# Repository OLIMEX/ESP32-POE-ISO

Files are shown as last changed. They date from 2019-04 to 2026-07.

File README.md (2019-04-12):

# ESP32-POE-ISO

ESP32-PoE-ISO is an IoT WIFI/BLE/Ethernet development board with Power-Over-Ethernet feature. The Si3402-B chip is IEEE 802.3-compliant, including pre-standard (legacy) PoE support. Perfect solution for Internet-of-Things that can be expanded with sensors and actuators taking power from Ethernet cable.

ESP32-POE-ISO has 3000VDC galvanic insulation from the Ethernet.

Product page: https://www.olimex.com/Products/IoT/ESP32/ESP32-POE-ISO/open-source-hardware

LICENSEE:

ESP32-POE-ISO is Open Source Hardware as per OSHWA.org definition. It is distributed with CERN OSH Licensee v1.2 which is available in the root directory of this repository.

The software examples for ESP32-POE-ISO are distributed with GPL v3 Licensee.

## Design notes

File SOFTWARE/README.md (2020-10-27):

The demo examples for ESP32-POE-ISO and ESP32-POE are the same. Visit the SOFTWARE page of ESP32-POE for examples. Here:

https://github.com/OLIMEX/ESP32-POE/tree/master/SOFTWARE/

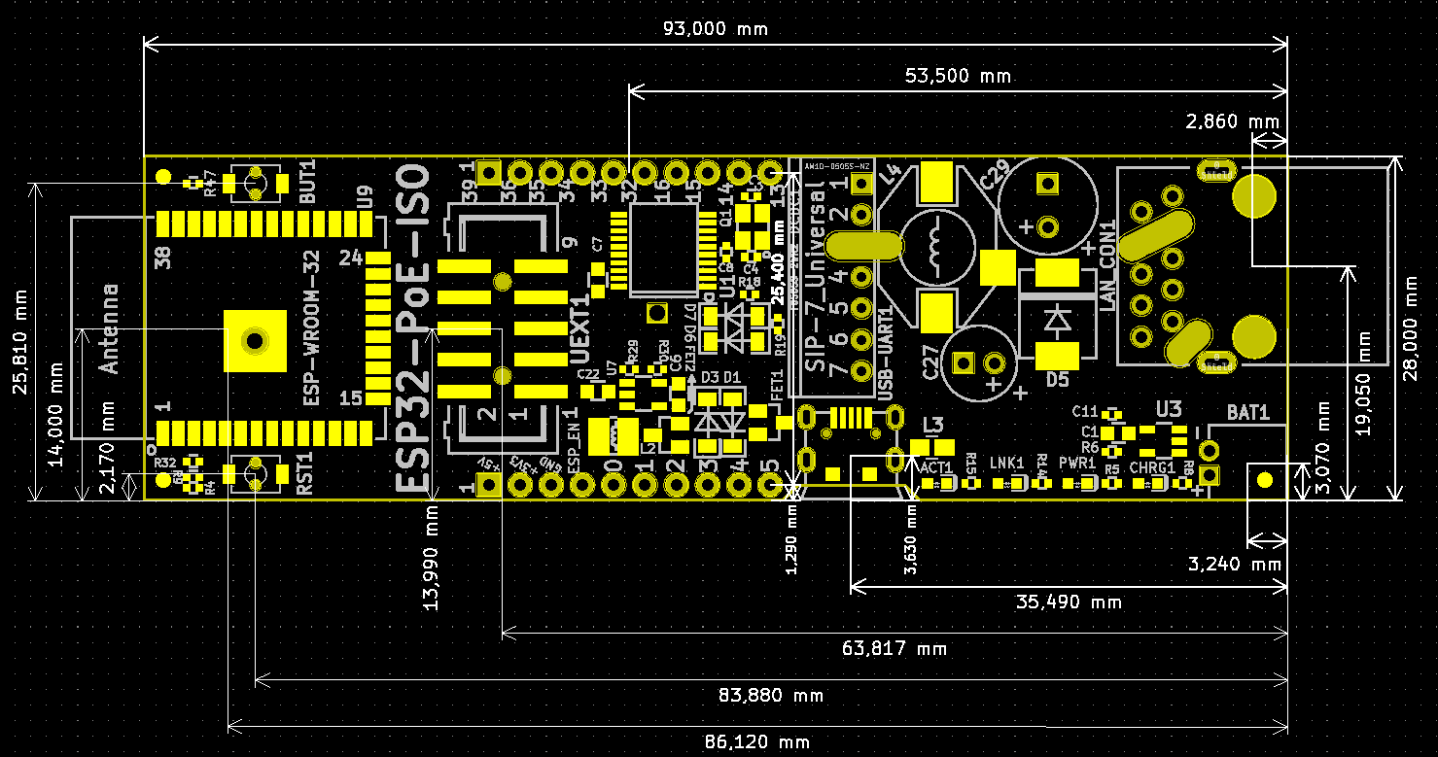
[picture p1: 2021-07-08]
HARDWARE/Dimensions/poe-iso-dimensions-1.png

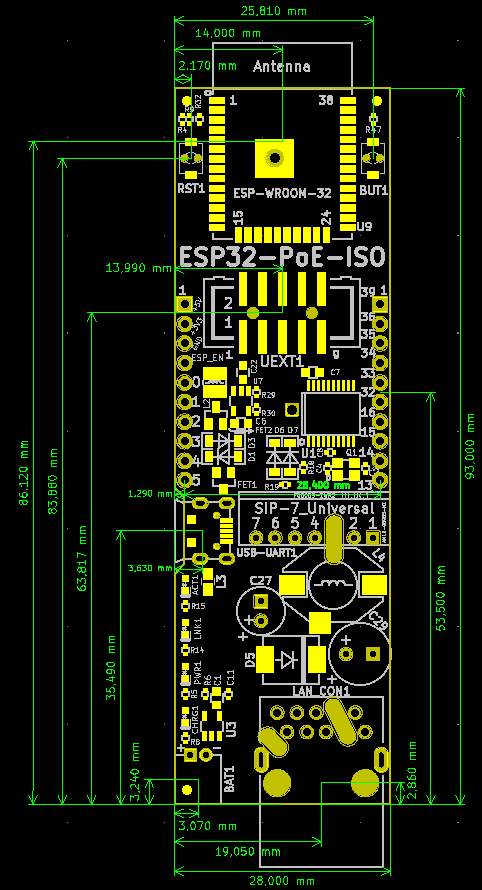
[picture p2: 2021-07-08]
HARDWARE/Dimensions/poe-iso-dimensions-2.png

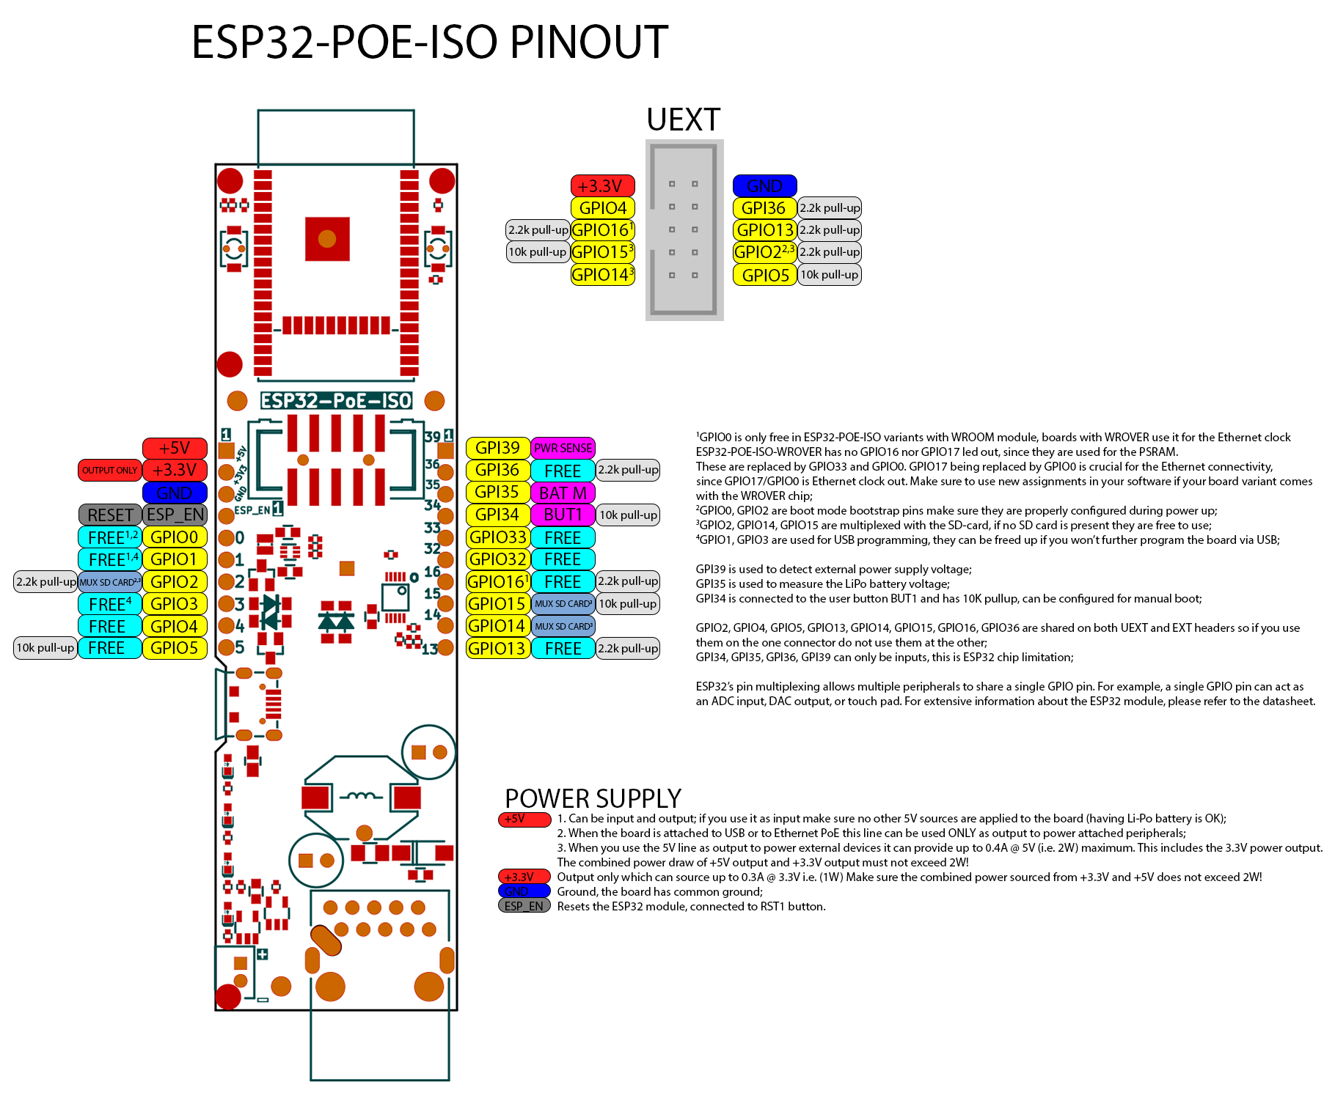
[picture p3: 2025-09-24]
DOCUMENTS/ESP32-POE-ISO-PINOUT.png

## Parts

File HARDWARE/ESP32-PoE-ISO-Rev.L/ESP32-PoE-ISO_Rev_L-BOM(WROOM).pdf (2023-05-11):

ESP32-PoE-ISO_Rev_L-BOM(WROOM) | 10/10/2022
Quantity | Designation | Package | Designator
1 | 0.03R/1%/R1206 | R1206 | R28
1 | 4.7R/R0402 | R0402 | R33
1 | 10R/R0402 | R0402 | R40
4 | 49.9R/1%/R0402 | R0402 | R10,R11,R12,R13
3 | 220R/R0402 | R0402 | R24,R46,R47
3 | 1k/R0402 | R0402 | R3,R20,R21
6 | 2.2k/R0402 | R0402 | R5,R8,R14,R15,R31,R35
3 | RA1206_(4X0603)_4B8_2.2k | R1206 | RM1,RM2,RM3
1 | 4.42k/1%/1/16W/R0402 | R0402 | R27
1 | 4.7k/R2512 | R2512 | R41
12 | 10k/R0402 | R0402 | R1,R2,R6,R18,R19,R25, R32,R36,R37,R39,R44,R48
1 | 10.5k/1%/R0402 | R0402 | R34
1 | 12.1k/1%/R0402 | R0402 | R26
1 | 24.9k/1%/R0402 | R0402 | R22
1 | 47k/R0402 | R0402 | R4
1 | 49.9k/1%/R0402 | R0402 | R30
1 | 56.2k/1%/R0402 | R0402 | R38
1 | 100k/R0402 | R0402 | R9
1 | 130k/R0402 | R0402 | R43
1 | 180k/1%/R0402 | R0402 | R23
1 | 220k/R0402 | R0402 | R29
2 | 470k/R0402 | R0402 | R7,R16
3 | FB0805/600R/2A | L0805 | L1,L3,L5
1 | 2.2uH/1.5A/DCR=72mR/ 20%/3.00x3.00x1.50mm/ CD32(NR3015T2R2M) | CD32 | L2
1 | 33uH/2.1A/DCR=0.1R/20%/ DBS135(PD3316MT330) | DBS135 | L4
1 | 12pF/50V/5%/COG/C0402 | C0402 | C25
2 | 27pF/50V/5%/C0G/C0402 | C0402 | C4,C5
1 | 1nF/50V/10%/X7R/C0402 | C0402 | C28
1 | 1nF/2000V/10%/X7R/C1206 | C1206 | C2
1 | 1.0nF/3kV/10%/X7R/SMD/1808 (VISHAY-VJ1808Y102KBHAT4X_ Farnell-2407291) | C1808 | C23
6 | 100nF/16V/10%/X7R/C0402 | C0402 | C8,C11,C14,C15, C16,C18
2 | 100nF/100V/10%/X7R/C0603 | C0603 | C12,C24
1 | 1uF/10V/20%/X5R/C0603 | C0603 | C31
1 | 2.2uF/6.3V/10%/X5R/C0603 | C0603 | C17
1 | 15uF/100V/20%/RM2.5/6.3x11mm (Farnell:1281844) | CPOL-RM2.5mm_ 6.3x11mm_PTH | C27
8 | 22uF/6.3V/20%/X5R/C0603 | C0603 | C1,C6,C7,C9,C10, C13,C19,C22
1 | 47uF/6.3V/20%/X5R/C0805 | C_0805_5MIL_DWS | C3
1 | 470uF/10V/20%/Low_ESR/ RM2.5/6.0x11mm | CPOL-RM2.5mm_ 6.3x11mm_PTH | C26
1 | BAT54C(SOT23-3) | SOT23-3 | D2
6 | 1N5819S4/SOD123 | SOD-123 | D1,D3,D4,D6,D7,D9
1 | ESDS314DBVR(SOT-23-5) | SOT-23-5 | TVS1
1 | SMAJ58A/SMA | SMA-KA | D10

ESP32-PoE-ISO_Rev_L-BOM(WROOM) | 10/10/2022
1 | SS510/100V/5A/0.85V/ DO214AB(SMC) | DO214AB(SMC) | D5
1 | LED/RED/0603 | LED0603 | PWR1
1 | LED/GREEN/0603 | LED0603 | LNK1
2 | LED/YELLOW/0603 | LED0603 | ACT1,CHRG1
2 | BC817-40(SOT23) | SOT23 | Q2,Q3
1 | LMUN2211LT1G(SOT-23) | SOT23 | T1
3 | WPM2015-3/TR | SOT23 | FET1,FET2,FET3
1 | BL4054B-42TPRN(SOT23-5) | SOT-23-5 | U3
1 | CH340T(SSOP20W) | SSOP-20W | U1
1 | ESP32-WROOM-32E | ESP32-WROVER(WROOM)-UNIVERSAL_MODULE | U6
1 | F0505S-2WR2(SIP-7) | SIP-7_Universal | DCDC1
1 | LAN8710A-EZC(QFN32) | QFN32 | U4
1 | SY8089AAAC(SOT23-5) | SOT-23-5 | U7
1 | Q12MHz/20pF/10ppm/4P/3.2x2.5mm | TSX-3.2x2.5mm | Q1
1 | TPS2376D(SO-8) | SOIC-8 | U2
1 | TX4138(ESOIC-8) | ESOIC-8 | U5
2 | IT1185AU2 | IT1185AU2 | BUT1,RST1
1 | DW02S | DW02S | BAT1
1 | MISB-SWMM-5B-LF(USB_MICRO) | MISB-SWMM-5B_LF | USB-UART1
1 | P-B-V-10-LF | GBH-254-SMT-10 | UEXT1
1 | RJP-003TC1(LPJ4112CNL) | RJP-003TC1(LPJ4112CNL) | LAN_CON1
1 | TFC-9P-1.7H(ATFFS150A01BR016) | uSD(TFC-9P-1.xH (ATFFS150A01BR016)) | MICRO_SD1
2 | NA/R0402 | R0402 | R17,R49
1 | NA(10R/R0402) | R0402 | R42
1 | NA(1.0nF/3kV/10%/X7R/SMD/1808 (VISHAY-VJ1808Y102KBHAT4X_ Farnell-2407291)) | C1808 | C20
1 | NA(100nF/16V/10%/X7R/C0402) | C0402 | C29
1 | NA(10uF/6.3V/20%/X5R/C0603) | C0603 | C21
2 | NA(GG0402052R542P) | D0402 | TVS2,TVS3
1 | NA(SMBJ6.0A) | DO214AA | D8
1 | NA(SN74LVC1G04DBVR(SOT23-5)) | SOT-23-5 | U8
2 | NS(HN1x10) | HN1x10 | EXT1,EXT2

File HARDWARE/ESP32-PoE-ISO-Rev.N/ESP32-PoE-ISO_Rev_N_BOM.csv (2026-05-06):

Id | Designator | Footprint | Quantity | Designation | Supplier and ref
1 | FID3,FID2,FID6,FID5 | Fiducial1x3 | 4 | Fiducial
2 | R32,R6,R18,R19,R48,R37,R39,R2,R25,R1,R36 | R_0402_5MIL_DWS | 11 | 10k/R0402
3 | BUT1,RST1 | IT1185AU2_V2 | 2 | IT1185AU2
4 | C1,C6,C22,C7,C19,C10,C9,C13 | C_0603_5MIL_DWS | 8 | 22uF/6.3V/20%/X5R/C0603
5 | U3 | SOT-23-5 | 1 | TP4054-42-SOT25-R(SOT23-5)
6 | R4 | R_0402_5MIL_DWS | 1 | 47k/R0402
7 | R9 | R_0402_5MIL_DWS | 1 | 100k/R0402
8 | CHRG1,ACT1 | LED_0603_KA | 2 | LED/YELLOW/0603
9 | PWR1 | LED_0603_KA | 1 | LED/RED/0603
10 | R5,R14,R15,R8,R31,R35 | R_0402_5MIL_DWS | 6 | 2.2k/R0402
11 | FID1,FID7,FID4,FID8 | Fiducial1x3_Paste | 4 | Fiducial
12 | C11,C8,C18,C16,C15,C14 | C_0402_5MIL_DWS | 6 | 100nF/10V/20%/X5R/C0402
13 | FET1,FET2,FET3 | SOT23 | 3 | IRLML6402TRPbF
14 | L2 | L_2016_MM | 1 | 1.0uH/4.2A/DCR=35mR/20%/2.00x1.60x1.00mm/L2016(PIM201610-1R0MTS00)
15 | R30 | R_0402_5MIL_DWS | 1 | 49.9k/1%/R0402
16 | R29 | R_0402_5MIL_DWS | 1 | 220k/R0402
17 | U7 | SOT-563-6 | 1 | TPS62A02ADRLR(SOT-563-6)
18 | LNK1 | LED_0603_KA | 1 | LED/GREEN/0603
19 | L3,L5,L1 | L_0805_5MIL_DWS | 3 | FB0805/600R/2A
20 | DCDC1 | SIP-7_Universal | 1 | F0505S-2WR2(SIP-7)
21 | C27 | CPOL-RM2.5mm_6.3x11mm_PTH | 1 | 15uF/100V/20%/RM2.5/6.3x11mm(Farnell:1281844)
22 | U1 | MSOP-10_Pitch-0.5mm_3.00x3.00x1.00mm | 1 | CH340X(MSOP-10)
23 | D6,D7,D3,D1,D4,D9 | SOD-123_1C-2A_KA | 6 | 1N5819S4/SOD123
24 | R17,R49 | R_0402_5MIL_DWS | 2 | NA/R0402
25 | USB-UART1 | USB-MICRO_MISB-SWMM-5B_LF | 1 | MISB-SWMM-5B-LF(USB_MICRO)
26 | TVS1 | SOT-23-5 | 1 | ESDS314DBVR(SOT-23-5)
27 | LAN_CON1 | RJP-003TC1(LPJ4112CNL) | 1 | RJP-003TC1(LPJ4112CNL)
28 | UEXT1 | GBH-254-SMT-10 | 1 | P-B-V-10-LF
29 | R28 | R_1206_5MIL_DWS | 1 | 0.03R/1%/R1206
30 | L4 | DBS135 | 1 | 33uH/2.1A/DCR=0.1R/20%/DBS135(PD3316MT330)
31 | C26 | CPOL-RM2.5mm_6.3x11mm_PTH | 1 | 470uF/10V/20%/Low_ESR/RM2.5/6.0x11mm
32 | R47,R46,R24,R44 | R_0402_5MIL_DWS | 4 | 220R/R0402
33 | C24,C12 | C_0603_5MIL_DWS | 2 | 100nF/100V/10%/X7R/C0603
34 | D10 | SMA-KA | 1 | SMAJ58A/SMA
35 | U6 | ESP32-WROVER_MODULE | 1 | ESP32-WROOM-32E-N4
36 | MH1,MH2,MH3 | NPTH_2.2mm | 3 | Mounting_Hole_NPTH
37 | BAT1 | LIPO_BAT_VERTICAL_DW02S | 1 | DW02S
38 | R43 | R_0402_5MIL_DWS | 1 | 4.7k/R0402
39 | C30 | C_0402_5MIL_DWS | 1 | NA(120pF/50V/5%/C0G/C0402)
40 | EXT2,EXT1 | HN1x10 | 2 | NS(HN1x10)
41 | R40 | R_0402_5MIL_DWS | 1 | 10R/R0402
42 | RM3,RM2,RM1 | R_MATRIX_4 | 3 | RA1206_(4X0603)_4B8_2.2k
43 | C2 | C_1206_5MIL_DWS_ISO | 1 | 1nF/2000V/10%/X7R/C1206
44 | C20 | C_1808(4520)_5MIL_DWS_ISO | 1 | NA(1.0nF/3kV/10%/X7R/SMD/1808(VISHAY-VJ1808Y102KBHAT4X_Farnell-2407291))
45 | C23 | C_1808(4520)_5MIL_DWS_ISO | 1 | 1.0nF/3kV/10%/X7R/SMD/1808(VISHAY-VJ1808Y102KBHAT4X_Farnell-2407291)
46 | R3,R20,R21 | R_0402_5MIL_DWS | 3 | 1k/R0402
47 | C21 | C_0603_5MIL_DWS | 1 | NA(10uF/6.3V/20%/X5R/C0603)
48 | C17 | C_0603_5MIL_DWS | 1 | 2.2uF/6.3V/10%/X5R/C0603
49 | U4 | QFN32_EP(33)_5.00x5.00x0.90mm_Pitch_0.50mm | 1 | LAN8710A-EZC(QFN32)
50 | T1 | SOT23 | 1 | LMUN2211LT1G(SOT-23)
51 | R12,R11,R10,R13 | R_0402_5MIL_DWS | 4 | 49.9R/1%/R0402
52 | R16,R7 | R_0402_5MIL_DWS | 2 | 470k/R0402
53 | R26 | R_0402_5MIL_DWS | 1 | 12.1k/1%/R0402
54 | Q3,Q2 | SOT23 | 2 | BC817-40(SOT23)
55 | D2 | SOT23-3 | 1 | BAT54C(SOT23-3)
56 | TVS2,TVS3 | D_0402_5MIL_DWS | 2 | NA(GG0402052R542P)
57 | C3 | C_0805_5MIL_DWS | 1 | 47uF/6.3V/20%/X5R/C0805
58 | D8 | DO214AA_1(K)-2(A) | 1 | NA(SMBJ6.0A)
59 | C25 | C_0402_5MIL_DWS | 1 | 12pF/50V/5%/COG/C0402
60 | R22 | R_0402_5MIL_DWS | 1 | 24.9k/1%/R0402
61 | R23 | R_0402_5MIL_DWS | 1 | 1.27k/1%/62.5mW/R0402
62 | C28 | C_0402_5MIL_DWS | 1 | 1nF/50V/10%/X7R/C0402
63 | R33 | R_0402_5MIL_DWS | 1 | 4.7R/R0402
64 | D5 | DO214AB(SMC)_1(K)-2(A) | 1 | SS510/100V/5A/0.85V/DO214AB(SMC)
65 | R41,R27 | R_2512_MM_DWS | 2 | 9.1k/1W/R2512
66 | U5 | ESOIC-8 | 1 | TX4138(ESOIC-8)
67 | R34 | R_0402_5MIL_DWS | 1 | 10.5k/1%/R0402
68 | C29 | C_0402_5MIL_DWS | 1 | NA(100nF/10V/20%/X5R/C0402)
69 | U8 | SOT-23-5 | 1 | NA(SN74LVC1G04DBVR(SOT23-5))
70 | R42 | R_0402_5MIL_DWS | 1 | NA(10R/R0402)
71 | C31 | C_0603_5MIL_DWS | 1 | 1uF/10V/10%/X5R/C0603
72 | MICRO_SD1 | uSD(TFC-9P-1.xH(ATFFS150A01BR016)) | 1 | TFC-9P-1.7H(ATFFS150A01BR016)
73 | R38 | R_0402_5MIL_DWS | 1 | 56.2k/1%/R0402
74 | U2 | ESOIC-8 | 1 | TPS2378DDAR(HSOIC-8)
75 | D11 | DO214AA_1(K)-2(A) | 1 | SMBJ5.0A

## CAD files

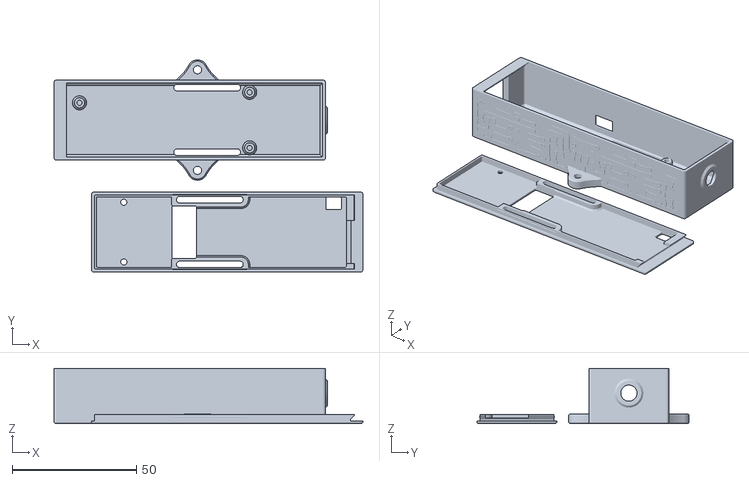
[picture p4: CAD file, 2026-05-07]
HARDWARE/3D printed case/esp32-poe-iso-ea-f_v12.stl
124.2 x 85.3 x 22.3

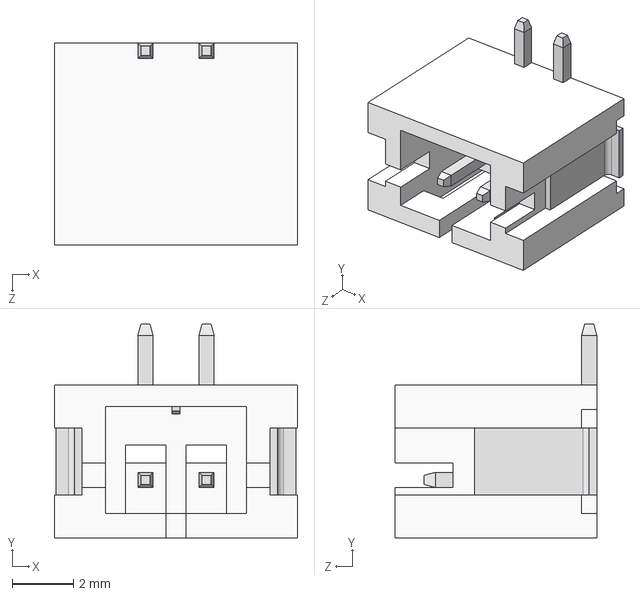
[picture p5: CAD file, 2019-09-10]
HARDWARE/ESP32-PoE-ISO-Rev.I/3d/JST_B2B-PH-SM4-TB(DW02R).step
7.95 x 7.00 x 6.60 mm

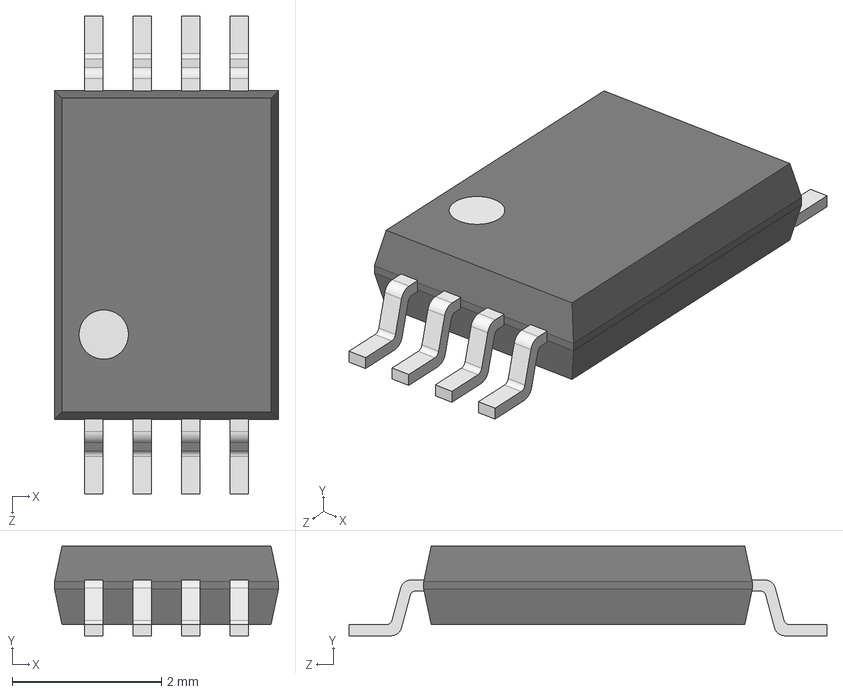
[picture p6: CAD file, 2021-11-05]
HARDWARE/ESP32-PoE-ISO-Rev.J/3d/TSSOP-8_P0.65mm.STEP
3.00 x 1.20 x 6.40 mm
_X2_041A043E0440043F04430441_X0_
_X2_041C04350442043A0430_X0_
_X2_041D043E0436043A0430_X0_ x 4

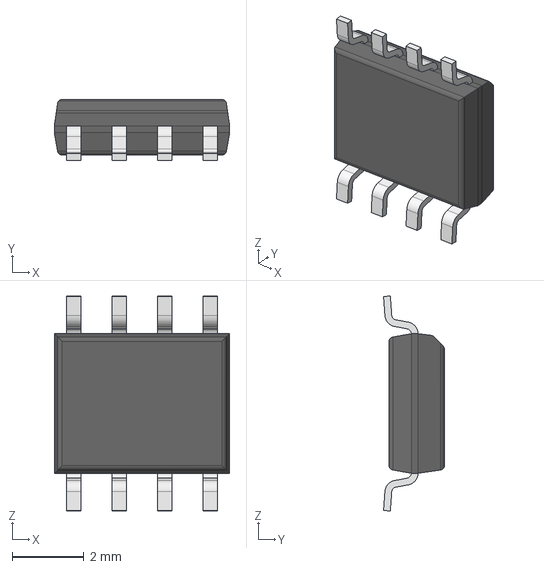
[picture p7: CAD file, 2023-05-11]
HARDWARE/ESP32-PoE-ISO-Rev.L/3d/lm358ad.stp
4.90 x 1.70 x 6.01 mm

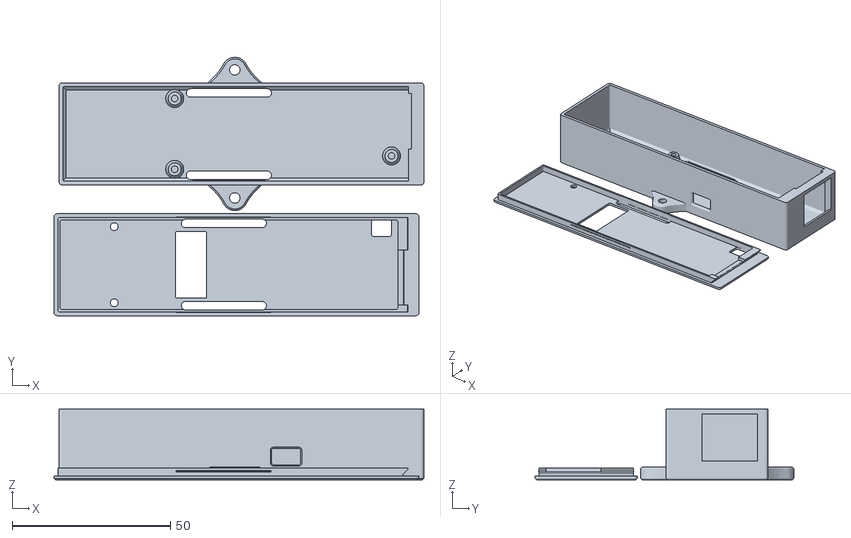
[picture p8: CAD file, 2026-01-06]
HARDWARE/3D printed case/olimex_esp32-Poe_iso_f.stl
116.7 x 81.6 x 22.3

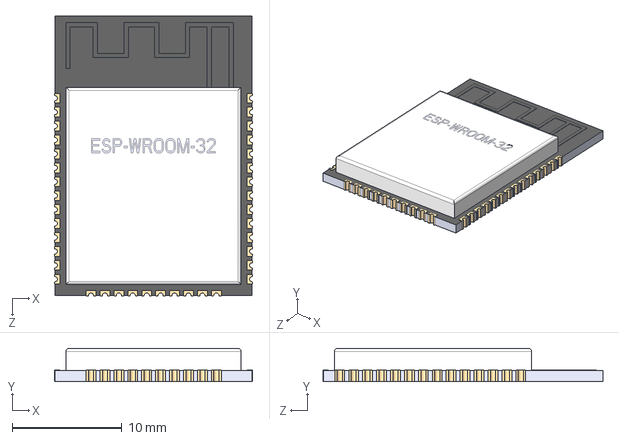
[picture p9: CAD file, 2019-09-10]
HARDWARE/ESP32-PoE-ISO-Rev.I/3d/esp-wroom-32.step
18.1 x 3.04 x 25.5 mm

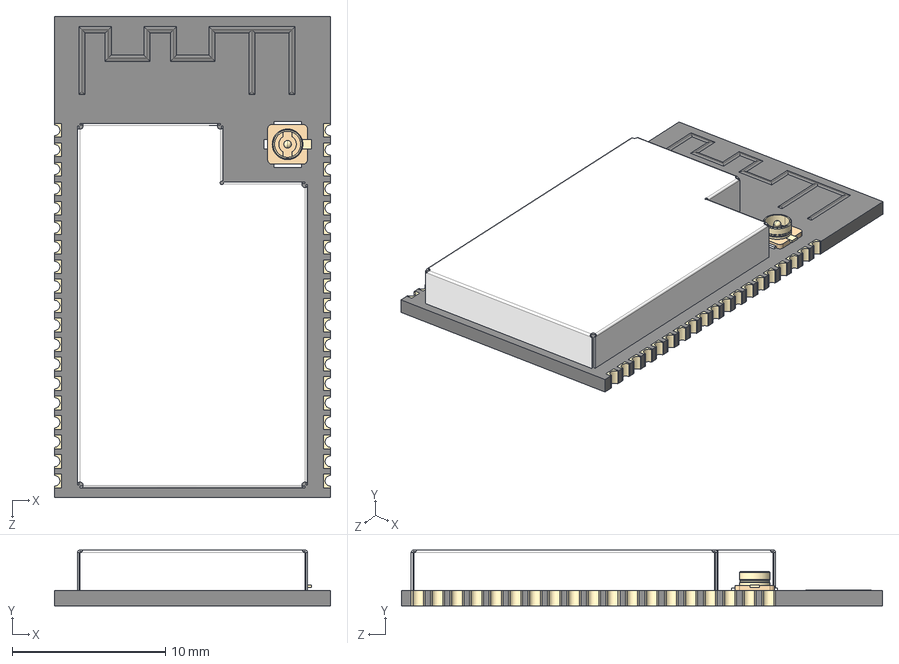
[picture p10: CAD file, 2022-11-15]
HARDWARE/ESP32-PoE-ISO-Rev.L/3d/ESP32-WROVER-I-56544.STEP
18.0 x 3.65 x 31.4 mm

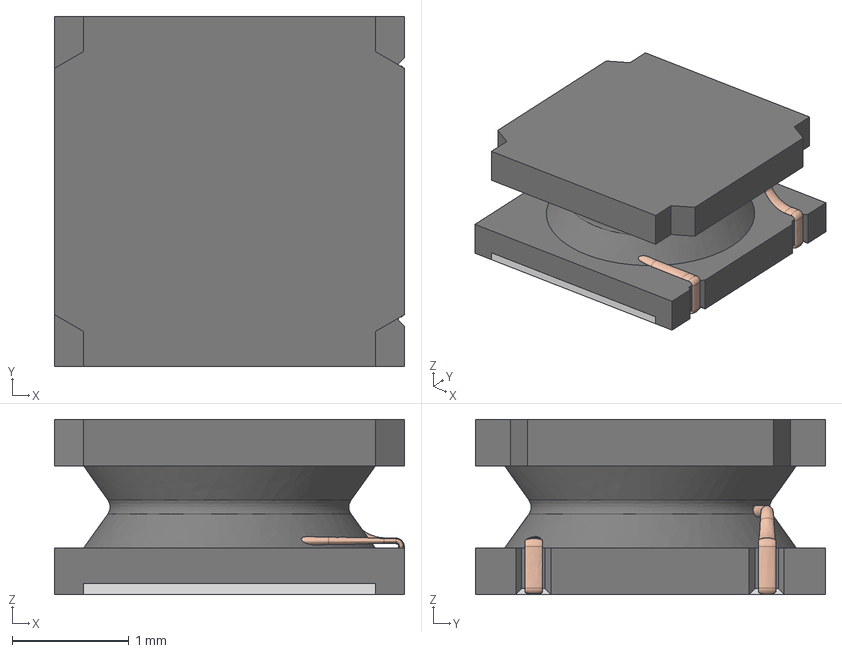
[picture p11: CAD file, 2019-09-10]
HARDWARE/ESP32-PoE-ISO-Rev.L/3d/L-CD32_shielded.step
3.00 x 3.00 x 1.50 mm

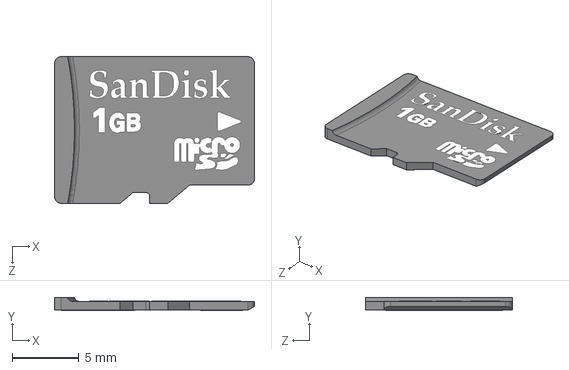
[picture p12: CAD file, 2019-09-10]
HARDWARE/ESP32-PoE-ISO-Rev.L/3d/Micro_SD_card.step
15.0 x 0.975 x 11.0 mm

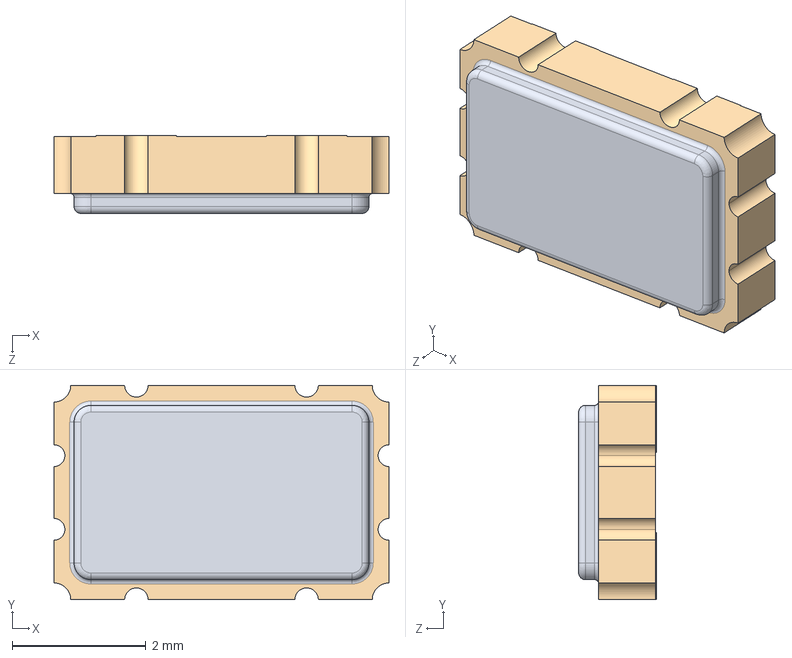
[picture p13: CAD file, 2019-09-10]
HARDWARE/ESP32-PoE-ISO-Rev.L/3d/QSG5032.step
5.00 x 3.20 x 1.16 mm

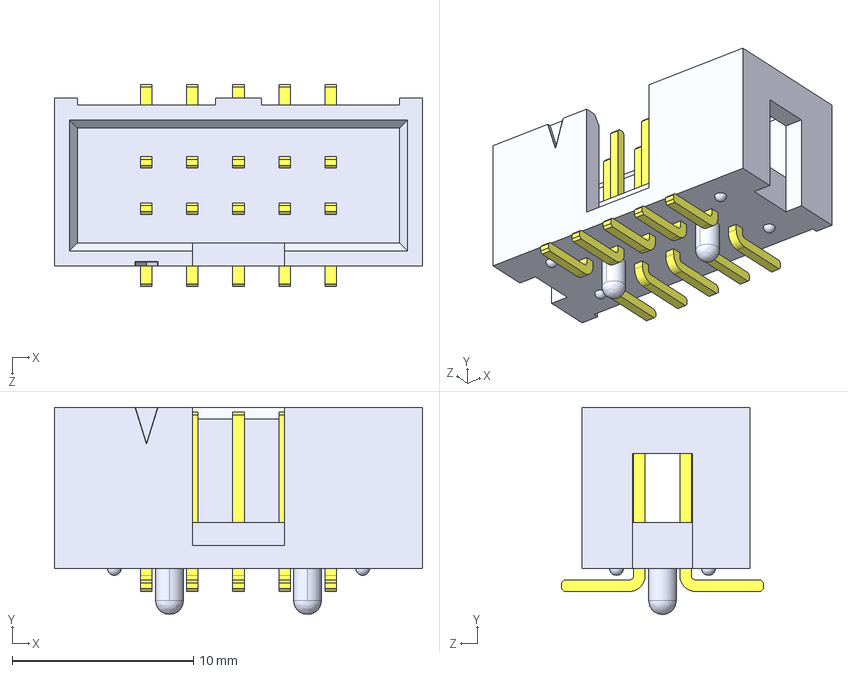
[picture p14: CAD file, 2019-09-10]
HARDWARE/ESP32-PoE-ISO-Rev.L/3d/UEXT-SMD.STEP
20.3 x 11.4 x 11.2 mm
User Library-HTST-105-01-F-DV-A__HTST-105-01-DV-A_header
User Library-HTST-105-01-F-DV-A__HTST-First_Position_Indicator
User Library-HTST-105-01-F-DV-A__T-1S6-05-01-DV_

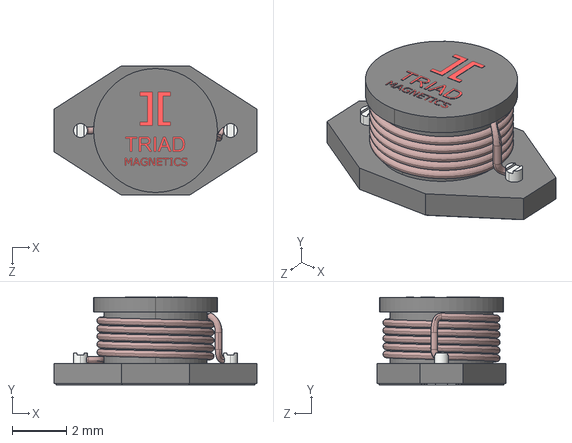
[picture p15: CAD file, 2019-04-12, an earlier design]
HARDWARE/ESP32-PoE-ISO-Rev.B/3d/L_AX97-103R3.step
7.49 x 3.24 x 4.78 mm

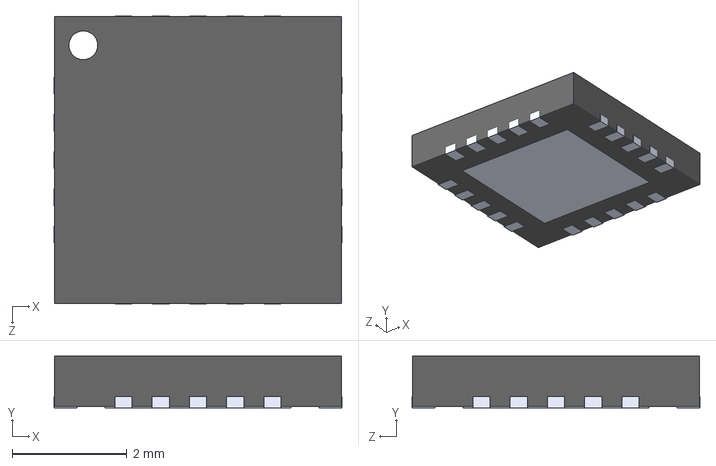
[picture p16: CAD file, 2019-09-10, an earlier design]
HARDWARE/ESP32-PoE-ISO-Rev.D/3d/QFN-20_5x5x0_9mm.step
5.02 x 0.9 x 5.02 mm

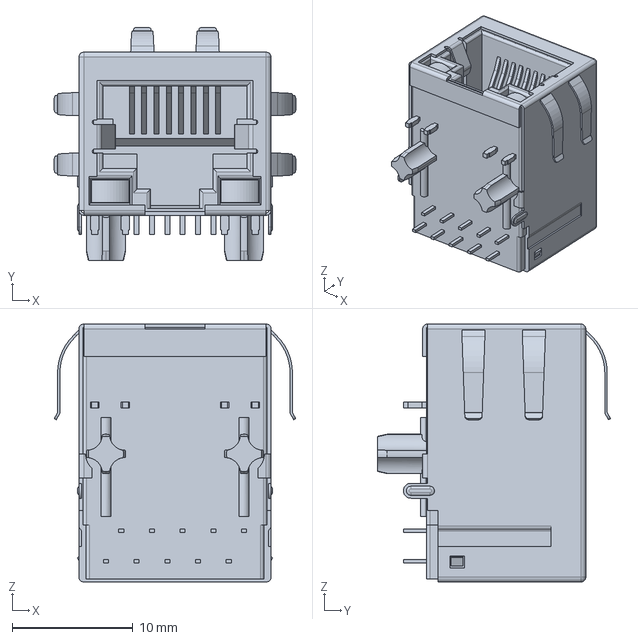
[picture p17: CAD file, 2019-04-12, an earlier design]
HARDWARE/ESP32-PoE-ISO-Rev.B/3d/RJ45_GB_LEDS.stp
20.0 x 19.3 x 21.4 mm

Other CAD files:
HARDWARE/ESP32-PoE-ISO-Rev.D/3d/Cap_8x11_5x3_5mm.step
HARDWARE/ESP32-PoE-ISO-Rev.B/3d/SOT-23-5.step
HARDWARE/ESP32-PoE-ISO-Rev.B/3d/Cap_PTH_6_3x11x2_5mm.step
HARDWARE/ESP32-PoE-ISO-Rev.B/3d/BAT54.step
HARDWARE/ESP32-PoE-ISO-Rev.B/3d/CD32_inductor.step
HARDWARE/ESP32-PoE-ISO-Rev.B/3d/Cap_8x11_5x3_5mm.step
HARDWARE/ESP32-PoE-ISO-Rev.B/3d/DO-214AB_SMC.step
HARDWARE/ESP32-PoE-ISO-Rev.B/3d/JST_B2B-PH-SM4-TB(DW02R).step
HARDWARE/ESP32-PoE-ISO-Rev.B/3d/Micro_SD_card.step
HARDWARE/ESP32-PoE-ISO-Rev.B/3d/QFN-20_5x5x0_9mm.step
HARDWARE/ESP32-PoE-ISO-Rev.B/3d/QFN32_5x5.step
HARDWARE/ESP32-PoE-ISO-Rev.B/3d/QSG5032.step
HARDWARE/ESP32-PoE-ISO-Rev.B/3d/SIP-7.step
HARDWARE/ESP32-PoE-ISO-Rev.B/3d/SMD_Ceramic_Capacitors_1808(4520).step
HARDWARE/ESP32-PoE-ISO-Rev.B/3d/SOD123.step
HARDWARE/ESP32-PoE-ISO-Rev.B/3d/SOT-23.step
HARDWARE/ESP32-PoE-ISO-Rev.B/3d/UEXT-SMD.STEP
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

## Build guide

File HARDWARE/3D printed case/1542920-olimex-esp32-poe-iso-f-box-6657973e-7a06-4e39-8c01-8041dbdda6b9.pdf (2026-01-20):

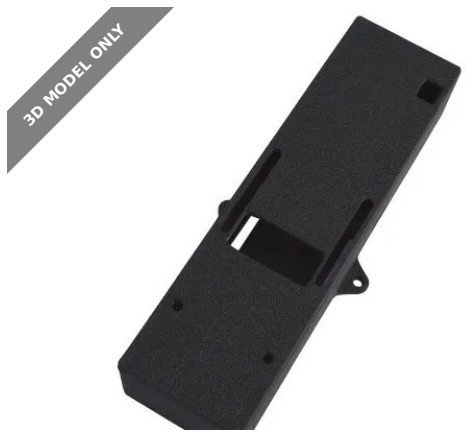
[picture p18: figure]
3D MODEL ONLY

## Summary

Plastic box for ESP32-POE-ISO

Gadgets (https://printables.com/model?categoryId=21) > Computers (https://printables.com/model?categoryId=27)

Tags: | olimex | olimexesp32 | olimexpoeiso

BOX-ESP32-POE-ISO-F has two fixing lugs which allow 3 mm screws to fix the box to a flat surface. Suitable for ESP32-POE-ISO, ESP32-POE-ISO-16MB, ESP32-POE-ISO-16MB-IND, and ESP32-POE-ISO-IND.

Print in PLA Black Matt for best results.

3 walls, 4 top and 4 bottom layers
0.2 layer height

Link to the ESP32 board: https://www.olimex.com/Products/IoT/ESP32/ESP32-POE-ISO/open-source-hardware (https://www.olimex.com/Products/IoT/ESP32/ESP32-POE-ISO/open-source-hardware)

Link to the box page: https://www.olimex.com/Products/IoT/ESP32/BOX-ESP32-POE-ISO/ (https://www.olimex.com/Products/IoT/ESP32/BOX-ESP32-POE-ISO/)

Link to the github page of the project: https://github.com/OLIMEX/ESP32-POE-ISO (https://github.com/OLIMEX/ESP32-POE-ISO)

experify3d (https://printables.com/@experify3d_271079)

## Olimex ESP32-POE-ISO-F box

VIEW IN BROWSER (https://printables.com/model/1542920-olimex-esp32-poe-iso-f-box)

updated 5. 1. 2026 | published 5. 1. 2026

•
•

## Model files

## License

This work is licensed under a GNU

General Public License v3.0 (https://www.gnu.org/licenses/gpl-3.0.html)

✖ | Sharing without ATTRIBUTION
✔ | Remix Culture allowed
✔ | Commercial Use
✔ | Meets Open Definition
ℹ | Share under the same license olimex_esp32-poe_iso_f.stl

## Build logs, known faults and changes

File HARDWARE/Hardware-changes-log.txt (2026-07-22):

Notable hardware changes for ESP32-PoE-ISO

Hardware revision N1:

---

Overview: CH340X patch to prevent accidental overvoltage at reset. The board uses same PCB as revision N just has manually applied patch.

Notable changes:

1. Added a patch to prevent overvoltage of CH340 convertor. Added resistor 10k/1206 over the RXD pin of CH340 to GND. The patch is near D7.

Hardware revision N:

---

Overview: reliability improvements

Notable changes:

1. Added D11 to protect C26 (it was a hardware patch applied in M1, now fixed by design);
2. Moved a couple of components to fit D11 - DCDC1, L4, C27, C26, R1, C19;
3. Added R44(220R) between PG of the 3.3V regulator and ESP_EN so it works better at power up and reset, this was suggested by a customer;
4. Moved U2 20mils towards the center of the board. Changed the placement of the isolated part of the circuit components to fit for the U2 new place.

Hardware revision M1:

---

Overview: reliability improvements

Notable changes:

1. WPM2015-3/TR changed with IRLML6402TRPbF;

2. Added D11-SMBJ5.0A as patch, this will increase reliability.

Hardware revision M:

---

Overview: major changes

Notable changes:

1. The entire project was converted from KiCad5 to KiCad7!
2. U3 value changed from BL4054B-42TPRN(SOT23-5) to TP4054-42-SOT25-R(SOT23-5);
3. U7 changed from SY8089AAAC(SOT23-5) to TPS62A02ADRLR(SOT-563-6);
4. Added C30 - NA(120pF/50V/5%/C0G/C0402);
5. L2 changed from 2.2uH/1.5A/DCR=72mR/20%/3.00x3.00x1.50mm/CD32(NR3015T2R2M) to 1.0uH/4.2A/DCR=35mR/20%/2.00x1.60x1.00mm/L2016(PIM201610-1R0MTS00);
6. U2 changed from TPS2376D(SO-8) to TPS2378DDAR(HSOIC-8);
7. Deleted R27, 4.42k/1%/1/16W/R0402;
8. R23 changed from 180k/1%/R0402 to 1.27k/1%/62.5mW/R0402;
9. Deleted R43, 130k/R0402;
10. Deleted R44, 10k/R0402;
11. R41 value changed from 4.7k/R2512 to 9.1k/1W/R2512;
12. R27, 9.1k/1W/R2512, was added in parallel to R41;
13. Description for Rmps was added in the schematic;
14. U1 was changed from CH340T(SSOP20W) to CH340X(MSOP-10);
15. C4 and C5, 27pF/50V/5%/C0G/C0402, were deleted;
16. Q1, Q12MHz/20pF/10ppm/4P/3.2x2.5mm, was deleted;
17. Added R43, 4.7k/R0402;
18. Several texts improved;
19. U6's package was changed from "OLIMEX_Cases-FP:ESP32-WROVER(WROOM)-UNIVERSAL_MODULE" to "OLIMEX_Cases-FP:ESP32-WROVER_MODULE" for here the pads are corrected;
20. All packages are with updated 3Ds to the ones in step format instead of wrl format.

Hardware revision L:

---

Overview: minor change

Notable changes:

1. U2 changed from TPS2376PW(TSSOP-8) to TPS2376D(SO-8), because of this, U2's package also changed from TSSOP-8 to SOIC-8_1.75mm;

---

Hardware revision K:

---

Overview: minor design improvements

Notable changes:

1. Added voltage divider R43(130k/R0402) / R44(10k/R0402) to set the undervoltage lockout (UVLO) when TPS2376PW is used;
2. U2 changed from TPS2375PW(TSSOP-8) to TPS2376PW(TSSOP-8).

---

Hardware revision J (internal, not released)

Overview: Major layout changes - bigger size, added mount holes, a lot of other components (buttons, SD card, etc) moved

Notable changes:

1. The board PCB extended with 5mm from 28x93mm to 28x98mm;
2. Added U8(SN74LVC1G04DBVR(SOT23-5)) and C29(100nF/16V/10%/X7R/C0402), for WROVER-module compatibility. When WROVER is populated, for GPIO17 is then NC and Ethernet's clock will be supplied by GPIO0;
3. Added R42(10R/R0402) to connect, when populated, I2C-SCL to GPIO33, for WROVER-module compatibility. When WROVER is populated, GPIO16 is also NC;
4. Added three mounting holes, 2.2mm drills;
5. BAT1 changed from DW02R to DW02S and rotated;
6. Both buttons, SD card and many other components moved too;
7. Added numbering of the layers: 1-F.Cu, 2-In1.Cu, 3-In2.Cu, 4-B.Cu.

---

Hardware revision I:

---

1. No significant changes to revision H, just PCB optimizations for improved manufacturing yield. 

---

Hardware revision H:

1. R41(4.7k/R2512) now placed on the PCB.

---

Hardware revision G1 (minor patch):

1. Added resistors R41 and R42(both 3.9k/R1206). Visible in the schematics.

---

Hardware revision G (major PoE redesign):

1. The PoE chip Si3402-B-GM(QFN-20_5x5mm) changed with TPS2375PW(TSSOP-8) + TX4138(ESOIC-8)! Because of this change,
many components are changed too:

Deleted: U8, C12, C25, C26, R33, R34, R38, C29, L6, R41, R42, R43, R45, and C30

In the schematic added the following components:

470uF/10V/20%/Low_ESR/RM2.5/6.0x11mm as C26
TX4138(ESOIC-8) as U5
TPS2375PW(TSSOP-8) as U2
56.2k/1%/R0402 as R38
10.5k/1%/R0402 as R34
4.7R/R0402 as R33
0.03R/1%/R1206 as R28
4.42k/1%/1/16W/R0402 as R27
180k/1%/R0402 as R23
24.9k/1%/R0402 as R22
SMAJ58A/SMA as D10
12pF/50V/5%/COG/C0402 as C25
100nF/100V/20%/X7R/C1206 as C12

2. Added 1, 2, 3, and 4 in the layers from top to bottom;
3. Many references changed in size from 25x25mils to 30x30mils;
4. T1's symbol changed with the real LMUN2211LT1G(SOT-23)'s symbol i.e. 10k/10k input divider;
5. C12 and C24 changed from 100nF/100V/20%/X7R/C1206 to 100nF/100V/10%/X7R/C0603.

---

Hardware revision F  (internal, unreleased)

1. RM2 moved 25mils away from U4; 
2. C14 moved 25mils away from U4;
3. C21 moved 30mils away from U4;
4. R25 moved 35mils away from U4;
5. C13 moved 38*5=190mils away from U4;
6. C15 moved at direction X=12*5=60mils and Y=3*5=15mils away from U4;
7. C16 moved 20mils away from U4;
8. R26 moved 13*5=65mils away from U4;
9. R33, C25 and C26 moved 40mils from U8;
10. R38 moved 20mils away from U8;
11. R34 moved 30mils away from U8;
12. R41 moved 30mils away from U8;
13. R42 moved 30mils away from U8 and rotated.

---

Hardware revision E (internal, unreleased):

1. Added TVS1, ESDS314DBVR(SOT-23-5) to protect the Ethernet's PHY from ESD and other transient voltages;
2. D8(SMBJ6.0A) inserted into the board, routed and changed to NA, i.e. NA(SMBJ6.0A);
3. Local changes to ESP32-module pads;
4. Spare2 now routed trough the top;
5. C20 removed - value set to NA(1.0nF/3kV/10%/X7R/SMD/1808(VISHAY-VJ1808Y102KBHAT4X_Farnell-2407291));
6. T1 value change in value from DTC114YKA(SOT-23) to LMUN2211LT1G(SOT-23);
7. Added pads of TVS2 and TVS3, NA(GG0402052R542P), just in case

---

Hardware revision D3:

1. C20 changed from 1.0nF/3kV/10%/X7R/SMD/1808(VISHAY-VJ1808Y102KBHAT4X_Farnell-2407291) to NA(1.0nF/3kV/10%/X7R/SMD/1808(VISHAY-VJ1808Y102KBHAT4X_Farnell-2407291));
2. Soldered 2 x TVS-a, to protect TXP/TXN and RXP/RXN of LAN8710A from overvoltage - TVS1 and TVS2(GG0402052R542P);

---

Hardware revision D2 (released):

1. Connected pins 7 and 8 of LAN connector togther with SHIELD pin. 
2. Removed C20 - it is redundadnt. 

---

Hardware revision D1 (internal, unreleased):

1. Tried to add D8(SMBJ6.0A) between +5V and GND of DCDC, as extra protection for LAN chip from voltage spikes. It doesn't help in the end, so it will no longer be placed.

---

Hardware revision D:

1. Added C31(1uF/10V/20%/X5R/C0603) to the ESP_EN pin;
2. R32 changed from 470k/R0402 to 10k/R0402;
3. R25 moved 25 mils away from the chip;
4. R33 rotated and moved a away from the chip;
5. C14 moved 15 mils away from the chip;
6. CE sign added.

---

Hardware revision C:

1. Improved a couple of footprints;
2. R44, NA/R0402 - deleted to free up board space;
3. Value of U9 changed from ESP-WROOM-32 to ESP32-WROOM-32D-4MB.

---

Hardware revision B:

Initial release

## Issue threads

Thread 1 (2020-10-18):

What is the ESP 32 Version number

pranaysharma, 2020-10-18:
Hi We want to use [secureboot v2](https://docs.espressif.com/projects/esp-idf/en/latest/esp32/security/secure-boot-v2.html) feature in ESP32-POE-ISO-IND but we are not sure if the ESP32 inside is ESP32 Revision 3 or not.
Could someone help?

DanKoloff, 2020-10-19:
Do you already own ESP32-POE-ISO or are you looking forward to buy one?

pranaysharma, 2020-10-24:
Yes I own ESP32-POE-ISO-IND

DanKoloff, 2020-10-24:
There is a hello world example in Arduino for ESP32 that prints it, check here:

https://github.com/espressif/esp-idf/blob/master/examples/get-started/hello_world/main/hello_world_main.c

Closed 2021-12-07.

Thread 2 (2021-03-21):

3x4 Keypad problem

enschy, 2021-03-21:
I have problems to get an 4x4 Keypad working. Like this Example:
https://diyi0t.com/keypad-arduino-esp8266-esp32/
With the NodeMCU board works this, but with the ESP32 POE not. I have tested many GPIO combinations.

byte rowPins[ROWS] = {4, 3, 2, 1};
byte colPins[COLS] = {13, 14, 15, 16};

Whats wrong?
Thanks

DanKoloff, 2021-03-22:
So it is working with ESP8266 board but not with ESP32 board? Maybe the code library is not compatible or requires something extra.

Closed 2021-04-26.

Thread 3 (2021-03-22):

Two devices bricked after connecting Ethernet (with autosensing POE) while USB connected

lucaelin, 2021-03-22:
I am working on a project involving the ESP32-POE-ISO Rev.D
I have a Waveshare epaper module connected via UEXT SPI, Ethernet with POE and USB on the device. During testing both my boards failed within four weeks after purchase. Both of them are now failing to connect to ethernet. I have tested multiple different networks and switches now, none of which establish a proper connection with any of the two boards.

The project started out with one board, about a month ago. It worked like charm and about one week in I ordered a second one. The firmware is using the ESP-IDF and is derived from the Ethernet-Example code. Additionally it enables promiscuous mode on the chip and registers a custom ethernet-frame handler, so I can log any incoming packet on the chip (assuming there is existing broadcast traffic coming from the switch network as my project does not send any frames itself). The switch I usually connect to is in my office and a Ubiquity Unifi 8-Port POE auto-sensing swtich. It worked fine for about two weeks.

Soon I was testing some software reset behavior and repeatedly connecting and disconnecting the RJ45. Not too fast though, I always had to wait a couple of seconds for the epaper display to properly refresh. At some point the software stopped calling my frame-handler and the link LED on the board was constantly lit, even after disconnecting the RJ45. After a powercycle the device only sometimes establishes a link and if it does, the link indicator remains on even if the rj45 is disconnected. Most of the time, it does not establish a link. Additionally the device does not receive any ethernet frame in the handler. I also tested the Arduino example code and the idf 4.2 example and both of them didn't manage to establish a reliably working link. They reliable print the `Ethernet started` message, but only rarely show the `Ethernet Link Up` message. Even if they show `Ethernet Link Up`, they don't seem to get any IP. The DHCP-Server does not seem to be an issue as the second board worked fine at that point. SO I put the broken board aside and continued with the second one.

The second one was also working reliably for several week. I even handed it out to my colleague for two week to test it on multiple switches. This weekend I got it back to add some features he was asking for.
Yesterday evening I tested it all, when suddenly after disconnecting and reconnecting the switch, this devices stopped working as well. Just like the other one, it stopped receiving any frames, as I could see from the serial monitor.
Contrary to the first board, this one does manage to reliably establish a link, but no frames are received and disconnecting the RJ45 keeps the link up.
I again flashed the example code and again no IP is detected. As this board now reliably configures a link, I hooked it up to my laptop with wireshark and a ISC-DHCP-Server running. To my surprise I could see a DHCP discover packed being sent by the board! The laptop does respond with an DHCP offer, then silence. No further data is coming from the board. This seems similar to my own project: The internal frame handler is not called, hence the DHCP offer is never seen by the software.

I am clueless on how to debug this. Any help?

DanKoloff, 2021-03-23:
Based on the good initial behavior and your colleague tests with multiple switches I would assume the issue seems related to either the "Ubiquity Unifi 8-Port POE auto-sensing switch" and/or the testing procedure of disconnecting and reconnecting the Ethernet cable.

You powered both ESP32-POE-ISO boards only from the "Ubiquity Unifi 8-Port POE auto-sensing switch" when the issue appeared? You kept connecting and disconnecting the Ethernet cable (and only power supply) between ESP32-POE-ISO the switch during testing?

I am not familiar with the switch but I see it supports passive PoE at 24V which is not sufficient for ESP32-POE-ISO, make sure the switch is set to active PoE.

Maybe try to disable powering from the switch and power the board from USB.

lucaelin, 2021-03-23:
Hey Dan,
thank you for taking a shot at it.
During the failure I had USB connected to the devices. My switch does support passive POE but the ports are configured for 802.3af/at.
I previously ran several tests without USB being connected, and both boards were perfectly capable to power up using the switches POE.
Now that the devices are bricked I cannot get any connection with them. Neither powering over USB with a non-poe ethernet (on a switch that is known to work), nor the POE port worked fine before. And any other devices connected to the switch now also work. So I am fairly confident that this is not a Switch issue.

DanKoloff, 2021-03-23:
Seems related to this action then, whether and how exactly and what got damaged is hard to say:

Unit 1:

> Soon I was testing some software reset behavior and repeatedly connecting and disconnecting the RJ45.

Unit 2:

> Yesterday evening I tested it all, when suddenly after disconnecting and reconnecting the switch, this devices stopped working as well.

Connecting and disconnecting the RJ45 repeatedly maybe somehow damaged the units. Not sure how acceptable it is for 50V+ PoE setup to disconnect and connect repeatedly.

lucaelin, 2021-03-26:
Just to clarify: It doesn't sound OK to you to have a device fail when removing the RJ45 or it doesn't sound OK to remove the RJ45? I am not sure I could agree with the latter...
And powering down the switch prior to disconnecting is not something I have ever heard any manufacturer recommend and certainly not something I can recommend to my colleague in the field.
If you want to know why disconnecting the device is so crucial to my project you can find a description of the Idea in a repository of mine called lldp-esp. Basically I want the board to render LLDP information about the switch it is connected to on an epaper display. LLDP messages are sent every 30-60 seconds so disconnecting doesn't happen immediately after connecting the device, but any flaw that kills the board within weeks or even months would be fatal to the entire project... :(
Do you have any lead on what could be wrong with the boards or how I could narrow down the search?

DanKoloff, 2021-03-29:
>...it doesn't sound OK to remove the RJ45?

This. I am pretty sure that even if both the switch and the board handle these disconnects without issues, at least the RJ45 plug will have some issues from the sparking.

But I will test it myself here and check if I can burn ESP32-PoE-ISO in similar conditions, will update you if it happens here and if I notice something in the way I managed to burn it.

> And powering down the switch prior to disconnecting is not something I have ever heard any manufacturer recommend and certainly not something I can recommend to my colleague in the field.
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
lapers, 2021-12-07:
> Hello,
>
> I have the same issue. Bought it via mouser.com week ago and it worked fine for a week while it was powered via USB. Then I bought POE switch (STEAMEMO 5 Port Gigabit Ethernet Unmanaged PoE Switch https://www.amazon.com/gp/product/B08TFY4G1C/ref=ppx_yo_dt_b_asin_title_o09_s00?ie=UTF8&psc=1 ) but once I connect board to this switch ethernet stop working. Board got little bit hot (about 45-50C) and TX &RX leds are off . If I connect USB and reconnect RJ45 then TX &RX leds going on and activity led start blinking ...also if I disconnect RJ45 again then TX &RX leds still on. I tried to use it without POE again but looks like ethernet is dead. And I feel that ethernet chip get warm even without POE power. Another board (wESP32) works fine on the same switch. Once I get replacement from mouser.com I can send it to support to find out what is wrong.

I am using ESP32-PoE instead of ESP32-PoE-ISO.
Currently I have the same problem with 2/3 of my new boards, the last one board not tested.
All works well on USB power.
The device heats up in the DC / DC converter area, and this area remains cold when powered by USB.
Ethernet PHY is LAN8710A.

To see, what happens I just connected TX, RX & GND pins of UART->USB converter to ESP32-PoE
In terminal I saw:
...
[WiFi-event] event: 20 (Ethernet plugged in)
[WiFi-event] event: 21 (Ethernet unplugged)
[WiFi-event] event: 20 (Ethernet plugged in)
[WiFi-event] event: 21 (Ethernet unplugged)
...

Behaviour looks like some power problems

lapers, 2021-12-07:
> Hello,
>
> I have the same issue. Bought it via mouser.com week ago and it worked fine for a week while it was powered via USB. Then I bought POE switch (STEAMEMO 5 Port Gigabit Ethernet Unmanaged PoE Switch https://www.amazon.com/gp/product/B08TFY4G1C/ref=ppx_yo_dt_b_asin_title_o09_s00?ie=UTF8&psc=1 ) but once I connect board to this switch ethernet stop working. Board got little bit hot (about 45-50C) and TX &RX leds are off . If I connect USB and reconnect RJ45 then TX &RX leds going on and activity led start blinking ...also if I disconnect RJ45 again then TX &RX leds still on. I tried to use it without POE again but looks like ethernet is dead. And I feel that ethernet chip get warm even without POE power. Another board (wESP32) works fine on the same switch. Once I get replacement from mouser.com I can send it to support to find out what is wrong.

I am using ESP32-PoE instead of ESP32-PoE-ISO.
Currently I have the same problem with 2/3 of my new boards, the last one board not tested.
All works well on USB power.
The device heats up in the DC / DC converter area, and this area remains cold when powered by USB.
Ethernet PHY is LAN8710A.

To see, what happens I just connected TX, RX & GND pins of UART->USB converter to ESP32-PoE
In terminal I saw:
...
[WiFi-event] event: 20 (Ethernet plugged in)
[WiFi-event] event: 21 (Ethernet unplugged)
[WiFi-event] event: 20 (Ethernet plugged in)
[WiFi-event] event: 21 (Ethernet unplugged)
...

Behaviour looks like some power problems

> The only thing I can conclude from your descriptions is that either LAN8720 (more likely) or the Ethernet connector (less likely) got damaged. Unfortunately, neither me nor the team have any idea how and why such damage occurred. Last couple of weeks our designers re-evaluated the Ethernet part of ESP32-POE-ISO and there doesn't seem to be any error in the design and it is PoE design we have used previously in other boards for years.
>
> My advice, if you wish to help us lower the number of possibilities is to return the damaged boards so we can at least confirm what exactly got damaged. First contact me via the support e-mail [support@olimex.com](mailto:support@olimex.com) and provide a link to this thread (so we don't go over it again) and we will issue RMA number and give you further instructions about the return. Thanks!

Have you found out what's going on?

f34rdotcom, 2021-12-30:
I have at least 5 bricked so far and just had a customer unit fail today same problem. Seems to happen when connecting ethernet or usb. Each time the current on the board goes up and USB communications fail with garbage or no usb serial data at all. Any suggestions on narrowing it down? My device also provides power to the ESP32 poe iso board so this just adds to the complexity but from my testing this seems to only happen when connecting ethernet with or without POE.

DanKoloff, 2021-12-30:
@lapers @f34rdotcom Contact us at support@olimex.com with details about the failed boards, what happened exactly, what hardware revision of the boards is, pictures of the failed boards and any other significant information that would allow us to try to replicate the issue. Thank you!

Closed 2021-09-30.

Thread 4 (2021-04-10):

Ethernet Connection as esp sleep wake source

lucaelin, 2021-04-10:
Is it possible to use the ethernet connection as a wake source for the esp32 deep sleep?
I couldn't find any documentation for this and the ethernet RX and TX are directly connected to the LAN8710A with no way to detect the switches auto-negotiation signals using the esp. AFAIK using the external power pin would work only if the switch supplies PoE...
Passing wires from the jacks RX lines to the GPIOs would work and not violate the galvanic isolation, right? Or does the LAN8710A provide another way to detect a connection without being powered?
Thanks in advance!

DanKoloff, 2021-04-12:
Probably any GPIO can be used as external source for wake up, but we haven't tested it. Please check what is written here:

https://docs.espressif.com/projects/esp-idf/en/latest/esp32/api-reference/system/sleep_modes.html

Look for "ext0" and "ext1". You can probably set the RTC IO pins to the pins of the Ethernet, so they won't go into deep sleep.

LAN8710A has such pin but we haven't routed it, so it is unavailable. If you look into LAN8710A's datasheet look for "nINT"

lucaelin, 2021-12-07:
I am sorry I didn't get back to this...
I approached this issue several times looking deep into the reference that you provided, but I still was not able to solve this. From my understanding, once that esp is in sleep mode, the ethernet looses its clock to transfer any data to the esp. I've tried multiple things to get around it, but no solution would ultimately wake the esp. In short I'm still stuck with this issue, but I am also a little out of my comfort zone here.

DanKoloff, 2021-12-08:
By default this is the expected outcome since Ethernet and WIFI are disabled in all power down modes. That is why you need to "hack" other ways to wake up, aka use signals arriving at Ethernet connector and route them to ext0 and ext2 that can be used as wake up source.

My advice is to first place a button on ext0 or ext1 pin then test it as wake up source, then figure how to do it with the Ethernet connector.

The wake up sources can be:

-Timer
-Touch pad
-External wakeup(ext0 & ext1)

Closed 2021-12-07.

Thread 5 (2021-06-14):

PHY nrst not mapped on any gpio

CyrilNeoFarm, 2021-06-14:
I am trying to use [micro-ROS as an esp-idf component.](https://github.com/micro-ROS/micro_ros_espidf_component) In order to use ethernet transport I need to write the PHY reset gpio number inside the menuconfig. However the nrst isn't mapped in the ESP32-POE-ISO.
I tried to use the PHY_PWR gpio instead with no success.
Would you know any way to solve this issue ?

DanKoloff, 2021-06-14:
Your inability to adapt custom component that you found online to work with our board, is not an issue with ESP32-POE-ISO. This is not the proper place to request software assistance.

Maybe try joining the forums or contacting the the micro-ROS team.

Also LAN8710's NRST is pulled high via resistor. You can find NRST if you download the schematic and open it and use find, the schematic has the labels searchable.

Closed 2021-06-14.

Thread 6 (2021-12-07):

Can't find 3D model of ESP32-POE-ISO

mattbue, 2021-12-07:
Hi,
I'm searching for a 3D model of the ESP32-POE-ISO.
Unfortunatelly in the 3d folders i can only find 3D models of the parts that are mounted on the pcb.

Do i miss something?

Thanks

DanKoloff, 2021-12-07:
Download the whole repo, start KiCAD, load the project in the folder of the proper hardware revision in KiCAD (it is open source and free), start the PCB part of the design and select view -> 3D.

Notice that the 3D view and model have illustrative purposes only! Do not trust the 3D model blindly, the heights of components might be inaccurate. This is because we don't need the heights for manufacturing and some components heights are not exact.

mattbue, 2021-12-07:
Thank you for your quick response.
I'm not familiar with KiCAD.
Since for mechanical construction I'm using SolidWorks was searching for a STEP-file containing the complete model.
Is there any chance to get such a STEP-file?

DanKoloff, 2021-12-07:
I generated a STEP file from KiCAD I check if it loads in some free STEP viewer and it seems fine. I have no experience with SolidWorks so I can't verify the export. You can find it inside the archive here:

[ESP32-PoE_Rev_G1_STEP.zip](https://github.com/OLIMEX/ESP32-POE-ISO/files/7666826/ESP32-PoE_Rev_G1_STEP.zip)

My advice is to install KiCAD, you might need it to analyze the electrical design or trace routes and wires. It is one of the big perks of ESP32-POE-ISO's design - an open-source hardware board, made with free open-source software CAD software. KiCAD can also be used to measure distances in the PCB view, there is a ruler tool.

mattbue, 2021-12-07:
Thank you!
Importing into SolidWorks worked and the board are looking great!

DanKoloff, 2021-12-07:
Great news, glad to help! Remember what I wrote previously about height and double verify empirically before you commit final design based on the this STEP. The height of components was never double checked and it serves only illustrative purposes.

mattbue, 2021-12-07:
Sure.
For me the 3D model is just a very good base for designing a case for my application.
Before design freeze all relevant dimensions will be double checked.

mattbue, 2021-12-08:
I've recognized that you have provided the 3D model of ESP32-PoE.
Can you please also provice the 3D model of ESP32-PoE-ISO?
Thanks

DanKoloff, 2021-12-08:
My bad, you can find ISO one here:

[ESP32-PoE-ISO_Rev_G1.zip](https://github.com/OLIMEX/ESP32-POE-ISO/files/7676229/ESP32-PoE-ISO_Rev_G1.zip)

mattbue, 2021-12-08:
Nothing to worry about!
Thanks

Closed 2022-10-31.

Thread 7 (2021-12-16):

DAC pins or analog outputs

omerll, 2021-12-16:
Hey mate, hope you doing well.
Do you know if the ESP32-POE-ISO has DAC outputs as the standard ESP32 (GPIO25 and GPIO26)?
I cant find them on the pin map pdf doc, and also point which pins work stable for ADC voltage measuring??

In advance TY
Have a great day

DanKoloff, 2021-12-16:
GPIO25 and GPIO26 are used for the Ethernet. If you want to use them you need to pick a board without Ethernet.

There are a lot of ADC pins available.

omerll, 2021-12-16:
I need to use this board (ESP32-POE-ISO) have 4 currently. I will use MCP4725 DAC via i2c

TY

DanKoloff, 2021-12-17:
> I need to use this board (ESP32-POE-ISO) have 4 currently. I will use MCP4725 DAC via i2c

Good solution. It is generally good idea to use external hardware if you need analog pins with ESP32. Maybe also check UEXT extension boards like MOD-IO2 or MOD-IO.  They can be plugged into the UEXT of ESP32-POE-ISO.

https://www.olimex.com/Products/Modules/IO/MOD-IO2/open-source-hardware

https://www.olimex.com/Products/Modules/IO/MOD-IO/open-source-hardware

Closed 2021-12-16.

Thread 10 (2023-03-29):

3D Integrated Models

markattecusa, 2023-03-29:
@DanKoloff

Is it possible for 3d integrated models to be published with PCB changes? Last posting seems to be G1.

https://github.com/OLIMEX/ESP32-POE-ISO/blob/master/HARDWARE/ESP32-PoE-ISO-Rev.G1/ESP32-PoE-ISO_Rev_G1.step

I can produce it if helpful, but someone may already have it.

Thanks!

DanKoloff, 2023-04-03:
Sorry I don't understand the request. Can you explain it with more words and examples?

DanKoloff, 2023-09-15:
If you request for STEP file you can export STEP via KiCAD - you can export STEP file via KiCAD (and KiCAD is free and open-source). Last time customers reported that the export works fine without any extra steps to take. Check my exchange with a customer:

https://github.com/OLIMEX/ESP32-POE-ISO/issues/6

Closed 2023-09-15.

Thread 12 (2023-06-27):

Usage of 2 DC/DCs - why?

markusdd, 2023-06-27:
Hi, I have on simple question: The ISO variant uses 2 DC DCs in series:
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

Why is this being done? I would have assumed that just using an isolating DC/DC module like WRB4805S-3WR2 should work?

What am I missing?

DanKoloff, 2023-06-28:
WRB4805S-3WR2 doesn't seem to have enable pin.

Basically there is suggested hardware setup when you use TPS2375PW.

markusdd, 2023-06-28:
Understood, but still it seems to be kind of twice the hardware. And also efficiency loss because you go through 2 DC/DCs.
If the isolating DC/DCs lack an enable couldn't this be done by using a simple low-RDS_on FET t turn it off when not needed?
Also: What is the point of enable? If there is no vooltage coming out f the ethernet jack?

DanKoloff, 2023-06-28:
Enable is connected to TPS2375PW's PG pin. What is TPS2375PW's PG pin? It is explained in this document: https://www.ti.com/lit/ds/symlink/tps2375.pdf

Also twice the hardware is not always bad thing if it is four times lower the price or reduces heat over a component.

markusdd, 2023-06-28:
That is true, but the reason I am asking is because the current isolating DC/DC is not goood enough for the platfoorm I am targeting an I am looking into designing something that can drive more than 400mA at 5V.
Looking at isolating DC/DCs that manage 600mA up to even 1200mA, at 78% or even more efficiency, so I am not sure which benefit the extra DC/DC brings except more cost, area and moore external components.

DanKoloff, 2023-06-28:
I understand but unfortunately ESP32-POE-ISO design is not suitable to for such loads. Maybe consider ESP32-POE, it is not isolated design but allows double the wattage: https://www.olimex.com/Products/IoT/ESP32/ESP32-POE/open-source-hardware

markusdd, 2023-06-28:
I guess I have to come up with something myself because isolation is a must for my applicatioon.

Closed 2023-09-15.

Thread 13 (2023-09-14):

ESP32-POE-ISO-WROVER

pmilicevic, 2023-09-14:
Hello,

I just received subject hardware in version K, that I intend to use with ESPHome. However turns out that tis release is using LAN chip LAN8710A that is not supported by ESPHome as per:
https://esphome.io/components/ethernet.html

I tried to use LAN8720 but no success. Error message is something about powering LAN chip.

Any suggestion?

Thanks!

DanKoloff, 2023-09-15:
1) If you scroll down the link you sent me you will see there is support and configuration for Olimex ESP32-POE which uses same Ethernet chip, meaning it will work. Also there is minor difference between LAN8720 and LAN8710A, the config for LAN8720 would probably work just fine
2) A lot of customers have reported success with ESPHome and Olimex ESP32 boards in the past, which leads me to believe it would work just fine
3) It is important to notice that configurations for ESP32-POE-ISO won't work out-of-the-box with ESP32-POE-ISO-WROVER, since WROVER uses two extra pins one of which is related to the clock of the Ethernet. Remember to change the clock pin assignment for GPIO17 to GPIO0 (clk_mode: GPIO0_OUT) from. Just use the config for ESP32-POE but change clk_mode to GPIO0_OUT. This is visible in the middle of the schematic of ESP32-POE-ISO!
4) We are not affiliated with ESPHome, if there are issues with ESPHome please report to ESPHome community or team.

pmilicevic, 2023-09-16:
Many thanks for your support!

It made it working with following snippet from yaml configuration:

# Olimex ESP32-POE-ISO-WROVER Rev K
esp32:
  board:  esp32-poe
  framework:
    type: esp-idf

ethernet:
  type: LAN8720
  mdc_pin: GPIO23
  mdio_pin: GPIO18
  clk_mode: GPIO0_OUT
  phy_addr: 0
  power_pin: GPIO12

Closed 2023-09-16.

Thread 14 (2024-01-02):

Rev K+ R22

marklister, 2024-01-02:
Based on this from the TPS237x data sheet (pg 12) :

`VSS with the tap connected to the UVLO pin. The total divider resistance appears in parallel with the R(DET), and the combination of the two should equal 24.9 kΩ. The divider ratio should be chosen to obtain 2.5 V at the UVLO pin when V(VDD) is at the desired turnon voltage.`

R22 should probably be 30k?

DanKoloff, 2024-01-03:
Maybe, the design we made was to fit all three TPS2375, TPS2376, and TPS2377 with minimal changes. Originally we used TPS2375 and used the schematic at the end of the slvu108 document as basis.

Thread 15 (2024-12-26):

v5.3 Example Software does not work on POE ISO

finchlt, 2024-12-26:
The v5.3 example does not initialize the phy correctly for the POE ISO board. I get the error messages below.

I updated the configuration to use the correct reset and clock configures configurations in menuconfig.

```
ELF file SHA256: 43dc0b3e1

Rebooting...
ets Jul 29 2019 12:21:46

rst:0xc (SW_CPU_RESET),boot:0x1b (SPI_FAST_FLASH_BOOT)
configsip: 0, SPIWP:0xee
clk_drv:0x00,q_drv:0x00,d_drv:0x00,cs0_drv:0x00,hd_drv:0x00,wp_drv:0x00
mode:DIO, clock div:2
load:0x3fff0030,len:7176
load:0x40078000,len:15564
ho 0 tail 12 room 4
load:0x40080400,len:4
--- 0x40080400: _init at ??:?

load:0x40080404,len:3904
entry 0x40080640
I (31) boot: ESP-IDF v5.3.2-dirty 2nd stage bootloader
I (31) boot: compile time Dec 18 2024 12:20:58
I (31) boot: Multicore bootloader
I (36) boot: chip revision: v3.1
I (40) boot.esp32: SPI Speed      : 40MHz
I (44) boot.esp32: SPI Mode       : DIO
I (49) boot.esp32: SPI Flash Size : 2MB
I (53) boot: Enabling RNG early entropy source...
I (59) boot: Partition Table:
I (62) boot: ## Label            Usage          Type ST Offset   Length
I (70) boot:  0 nvs              WiFi data        01 02 00009000 00006000
I (77) boot:  1 phy_init         RF data          01 01 0000f000 00001000
I (85) boot:  2 factory          factory app      00 00 00010000 00100000
I (92) boot: End of partition table
I (96) esp_image: segment 0: paddr=00010020 vaddr=3f400020 size=12e80h ( 77440) map
I (131) esp_image: segment 1: paddr=00022ea8 vaddr=3ffb0000 size=02494h (  9364) load
I (135) esp_image: segment 2: paddr=00025344 vaddr=40080000 size=0acd4h ( 44244) load
I (154) esp_image: segment 3: paddr=00030020 vaddr=400d0020 size=3125ch (201308) map
I (224) esp_image: segment 4: paddr=00061284 vaddr=4008acd4 size=02bf4h ( 11252) load
I (235) boot: Loaded app from partition at offset 0x10000
I (235) boot: Disabling RNG early entropy source...
I (248) cpu_start: Multicore app
I (256) cpu_start: Pro cpu start user code
I (256) cpu_start: cpu freq: 160000000 Hz
I (256) app_init: Application information:
I (259) app_init: Project name:     ethernet_basic
I (264) app_init: App version:      4054ce5-dirty
I (270) app_init: Compile time:     Dec 26 2024 16:37:22
I (276) app_init: ELF file SHA256:  43dc0b3e1...
I (281) app_init: ESP-IDF:          v5.3.2-dirty
I (286) efuse_init: Min chip rev:     v0.0
I (291) efuse_init: Max chip rev:     v3.99
I (296) efuse_init: Chip rev:         v3.1
I (301) heap_init: Initializing. RAM available for dynamic allocation:
I (308) heap_init: At 3FFAE6E0 len 00001920 (6 KiB): DRAM
I (314) heap_init: At 3FFB3768 len 0002C898 (178 KiB): DRAM
I (320) heap_init: At 3FFE0440 len 00003AE0 (14 KiB): D/IRAM
I (327) heap_init: At 3FFE4350 len 0001BCB0 (111 KiB): D/IRAM
I (333) heap_init: At 4008D8C8 len 00012738 (73 KiB): IRAM
I (341) spi_flash: detected chip: generic
I (344) spi_flash: flash io: dio
W (348) spi_flash: Detected size(4096k) larger than the size in the binary image header(2048k). Using the size in the binary image header.
I (362) main_task: Started on CPU0
I (372) main_task: Calling app_main()
I (372) esp.emac: Setup emac for rmii
E (472) esp.emac: emac_esp32_init(426): reset timeout
E (472) esp_eth: esp_eth_driver_install(228): init mac failed
E (472) example_eth_init: eth_init_internal(94): Ethernet driver install failed
I (472) gpio: GPIO[0]| InputEn: 0| OutputEn: 0| OpenDrain: 0| Pullup: 1| Pulldown: 0| Intr:0
I (482) gpio: GPIO[18]| InputEn: 0| OutputEn: 0| OpenDrain: 0| Pullup: 1| Pulldown: 0| Intr:0
I (492) gpio: GPIO[19]| InputEn: 0| OutputEn: 0| OpenDrain: 0| Pullup: 1| Pulldown: 0| Intr:0
I (502) gpio: GPIO[21]| InputEn: 0| OutputEn: 0| OpenDrain: 0| Pullup: 1| Pulldown: 0| Intr:0
I (512) gpio: GPIO[22]| InputEn: 0| OutputEn: 0| OpenDrain: 0| Pullup: 1| Pulldown: 0| Intr:0
I (522) gpio: GPIO[23]| InputEn: 0| OutputEn: 0| OpenDrain: 0| Pullup: 1| Pulldown: 0| Intr:0
I (532) gpio: GPIO[25]| InputEn: 0| OutputEn: 0| OpenDrain: 0| Pullup: 1| Pulldown: 0| Intr:0
I (542) gpio: GPIO[26]| InputEn: 0| OutputEn: 0| OpenDrain: 0| Pullup: 1| Pulldown: 0| Intr:0
I (552) gpio: GPIO[27]| InputEn: 0| OutputEn: 0| OpenDrain: 0| Pullup: 1| Pulldown: 0| Intr:0
E (562) example_eth_init: example_eth_init(249): internal Ethernet init failed
ESP_ERROR_CHECK failed: esp_err_t 0xffffffff (ESP_FAIL) at 0x400d7efe
--- 0x400d7efe: app_main at /home/lfinch/esp/ESP32-POE/SOFTWARE/ESP-IDF/ESP32_PoE_Ethernet_IDFv5.3/main/ethernet_example_main.c:71 (discriminator 1)

file: "./main/ethernet_example_main.c" line 71
func: app_main
expression: example_eth_init(&eth_handles, &eth_port_cnt)

abort() was called at PC 0x40086077 on core 0
--- 0x40086077: _esp_error_check_failed at /home/lfinch/esp/v5.3.2/esp-idf/components/esp_system/esp_err.c:49

```

DanKoloff, 2025-01-21:
1. What exactly is the board you got? What name is printed on the board? Is it standard ESP32-POE-ISO or maybe ESP32-POE-ISO-WROVER?

2. What are the pins you've entered for reset and clock in the menu config?

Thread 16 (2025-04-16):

Incorrect PoE DET Resistor Value (R22)

TCWORLD, 2025-04-16:
Per the TPS2376D datasheet, the combined resistance of the resistor on the DET pin, and the UVLO divider should be 24.9kΩ, not the detect resistor itself.

> The parallel combination of R(DET) and the UVLO program resistors must equal 24.9 kΩ, ±1%. Minimizing R(DET),
and maximizing the UVLO program resistors, improves efficiency during normal operation. Conversely, R(DET)
may be eliminated with the UVLO divider providing the 24.9 kΩ signature to reduce component count.

You're using a total 140 kΩ UVLO divider and an RDET of 24.9 kΩ, which leads to a combined 21.1 kΩ signature resistance which is technically out of spec for the PD end (min 23.7 kΩ).

I believe you should instead be using a 30.4 kΩ resistor for R22, which gives the required ~25 kΩ combined resistor.

TCWORLD, 2025-04-16:
Woops, just noticed somebody had already posted this, somehow I completely missed it.

Closed 2025-04-16.

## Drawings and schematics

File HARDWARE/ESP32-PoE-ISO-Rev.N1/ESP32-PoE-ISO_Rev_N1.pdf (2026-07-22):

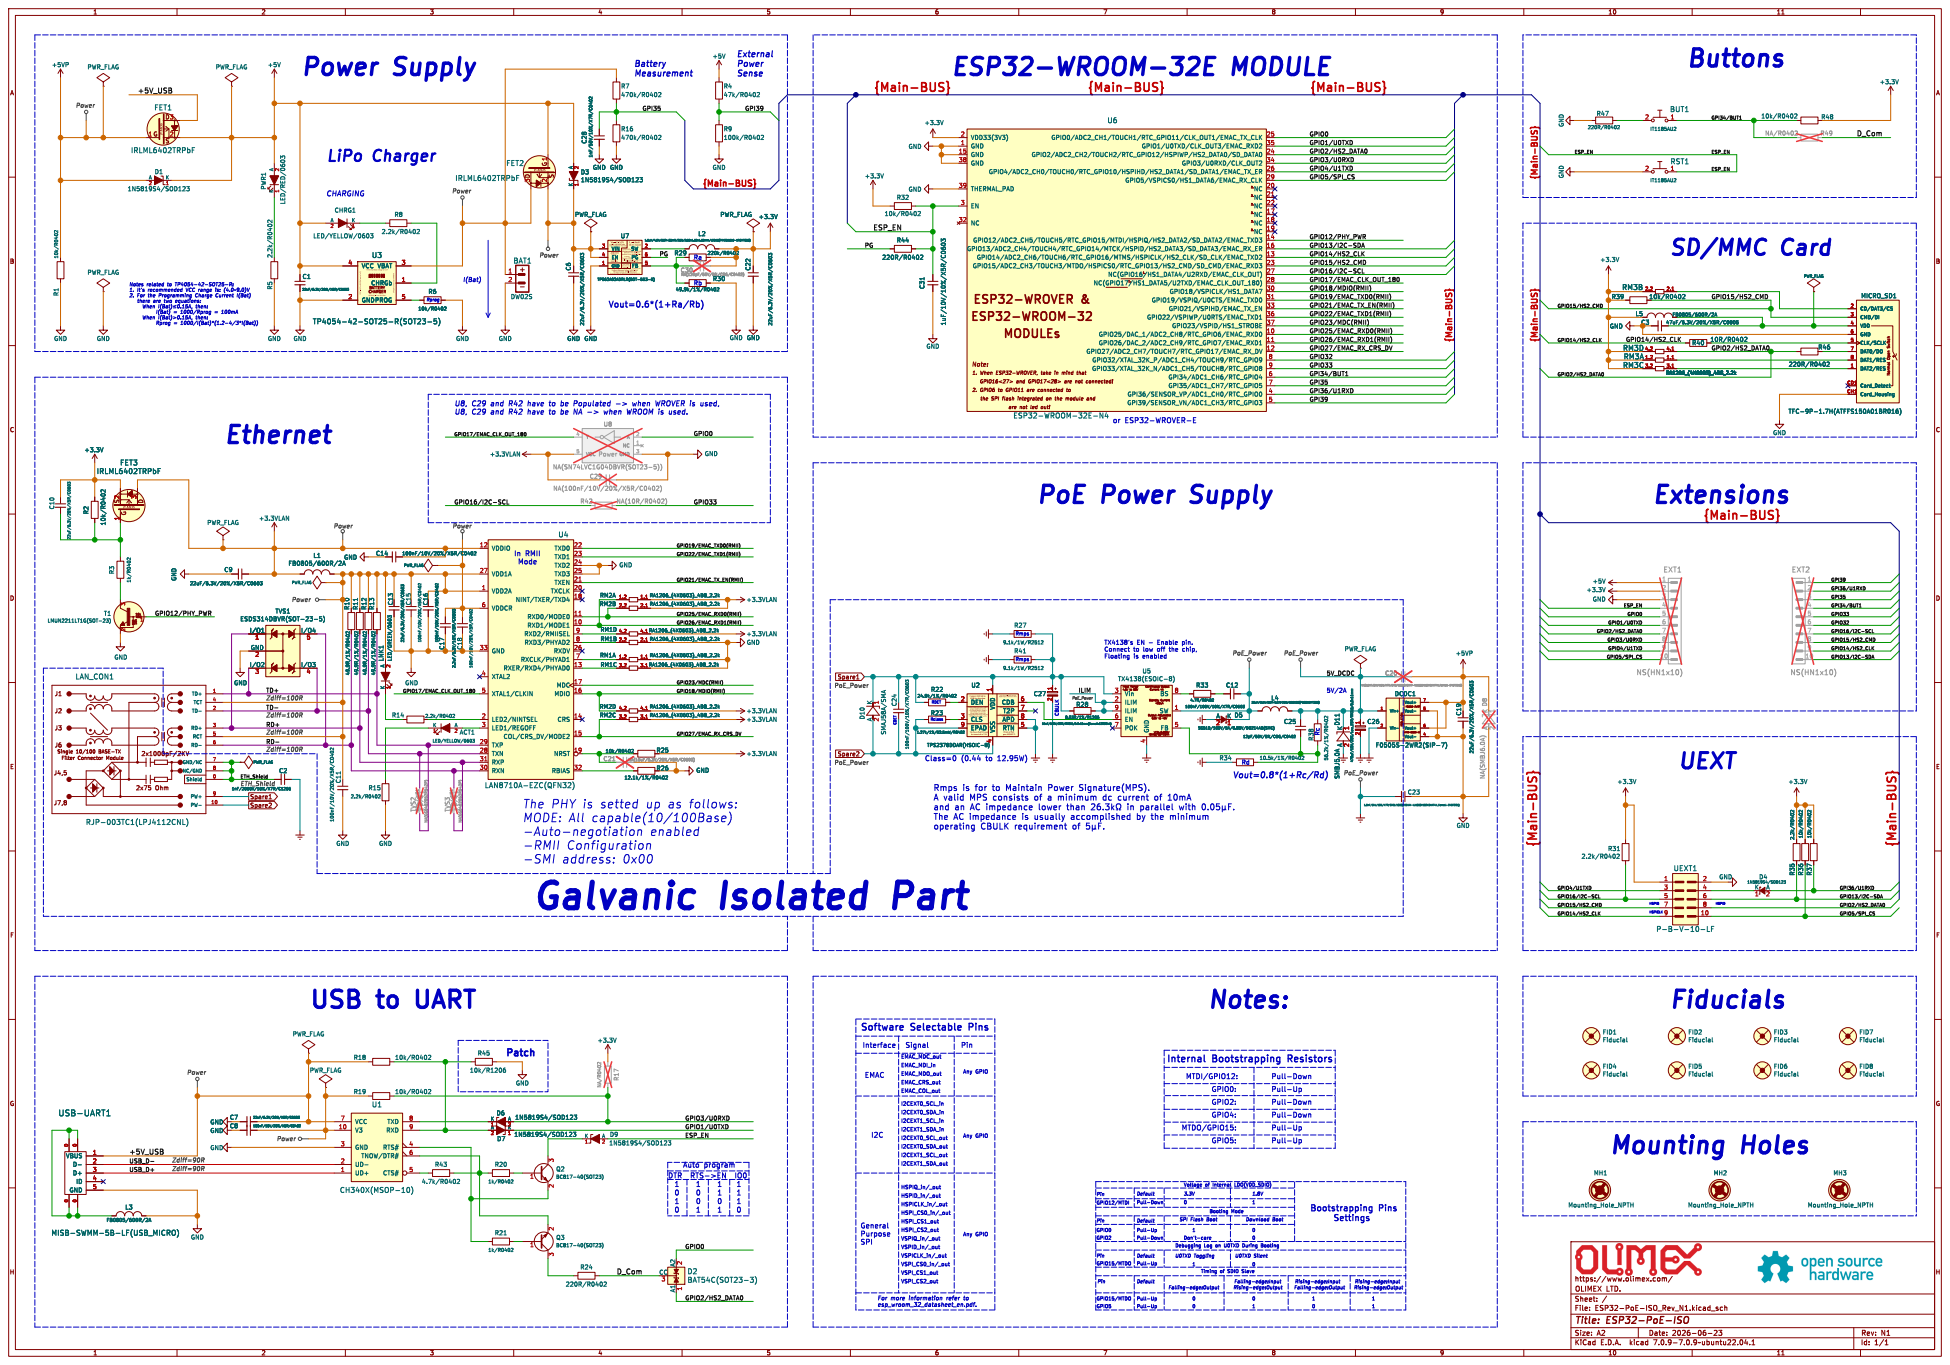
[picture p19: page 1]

2. 2. 2. 2. 2. 2. 2. GPIO6 to GPIO11 are connected to
22 GPIO15/ADC2_CH3/TOUCH3/MTDO/HSPICS0/RTC_GPIO13/HS2_CMD/SD_CMD/EMAC_RXD3

Cout=(10~22)uF/6.3V/X5Rþÿ(Vout"e1.8V). 22uFRecommended! Cout=22uF/6.3V/X5Rþÿ(1.2V"dVout<1.8V) Cout=44uF/6.3V/X5Rþÿ(0.6V"dVout<1.2V) DCR<50mR

In casea loweroutputrippleisdesired,higheroutputcapacitancecanhelpreducetheripple. Lx=1.0uH
Vout=0.6*(1+Ra/Rb) Ra

Donotfloat. Enablecontrol. FB Input Current,I(FB)=100nA(max) FeedbackReferenceVoltage,V(REF)=0.6V
Rb mustnotbehigherthanþÿ100k© toprovideacceptablenoisesensitivity. ShutdownCurrentI(SHDN)=0.01-2uA

are not led out! ESP32-WROOM-32

GPIO0
GPIO19/EMAC_TXD0(RMII) GPIO23/MDC(RMII) GPIO21/EMAC_TX_EN(RMII) GPIO27/EMAC_RX_CRS_DV GPIO25/EMAC_RXD0(RMII) GPIO26/EMAC_RXD1(RMII) GPIO18/MDIO(RMII) GPIO33

Rmps The PHY is setted up as follows:

Rd TX4138's EN - Enable pin. Connect to low off the chip,

AuxiliaryPowerDetect Activelowindicatestype2 Activelow,open-drainconverterdisable output,referencedtoRTN. Connect24.9þÿk©toVDD for detection. ConnectresistorfromCLS toVSStoprogram classificationcurrent.

4 RTN 5 CDB 6 T2P 7 APD 8 EPAD 9 U2

4 RTN 5 CDB 6 T2P 7 APD 8 EPAD 9 C27

If notused,connectAPD toRTN. PSEconnectedor APD active. ThePowerPadTMmustbe connectedtoVSS.VDD

The controllerplacesa voltageof approximately 2.5Vacrosstheexternal resistorwheneverthevoltage differentialbetweenVDD andVSS liesfromabout10.9Vto22V. Drain ofPoEpass MOSFET.

Rmps is for to Maintain Power Signature(MPS).
A valid MPS consists of a minimum dc current of 10mA
and an AC impedance lower than þÿ26.3k©in parallel with þÿ0.05¼F.
operating CBULK requirement of þÿ5¼F.

Rising-edge:Input Don't-care Booting Mode

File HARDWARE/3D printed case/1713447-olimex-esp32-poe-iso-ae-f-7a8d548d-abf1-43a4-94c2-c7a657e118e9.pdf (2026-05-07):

## Olimex ESP32-POE-ISO-AE-F

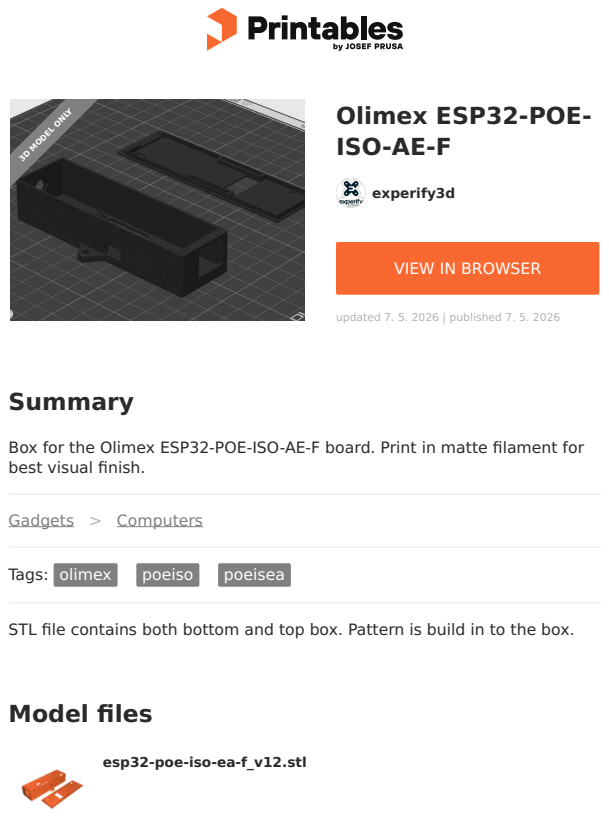
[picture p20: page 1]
Model files; Summary; Gadgets > Computers; Tags:; olimex; poeiso; poeisea; experify3d; updated 7. 5. 2026 | published 7. 5. 2026; 3D MODEL ONLY

VIEW IN BROWSER (https://printables.com/model/1713447-olimex-esp32-poe-iso-ae-f)

Box for the Olimex ESP32-POE-ISO-AE-F board. Print in matte filament for
best visual finish.

STL file contains both bottom and top box. Pattern is build in to the box.

esp32-poe-iso-ea-f_v12.stl

## License

This work is licensed under a
Creative Commons (4.0 International License)

Attribution (http://creativecommons.org/licenses/by/4.0/)

✖ | Sharing without ATTRIBUTION
✔ | Remix Culture allowed
✔ | Commercial Use
✔ | Free Cultural Works
✔ | Meets Open Definition

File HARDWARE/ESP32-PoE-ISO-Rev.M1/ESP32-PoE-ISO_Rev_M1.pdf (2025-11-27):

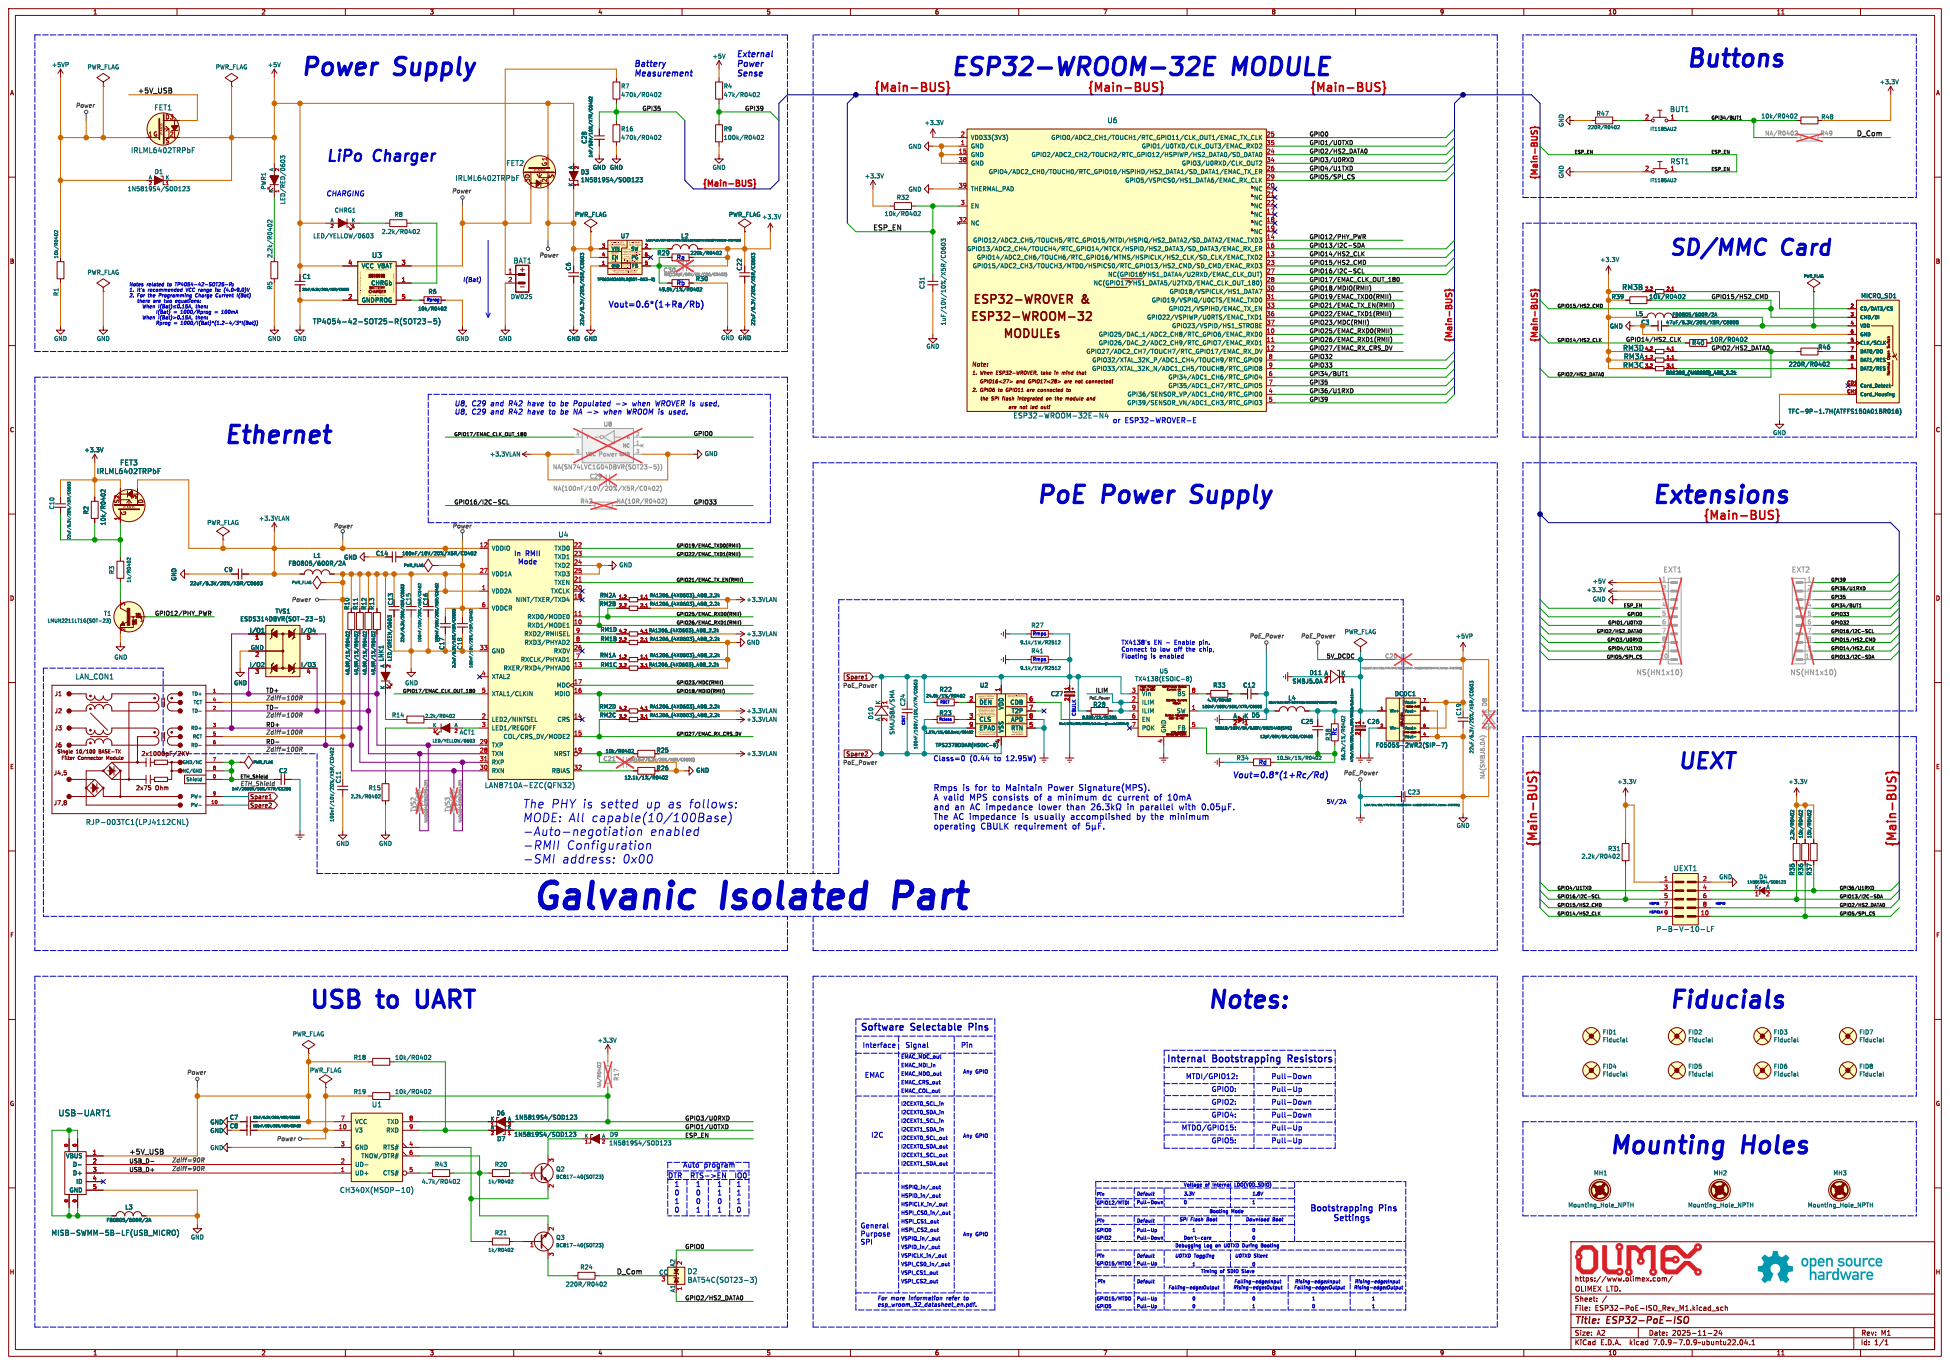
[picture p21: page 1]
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

In casea loweroutputrippleisdesired,higheroutputcapacitancecanhelpreducetheripple. Lx=1.0uH

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

are not led out! ESP32-WROOM-32

Rb Vout=0.6*(1+Ra/Rb)

U0TXD Silent Download Boot Pull-Down Ethernet

GPIO22/EMAC_TXD1(RMII) GPIO19/EMAC_TXD0(RMII) GPIO21/EMAC_TX_EN(RMII) GPIO25/EMAC_RXD0(RMII) GPIO17/EMAC_CLK_OUT_180

4 RTN 5 CDB 6 T2P 7 APD 8 EPAD 9 U2

AuxiliaryPowerDetect Activelowindicatestype2 Activelow,open-drainconverterdisable output,referencedtoRTN. Connect24.9þÿk©toVDD for detection. ConnectresistorfromCLS toVSStoprogram classificationcurrent.

4 RTN 5 CDB 6 T2P 7 APD 8 EPAD 9 R23

If notused,connectAPD toRTN. PSEconnectedor APD active. ThePowerPadTMmustbe connectedtoVSS.VDD

The controllerplacesa voltageof approximately 2.5Vacrosstheexternal resistorwheneverthevoltage differentialbetweenVDD andVSS liesfromabout10.9Vto22V. Drain ofPoEpass MOSFET.

3.3V Rmps is for to Maintain Power Signature(MPS).
A valid MPS consists of a minimum dc current of 10mA
and an AC impedance lower than þÿ26.3k©in parallel with þÿ0.05¼F.
1.8V GPIO2: MTDO/GPIO15: Notes:

operating CBULK requirement of þÿ5¼F. 0

HSPIQ USB to UART

Voltage of Internal LDO(VDD_SDIO)Pull-Up

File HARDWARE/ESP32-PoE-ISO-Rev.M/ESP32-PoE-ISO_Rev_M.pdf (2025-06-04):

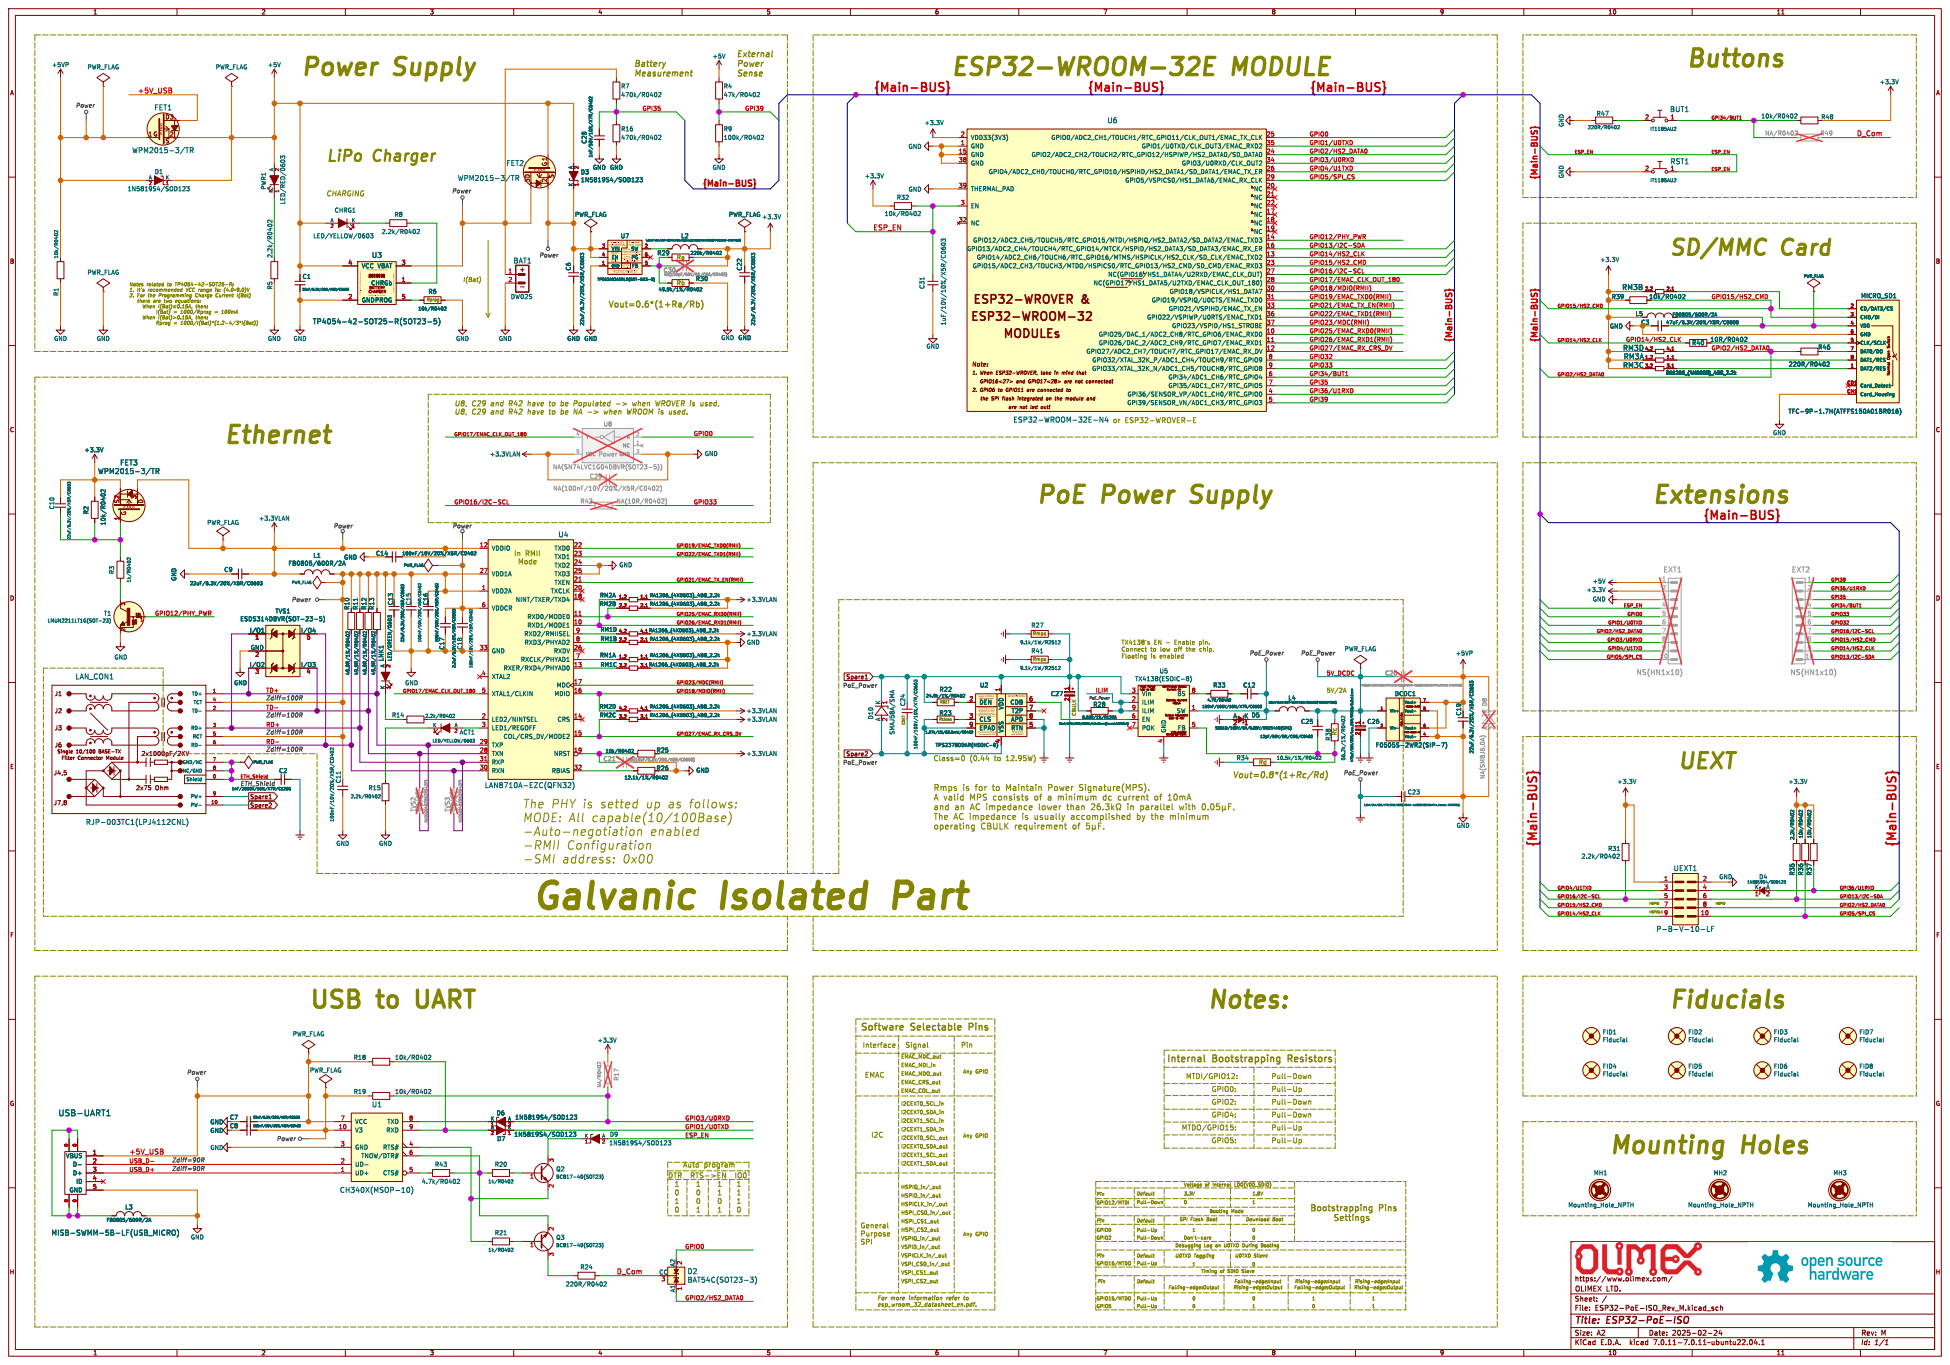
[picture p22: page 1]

2. 2. 2. 2. 2. 2. 2. GPIO6 to GPIO11 are connected to

In casea loweroutputrippleisdesired,higheroutputcapacitancecanhelpreducetheripple. Lx=1.0uH
Cout=(10~22)uF/6.3V/X5Rþÿ(Vout"e1.8V). 22uFRecommended! Cout=22uF/6.3V/X5Rþÿ(1.2V"dVout<1.8V) Cout=44uF/6.3V/X5Rþÿ(0.6V"dVout<1.2V) DCR<50mR

Donotfloat. Enablecontrol. FB Input Current,I(FB)=100nA(max) FeedbackReferenceVoltage,V(REF)=0.6V
Rb mustnotbehigherthanþÿ100k© toprovideacceptablenoisesensitivity. ShutdownCurrentI(SHDN)=0.01-2uA
SwitchingFrequency 2.4MHz TPS62A02ADRLR V(ENH)=1.2V

GPIO18/MDIO(RMII) GPIO26/EMAC_RXD1(RMII) GPIO23/MDC(RMII) GPIO25/EMAC_RXD0(RMII) GPI36/U1RXD GPIO27/EMAC_RX_CRS_DV

2 LNK1 LED/GREEN/0603 GND R37 10k/R0402 R36 10k/R0402 GND

HSPIQ CDET USB to UART

4 RTN 5 CDB 6 T2P 7 APD 8 EPAD 9 C26 470uF/10V/20%/Low_ESR/RM2.5/6.0x11mm 1 2 C20

4 RTN 5 CDB 6 T2P 7 APD 8 EPAD 9 U2

4 FB 5 EN 6 POK 7 BS 8

AuxiliaryPowerDetect Activelowindicatestype2 Activelow,open-drainconverterdisable output,referencedtoRTN. Connect24.9þÿk©toVDD for detection. ConnectresistorfromCLS toVSStoprogram classificationcurrent.

If notused,connectAPD toRTN. PSEconnectedor APD active. ThePowerPadTMmustbe connectedtoVSS.VDD
Rd GPIO2:Vout=0.8*(1+Rc/Rd) Notes:

The controllerplacesa voltageof approximately 2.5Vacrosstheexternal resistorwheneverthevoltage differentialbetweenVDD andVSS liesfromabout10.9Vto22V. Drain ofPoEpass MOSFET.

The PHY is setted up as follows: MODE: All capable(10/100Base)

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

operating CBULK requirement of þÿ5¼F. 0

Pull-Up Pull-Down Pull-Down Pull-Up GPIO4:

USB-UART1 MISB-SWMM-5B-LF(USB_MICRO) 0 0

Voltage of Internal LDO(VDD_SDIO) 3.3V

Timing of SDIO Slave Falling-edge:Output Debugging Log on U0TXD During Booting

File: ESP32-PoE-ISO_Rev_M.kicad_sch Sheet: / OLIMEX LTD. https://www.olimex.com/

Id: 1/1 Title: ESP32-PoE-ISO

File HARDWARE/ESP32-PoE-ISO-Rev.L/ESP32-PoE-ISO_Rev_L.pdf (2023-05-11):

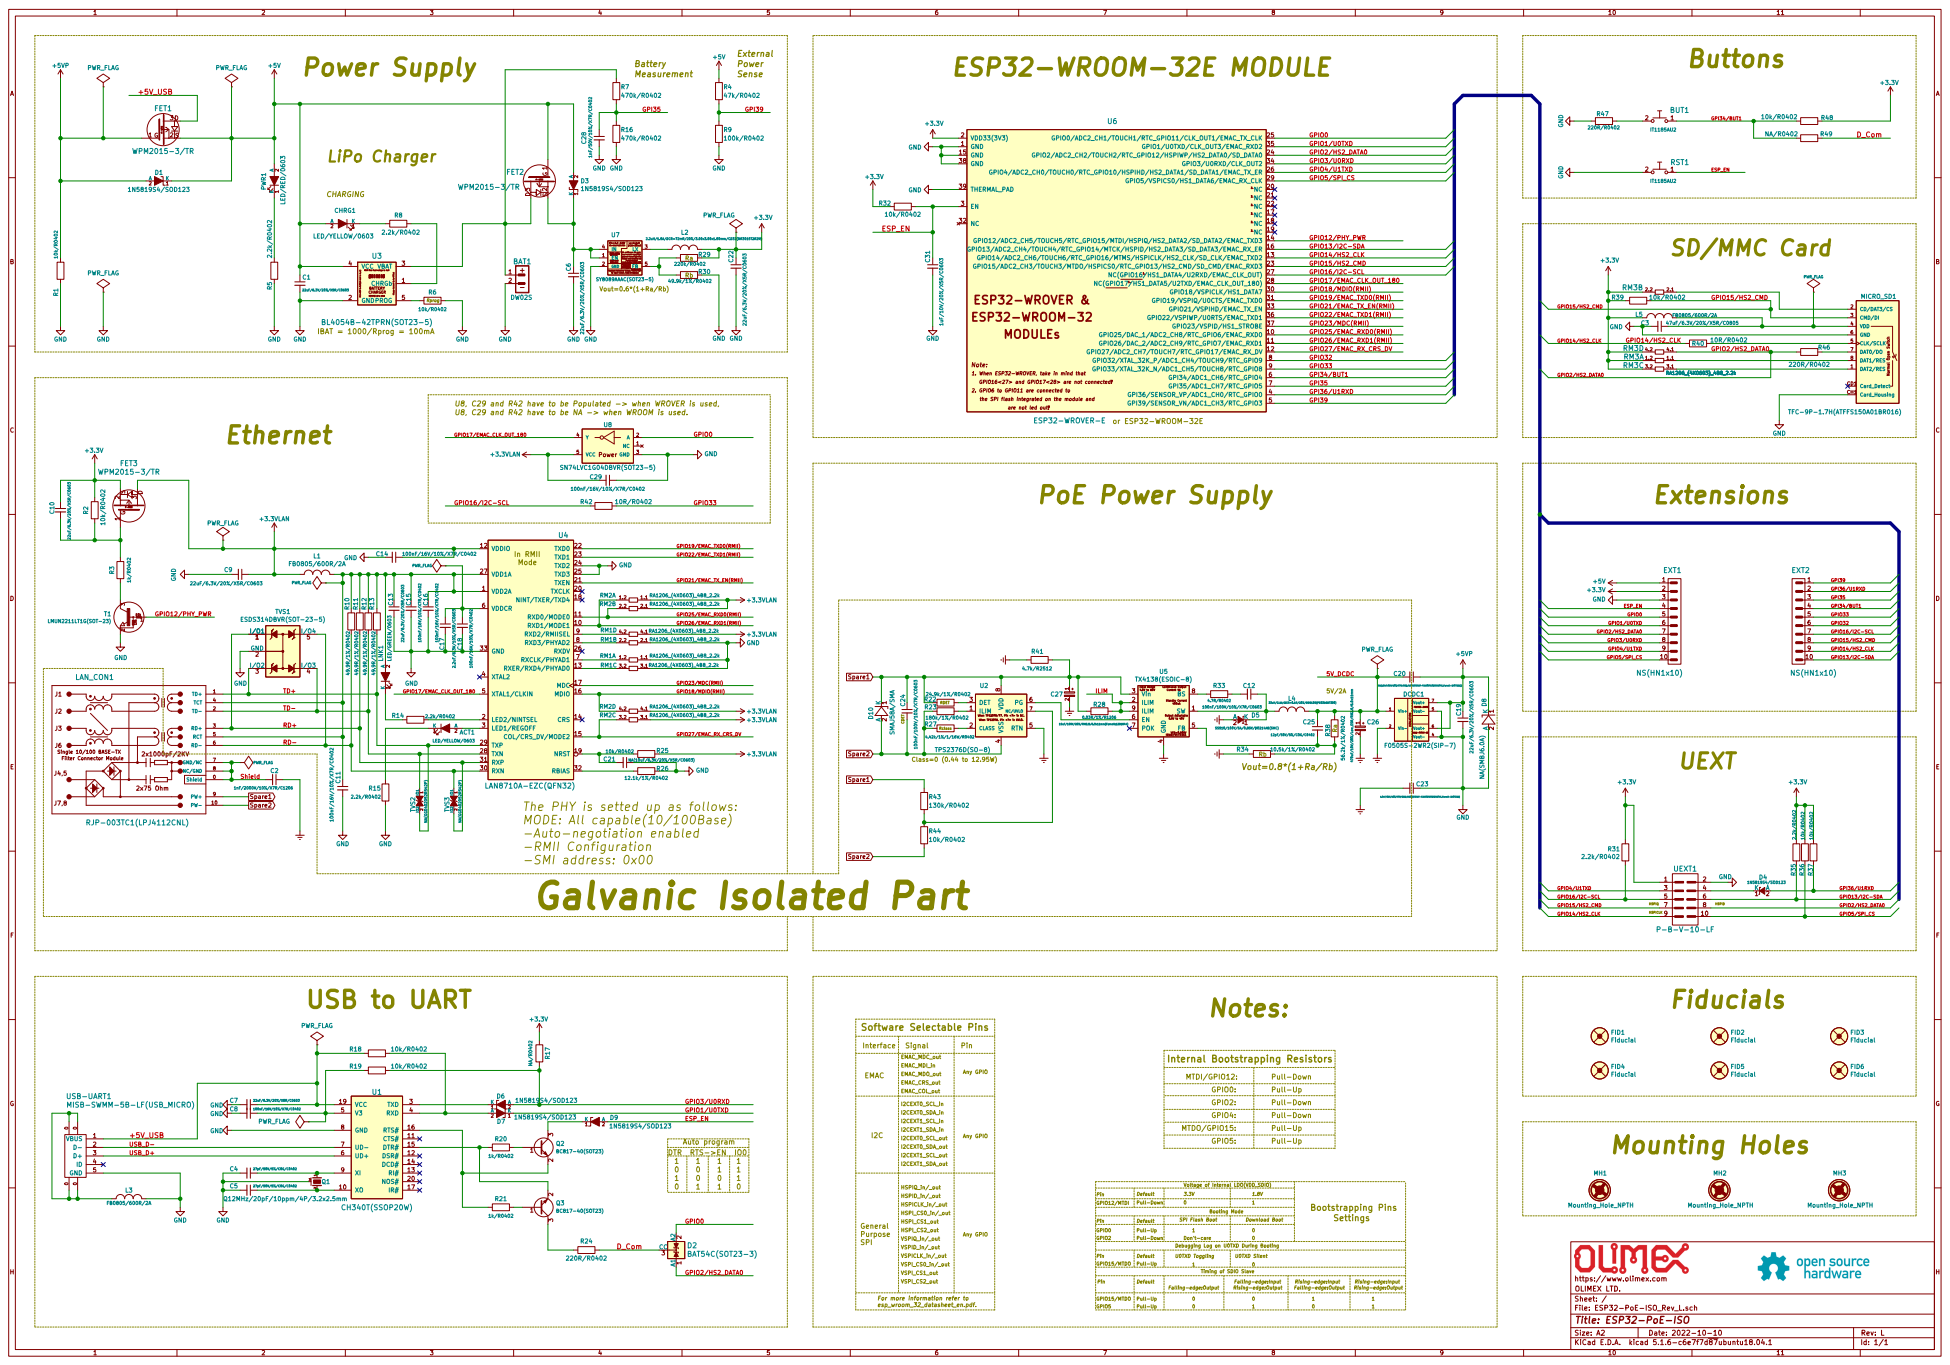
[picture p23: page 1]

2. 2. 2. 2. 2. 2. 2. GPIO6 to GPIO11 are connected to are not led out! ESP32-WROOM-32 ESP32-WROVER &

load current capability! Lx=2.2uH

Do not float. Enable control. FB Input Current, I(FB)=50nA(max) Feedback Reference Voltage, V(REF)=0.6V

1. 1. 1. When ESP32-WROVER, take in mind that

GPIO16<27> and GPIO17<28> are not connected! MODULEs

4 FB 5 EN 6 POK 7 BS 8

Interface The PHY is setted up as follows:
MODE: All capable(10/100Base)
-Auto-negotiation enabled
-RMII Configuration
-SMI address: 0x00

Signal Software Selectable Pins

Auto program
SPI Flash Boot Pull-Up Pull-Down DTR RTS->EN IO0

Falling-edge:Output Pull-Down For more information refer to esp_wroom_32_datasheet_en.pdf.

Id: 1/1 Title: ESP32-PoE-ISO

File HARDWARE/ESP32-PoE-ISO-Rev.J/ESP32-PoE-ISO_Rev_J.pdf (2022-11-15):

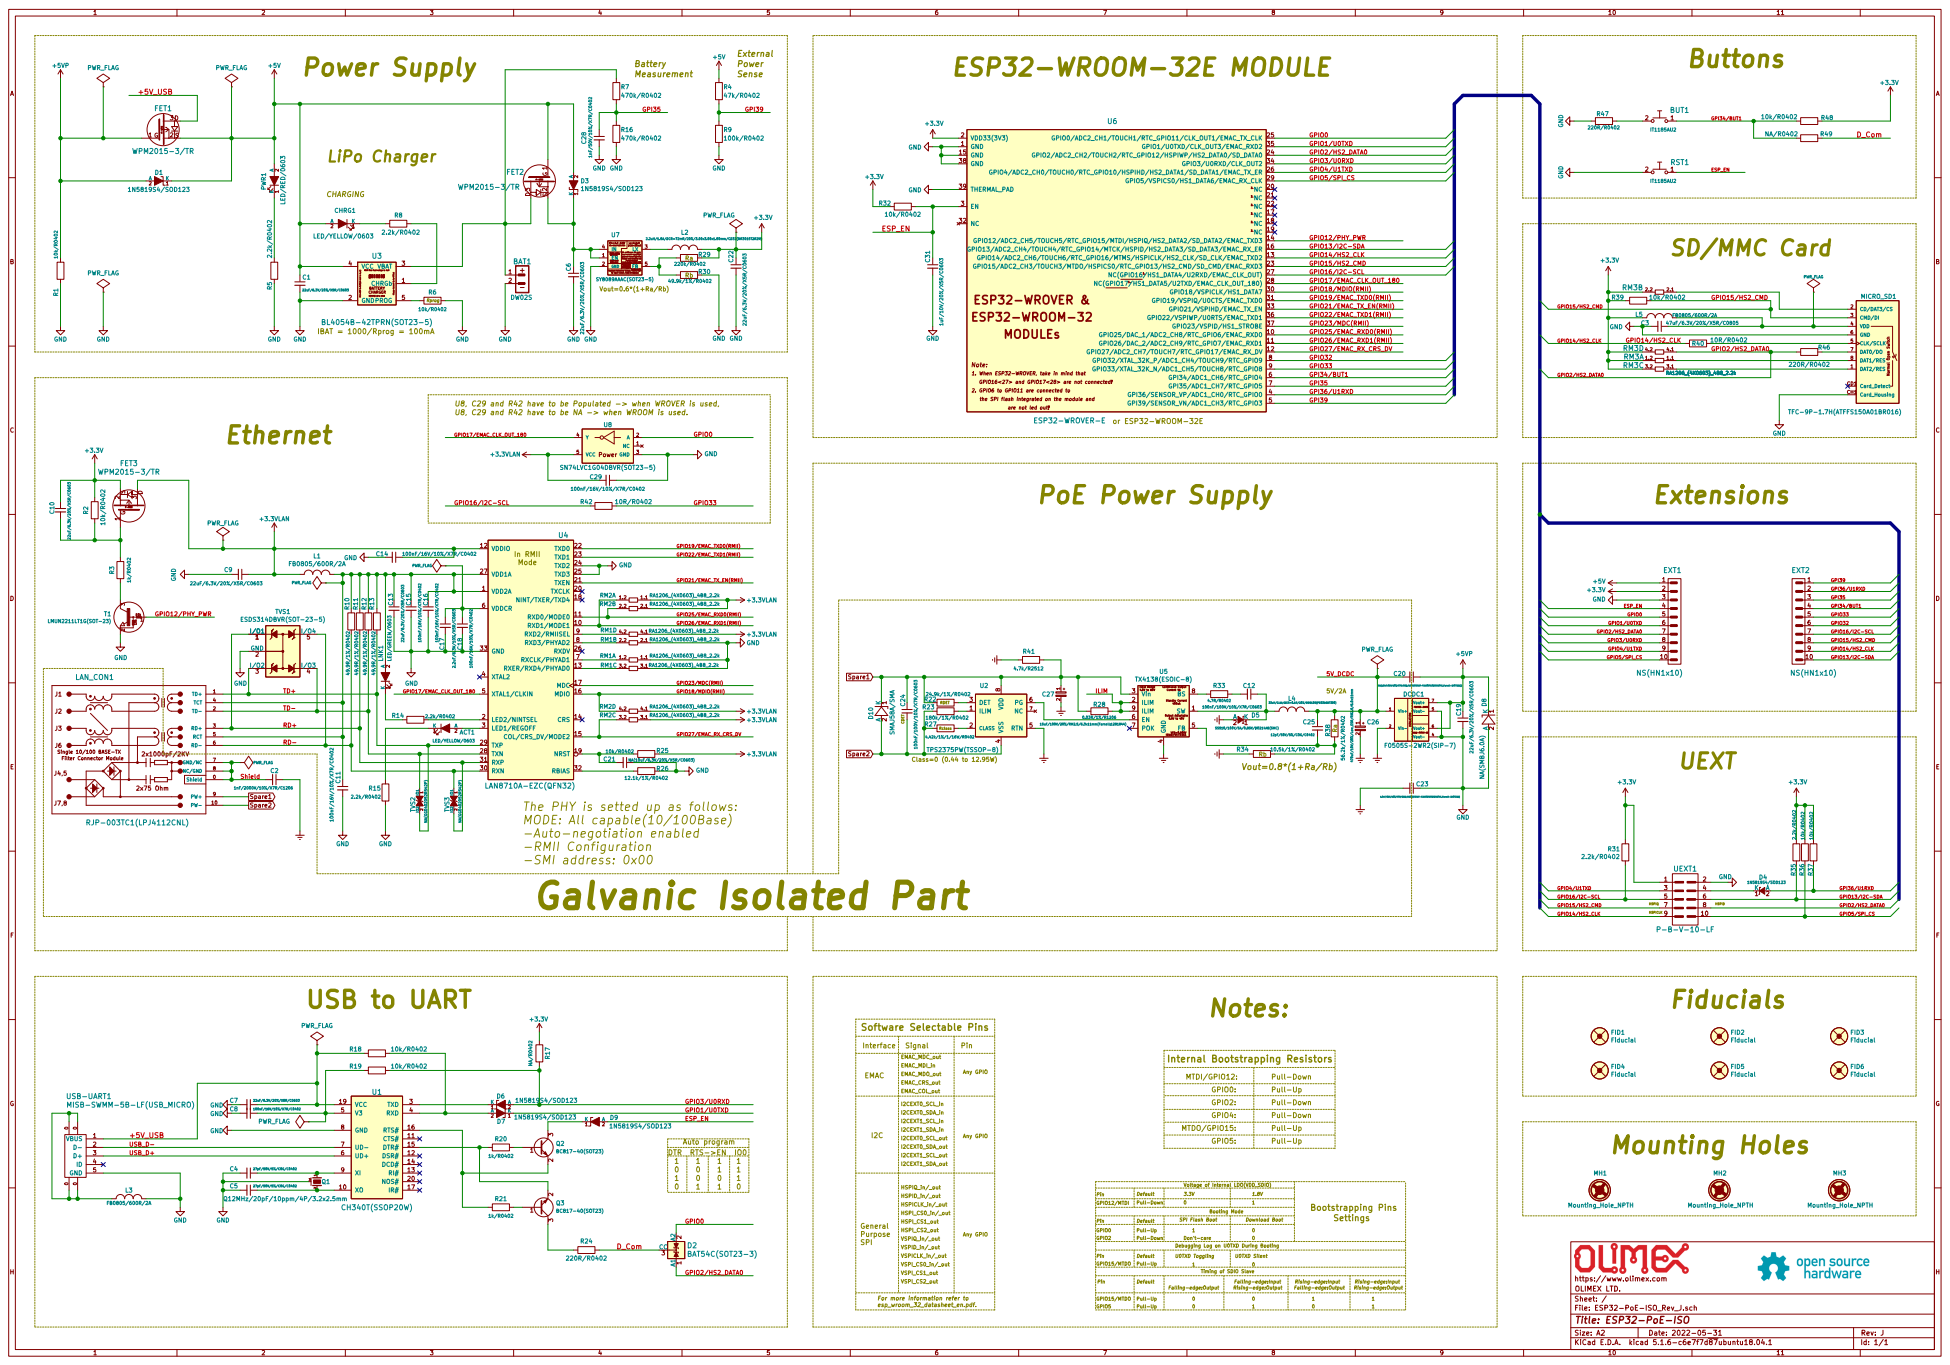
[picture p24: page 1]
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

load current capability! Lx=2.2uH

Vout=0.6*(1+Ra/Rb) EN 1 GND 2

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

1. 1. 1. When ESP32-WROVER, take in mind that

GPIO16<27> and GPIO17<28> are not connected! MODULEs

4 FB 5 EN 6 POK 7 BS 8

LAN8710A-EZC(QFN32)
Default Software Selectable Pins The PHY is setted up as follows:
MODE: All capable(10/100Base)
-Auto-negotiation enabled
-RMII Configuration
-SMI address: 0x00
HSPID_in/_out Galvanic Isolated Part

File: ESP32-PoE-ISO_Rev_J.sch Sheet: / OLIMEX LTD. https://www.olimex.com

Id: 1/1 Title: ESP32-PoE-ISO

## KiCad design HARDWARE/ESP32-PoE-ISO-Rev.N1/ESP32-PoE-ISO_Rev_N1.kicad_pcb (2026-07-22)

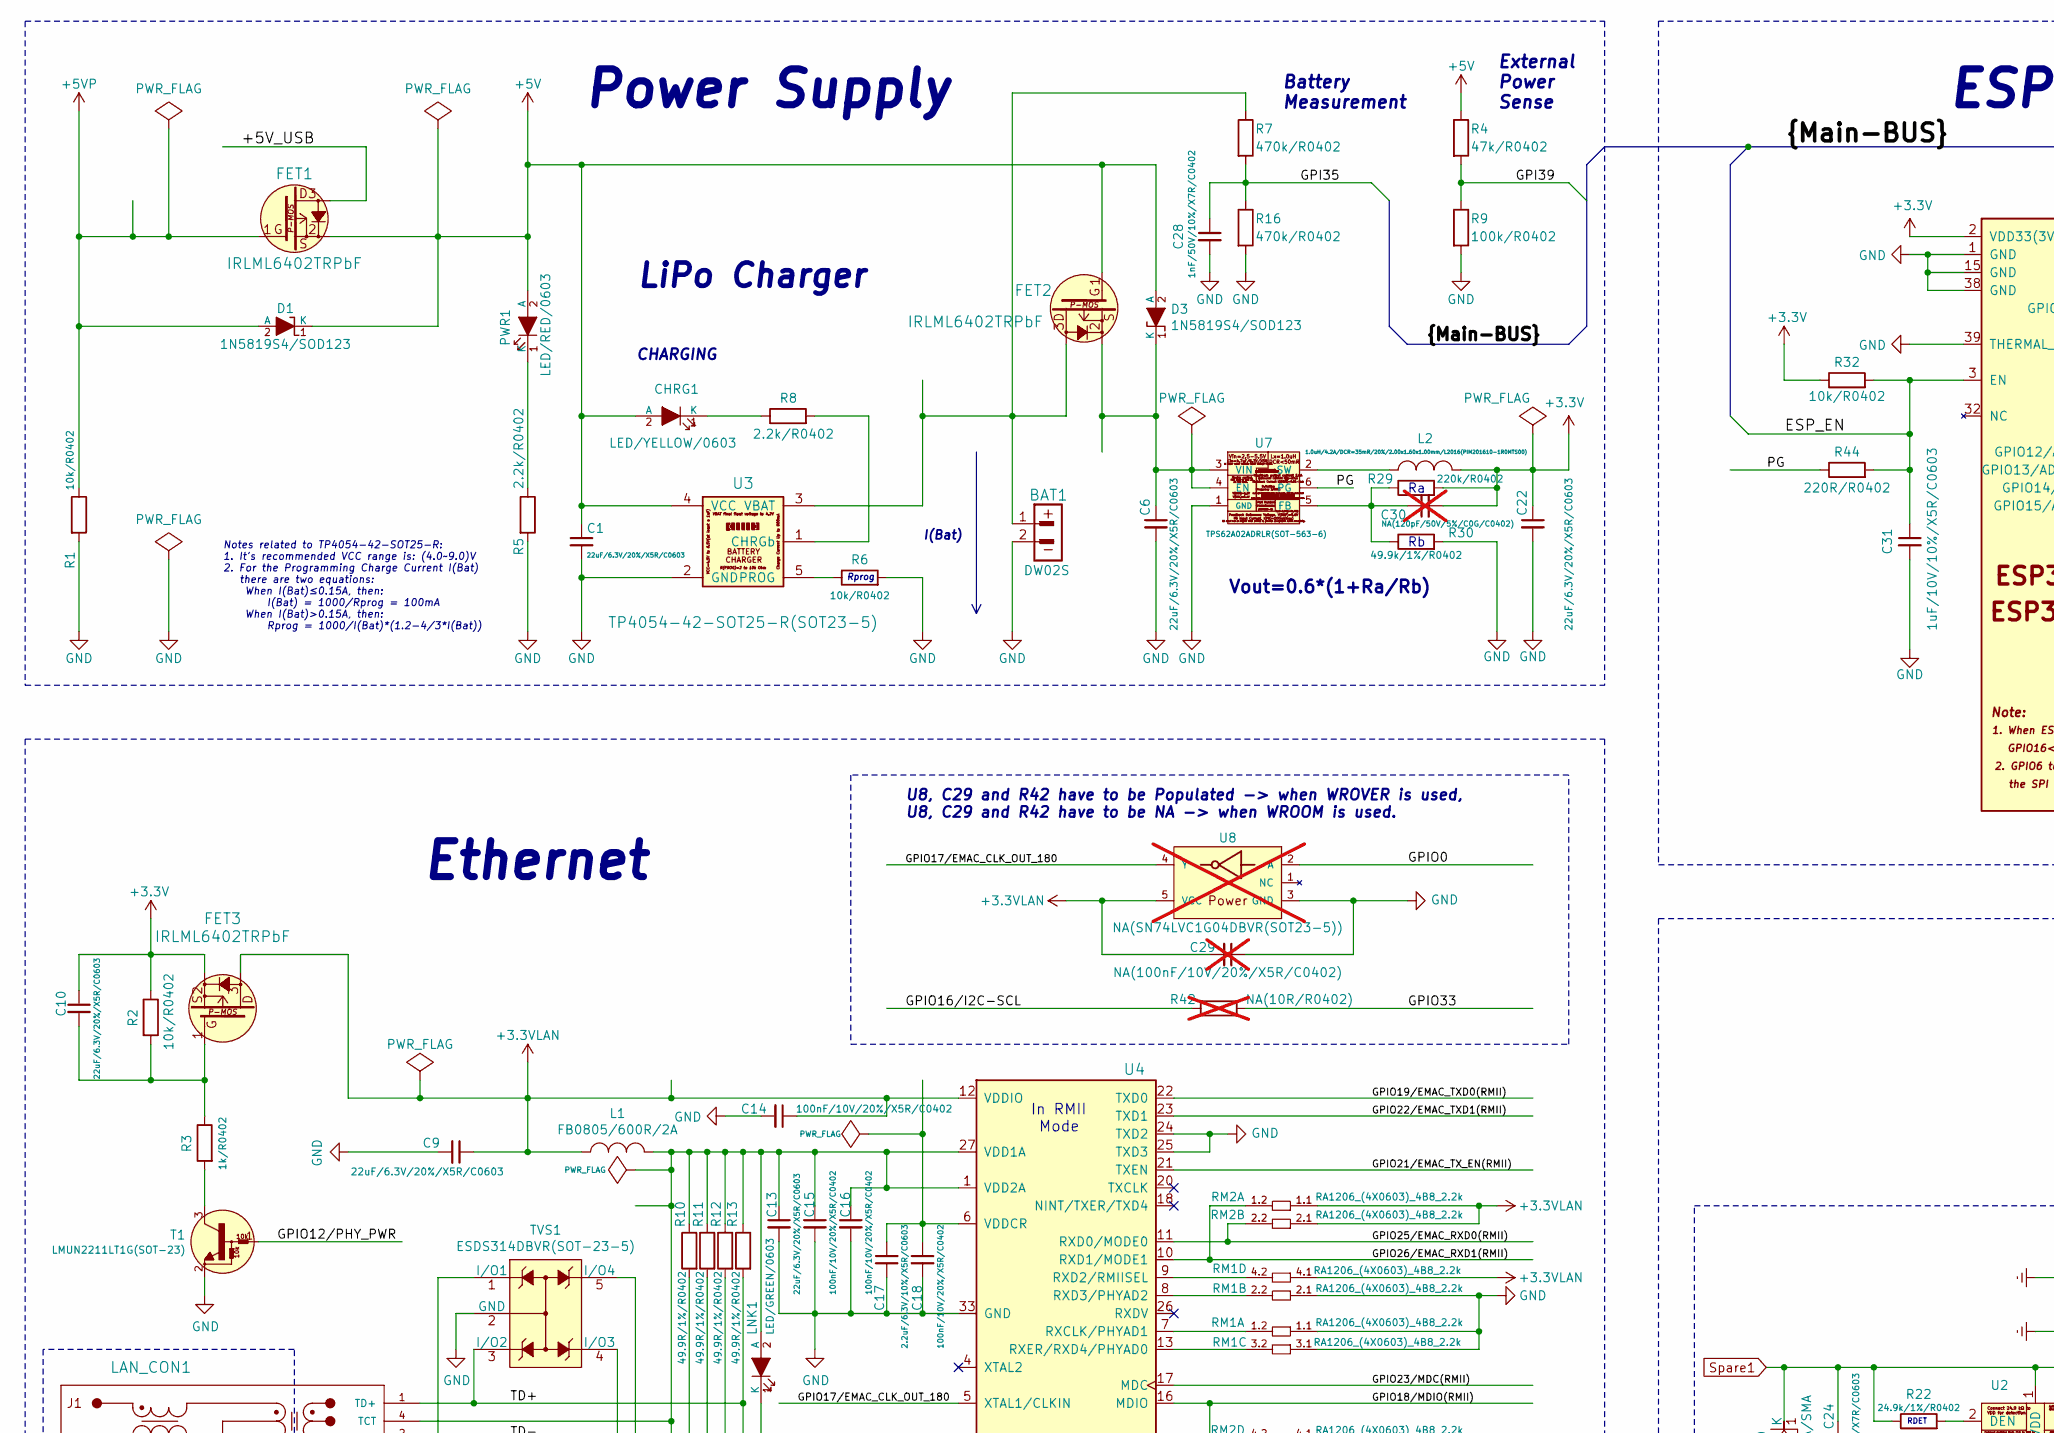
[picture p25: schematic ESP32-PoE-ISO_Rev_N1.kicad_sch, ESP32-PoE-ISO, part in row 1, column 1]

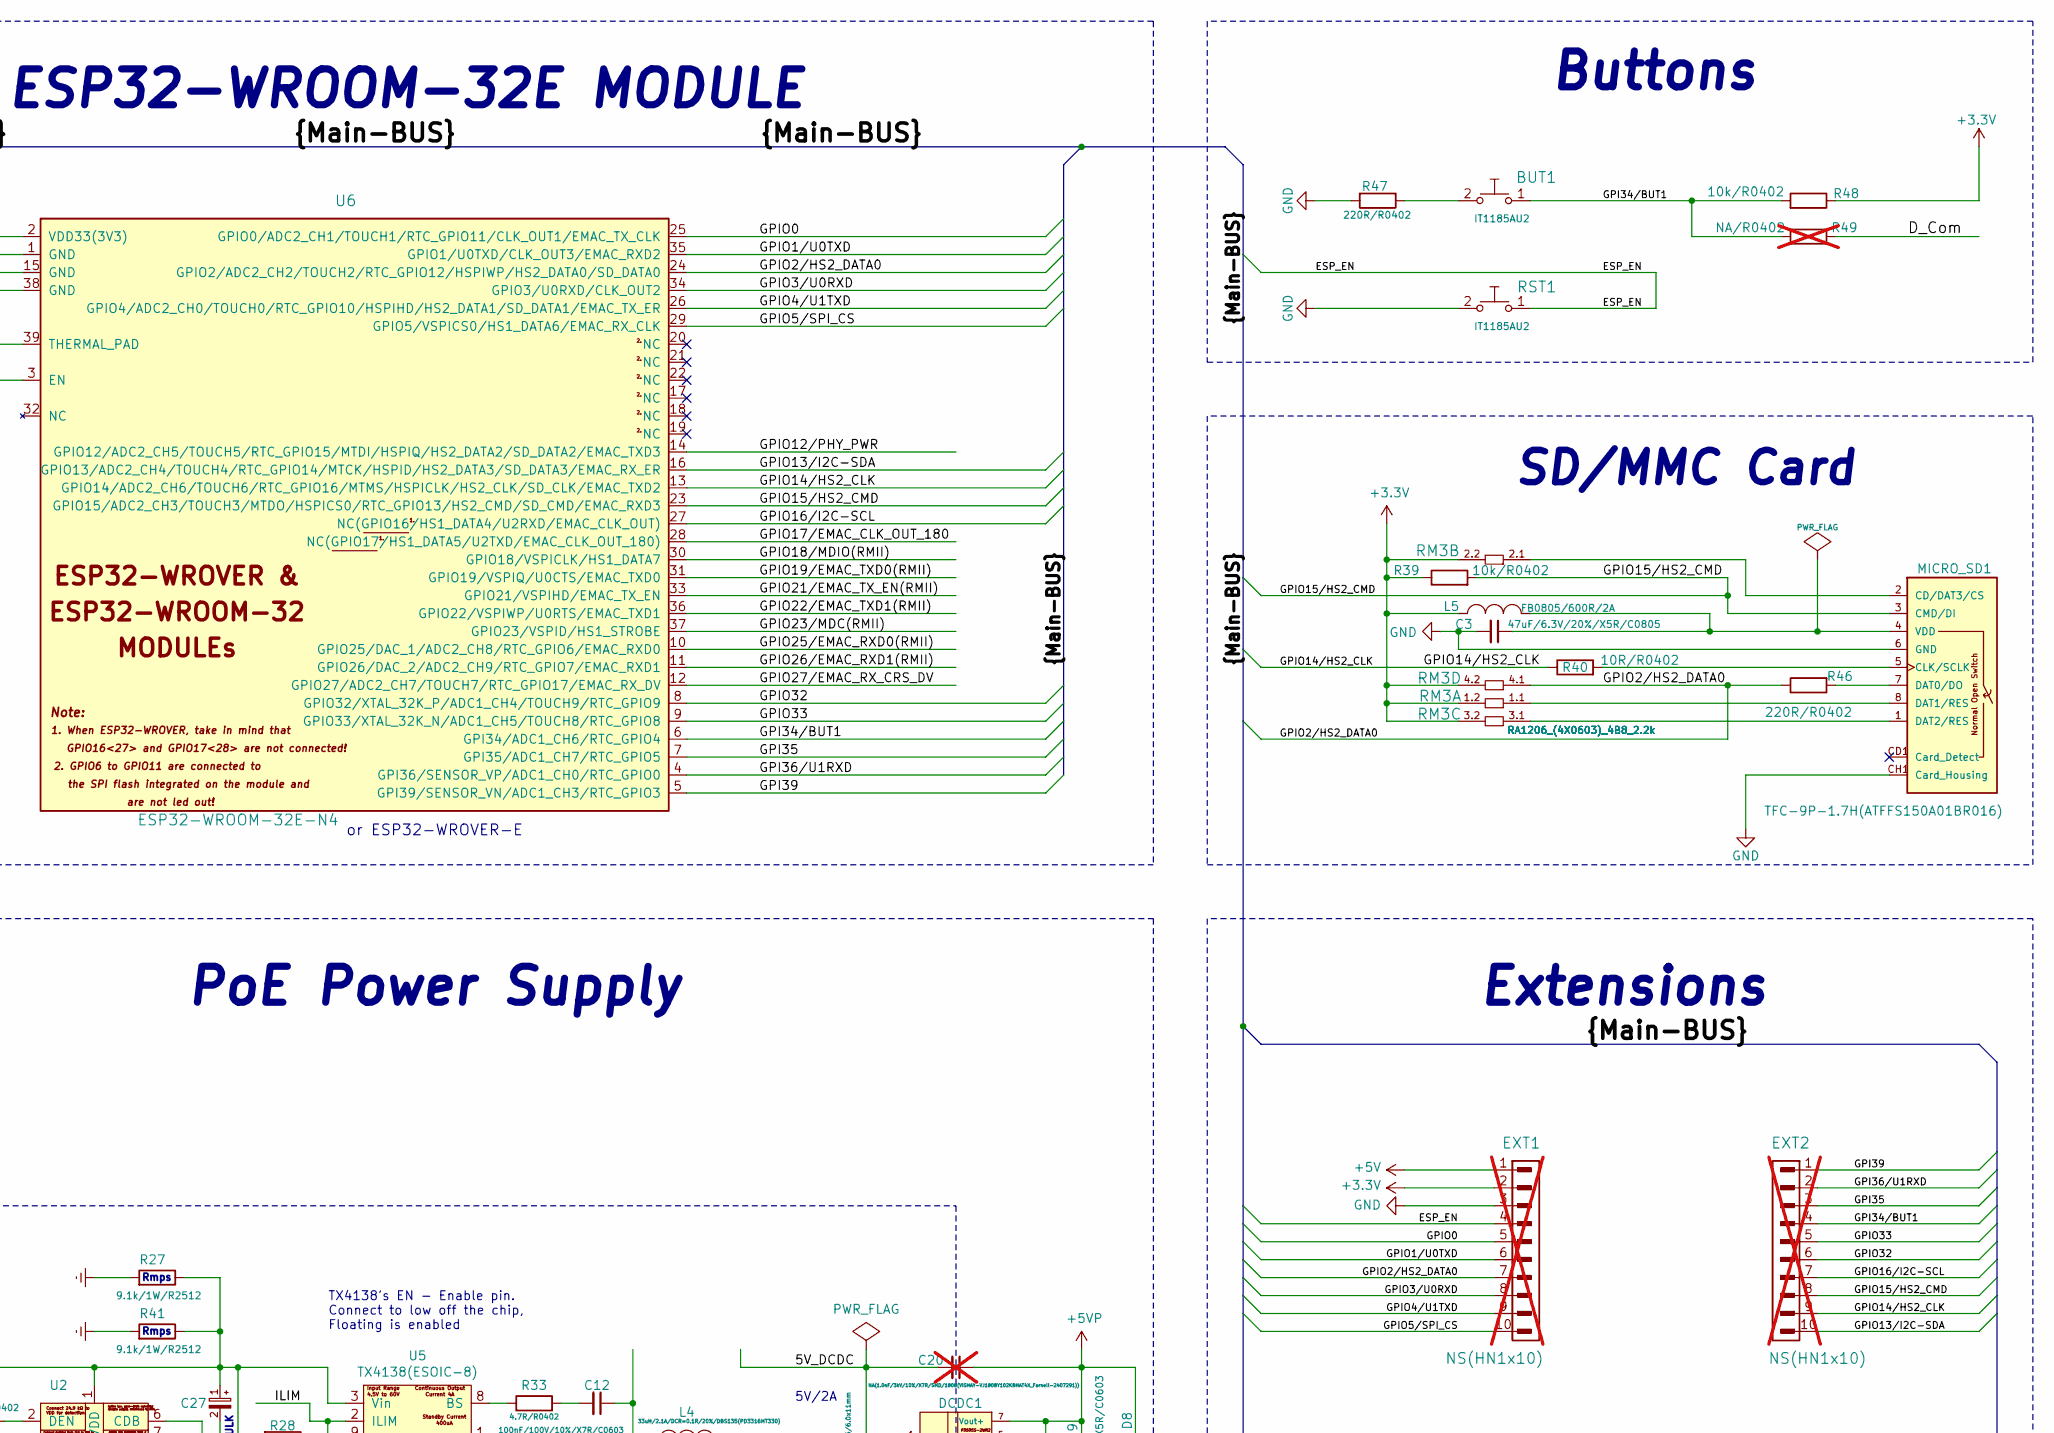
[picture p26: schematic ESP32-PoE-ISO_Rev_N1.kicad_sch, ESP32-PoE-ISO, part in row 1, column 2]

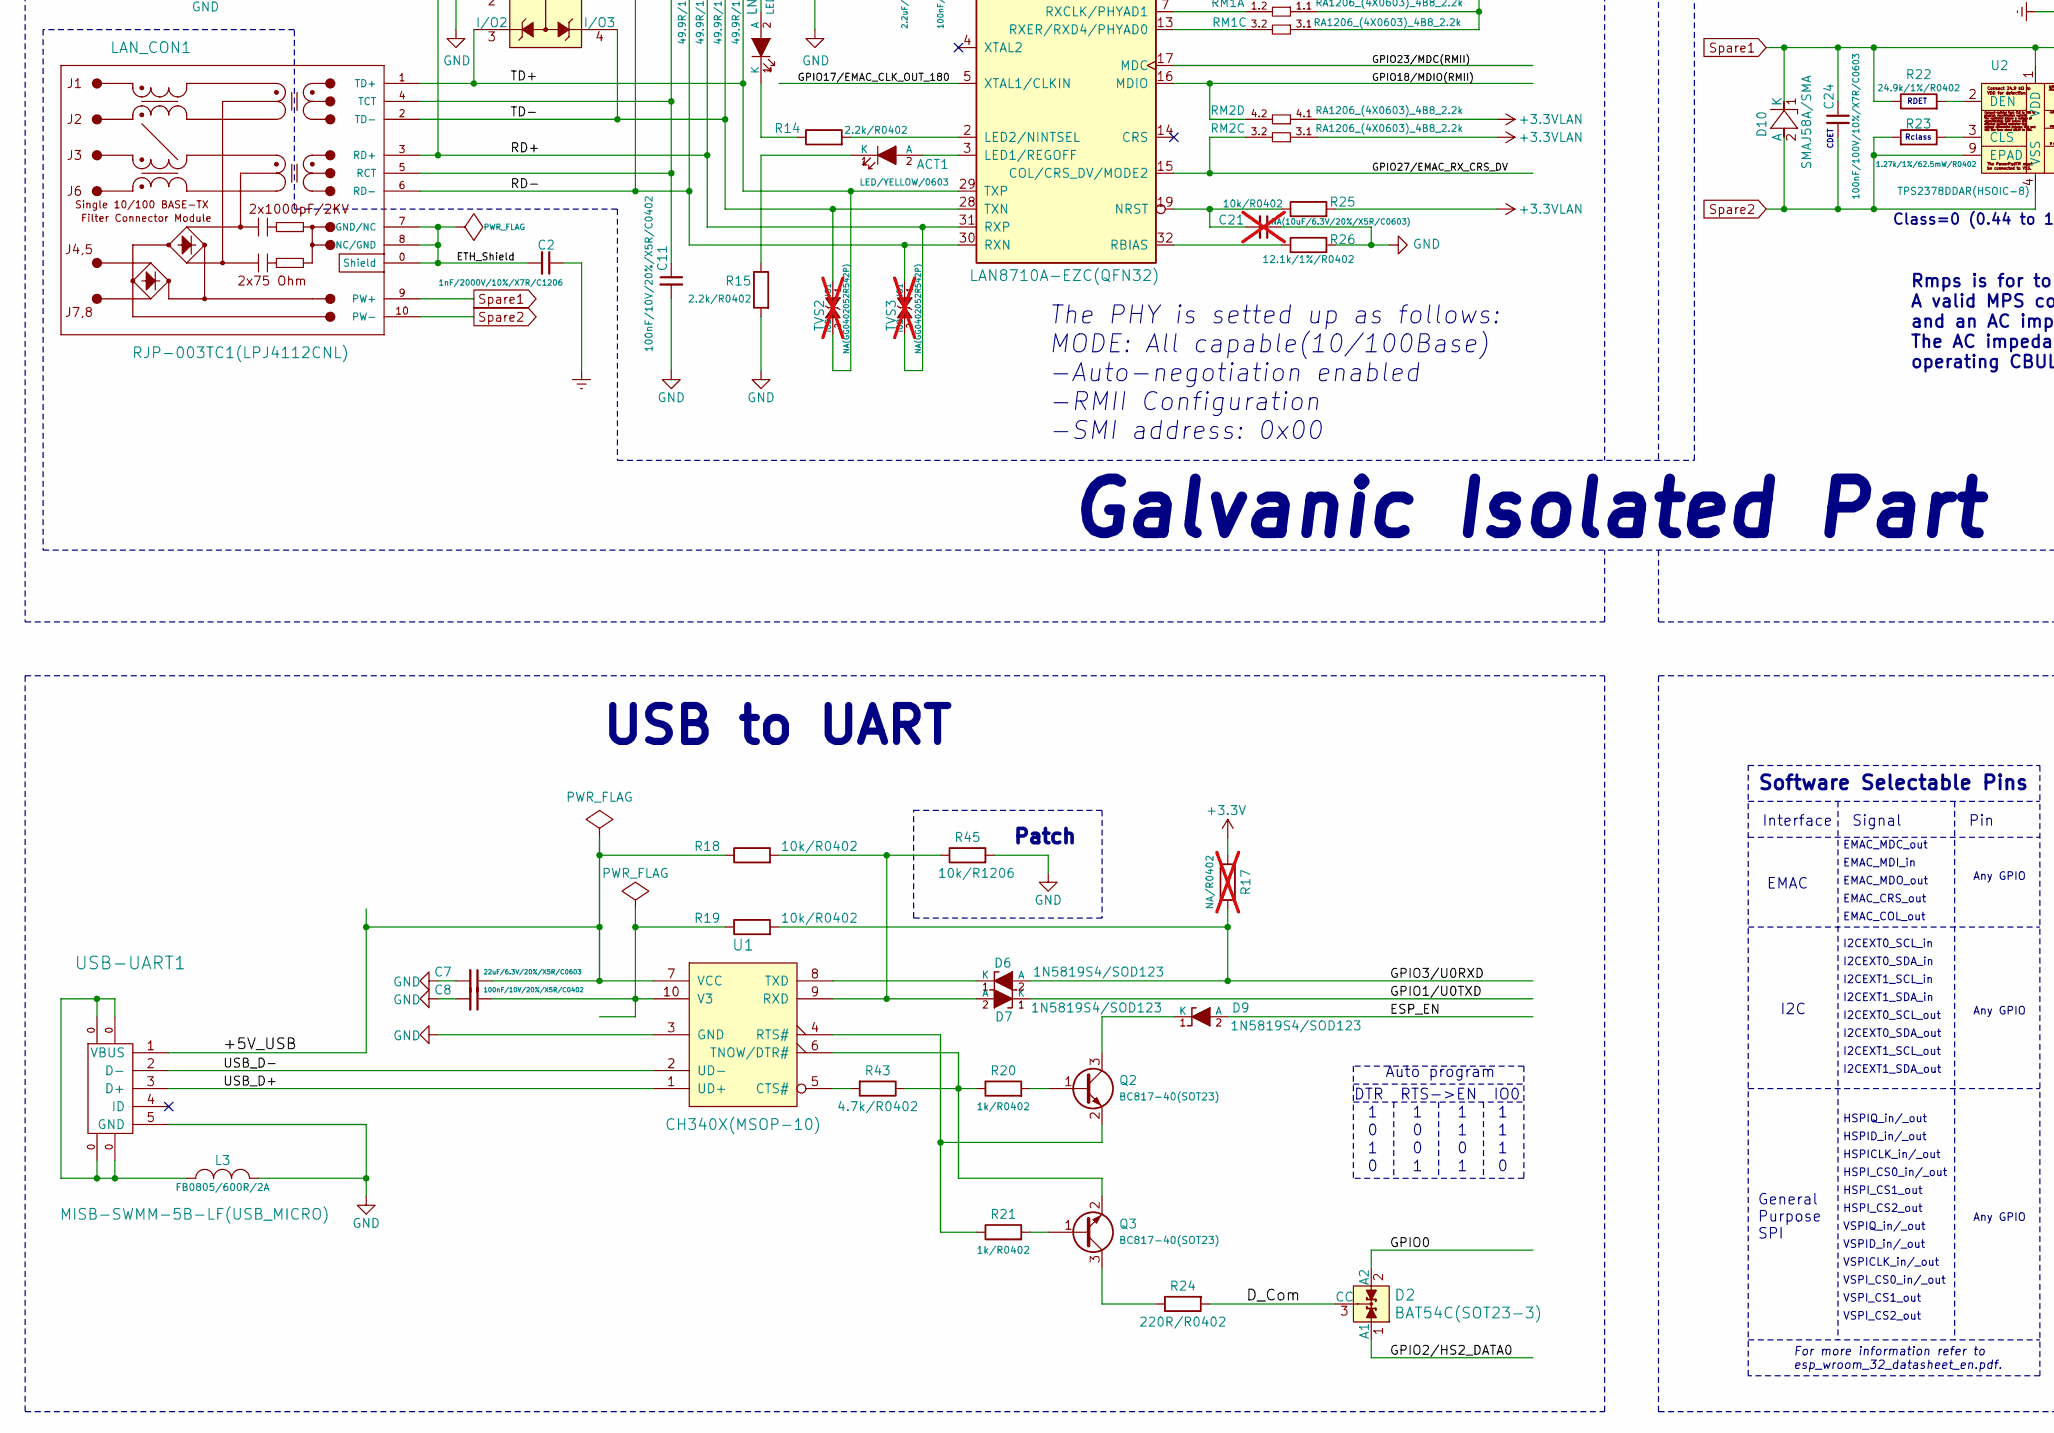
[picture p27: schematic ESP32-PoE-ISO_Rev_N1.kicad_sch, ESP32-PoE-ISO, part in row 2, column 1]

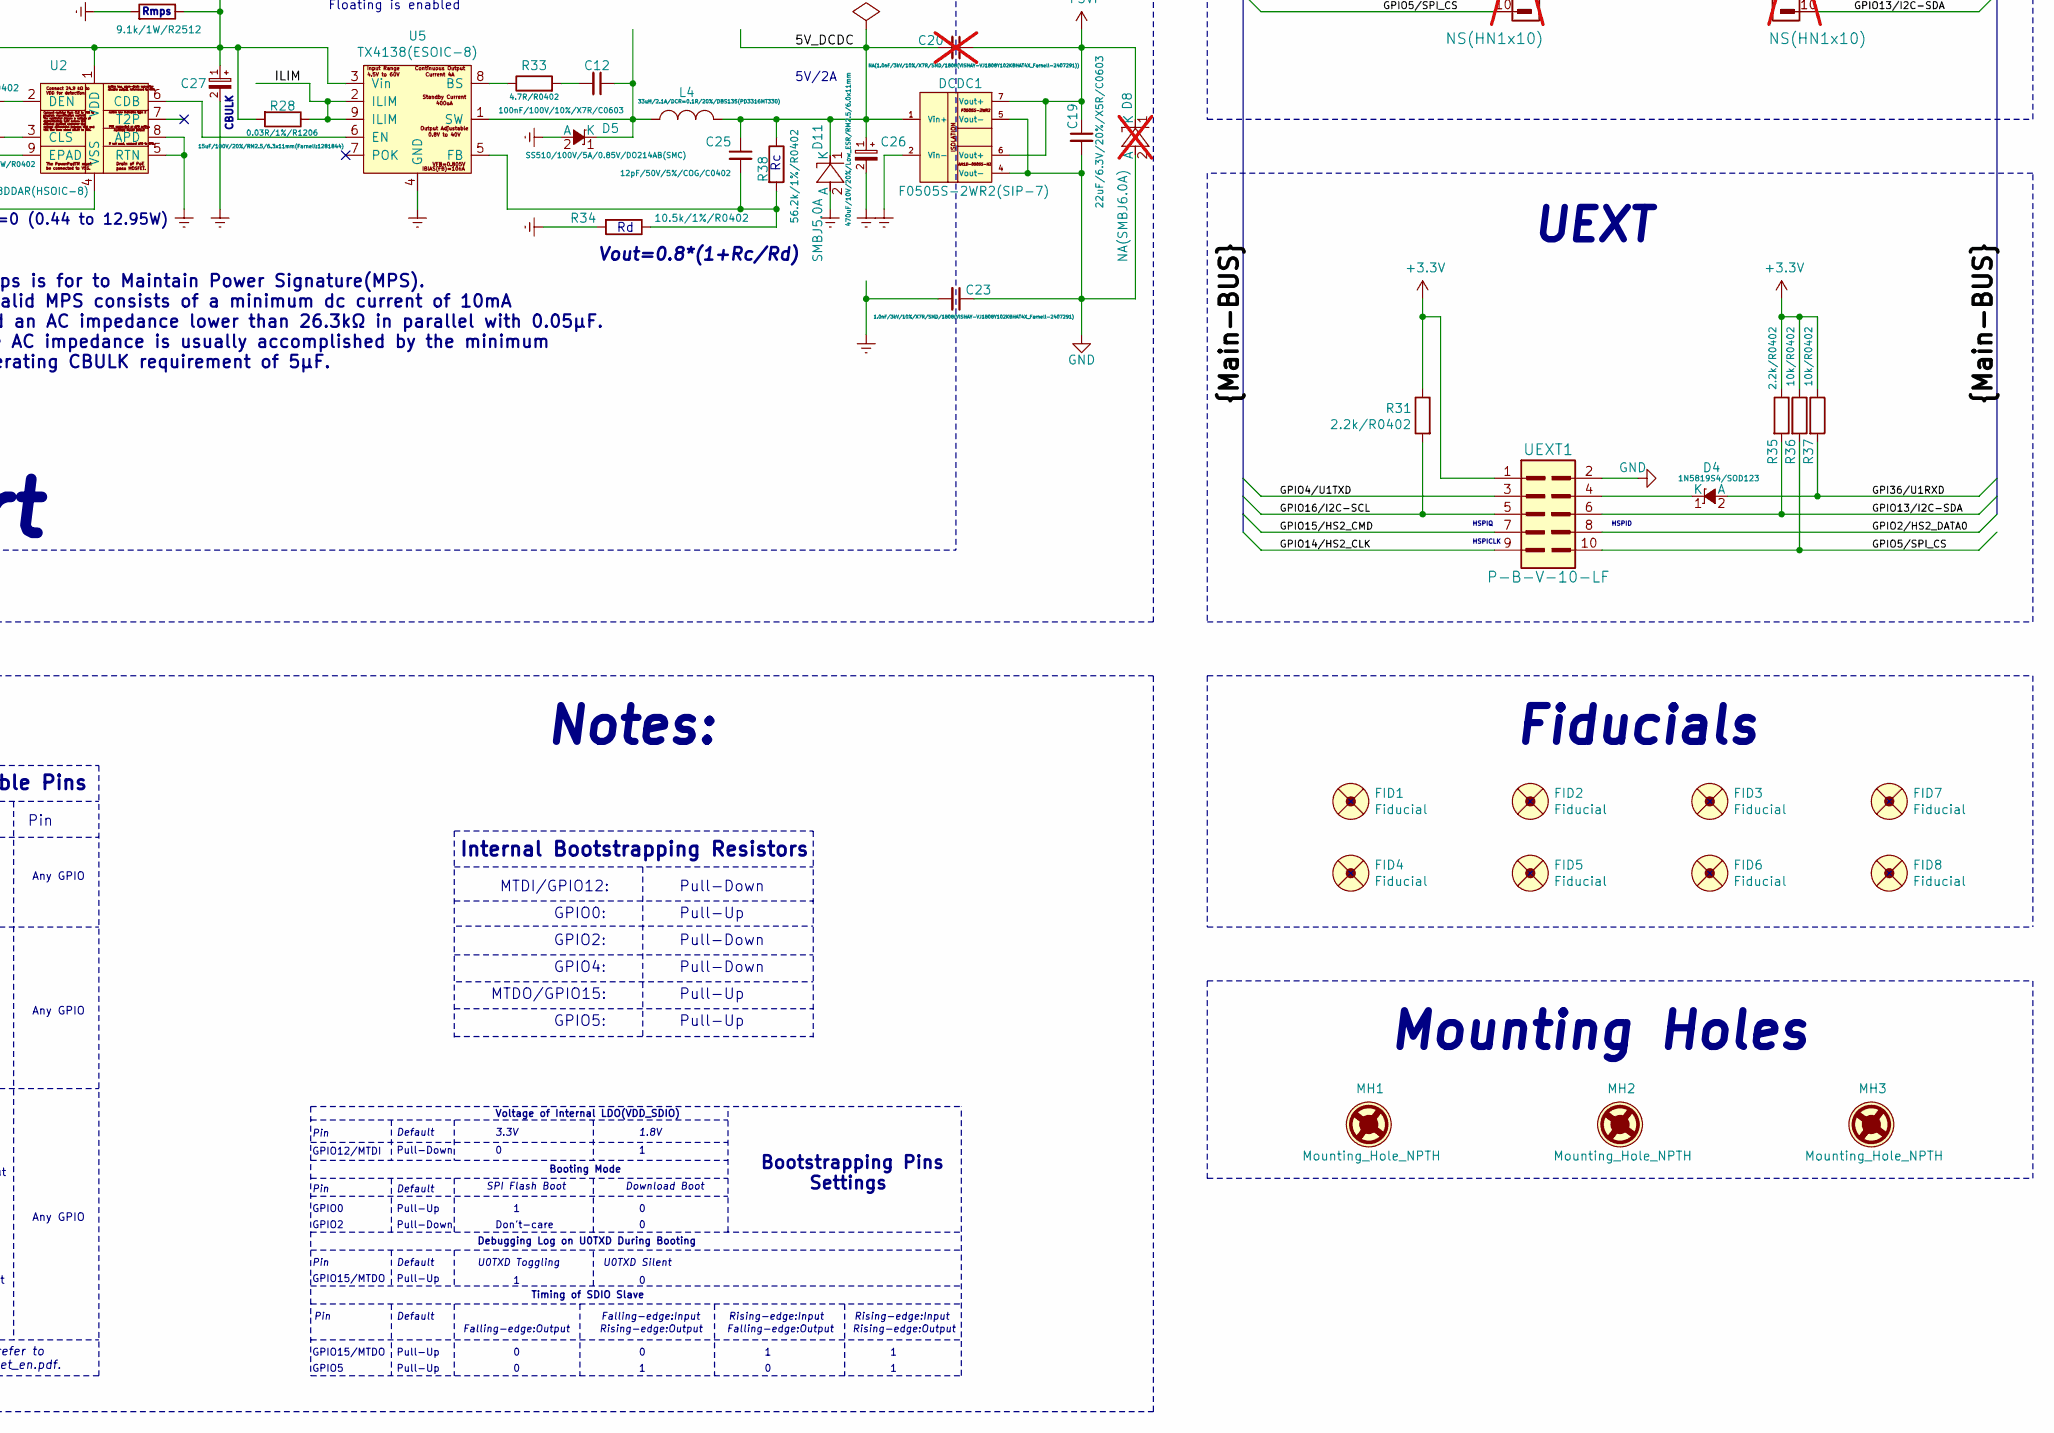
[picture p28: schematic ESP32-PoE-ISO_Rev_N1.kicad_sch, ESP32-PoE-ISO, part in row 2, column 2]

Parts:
ACT1: LED/YELLOW/0603; LED_0603_KA
BAT1: DW02S; LIPO_BAT_VERTICAL_DW02S
BUT1: IT1185AU2; IT1185AU2_V2
C1, C6, C7, C9, C10, C13, C19, C22: 22uF/6.3V/20%/X5R/C0603; C_0603_5MIL_DWS
C2: 1nF/2000V/10%/X7R/C1206; C_1206_5MIL_DWS_ISO
C3: 47uF/6.3V/20%/X5R/C0805; C_0805_5MIL_DWS
C8, C11, C14, C15, C16, C18: 100nF/10V/20%/X5R/C0402; C_0402_5MIL_DWS
C12, C24: 100nF/100V/10%/X7R/C0603; C_0603_5MIL_DWS
C17: 2.2uF/6.3V/10%/X5R/C0603; C_0603_5MIL_DWS
C20: NA(1.0nF/3kV/10%/X7R/SMD/1808(VISHAY-VJ1808Y102KB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; C_1808(4520)_5MIL_DWS_ISO; not fitted
C21: NA(10uF/6.3V/20%/X5R/C0603); C_0603_5MIL_DWS; not fitted
C23: 1.0nF/3kV/10%/X7R/SMD/1808(VISHAY-VJ1808Y102KBHAT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; C_1808(4520)_5MIL_DWS_ISO
C25: 12pF/50V/5%/COG/C0402; C_0402_5MIL_DWS
C26: 470uF/10V/20%/Low_ESR/RM2.5/6.0x11mm; CPOL-RM2.5mm_6.3x11mm_PTH
C27: 15uF/100V/20%/RM2.5/6.3x11mm(Farnell:1281844); CPOL-RM2.5mm_6.3x11mm_PTH
C28: 1nF/50V/10%/X7R/C0402; C_0402_5MIL_DWS
C29: NA(100nF/10V/20%/X5R/C0402); C_0402_5MIL_DWS; not fitted
C30: NA(120pF/50V/5%/C0G/C0402); C_0402_5MIL_DWS; not fitted
C31: 1uF/10V/10%/X5R/C0603; C_0603_5MIL_DWS
CHRG1: LED/YELLOW/0603; LED_0603_KA
D1, D3, D4, D6, D7, D9: 1N5819S4/SOD123; SOD-123_1C-2A_KA
D2: BAT54C(SOT23-3); SOT23-3
D5: SS510/100V/5A/0.85V/DO214AB(SMC); DO214AB(SMC)_1(K)-2(A)
D8: NA(SMBJ6.0A); DO214AA_1(K)-2(A); not fitted
D10: SMAJ58A/SMA; SMA-KA
D11: SMBJ5.0A; DO214AA_1(K)-2(A)
DCDC1: F0505S-2WR2(SIP-7); SIP-7_Universal
EXT1, EXT2: NS(HN1x10); HN1x10; not fitted
FET1, FET2, FET3: IRLML6402TRPbF; SOT23
FID1, FID4, FID7, FID8: Fiducial; Fiducial1x3_Paste
FID2, FID3, FID5, FID6: Fiducial; Fiducial1x3
L1, L3, L5: FB0805/600R/2A; L_0805_5MIL_DWS
L2: 1.0uH/4.2A/DCR=35mR/20%/2.00x1.60x1.00mm/L2016(PI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; L_2016_MM
L4: 33uH/2.1A/DCR=0.1R/20%/DBS135(PD3316MT330); DBS135
LAN_CON1: RJP-003TC1(LPJ4112CNL)
LNK1: LED/GREEN/0603; LED_0603_KA
MH1, MH2, MH3: Mounting_Hole_NPTH; NPTH_2.2mm
MICRO_SD1: TFC-9P-1.7H(ATFFS150A01BR016); uSD(TFC-9P-1.xH(ATFFS150A01BR016))
PWR1: LED/RED/0603; LED_0603_KA
Q2, Q3: BC817-40(SOT23); SOT23
R1, R2, R6, R18, R19, R25, R32, R36, R37, R39, R48: 10k/R0402; R_0402_5MIL_DWS
R3, R20, R21: 1k/R0402; R_0402_5MIL_DWS
R4: 47k/R0402; R_0402_5MIL_DWS
R5, R8, R14, R15, R31, R35: 2.2k/R0402; R_0402_5MIL_DWS
R7, R16: 470k/R0402; R_0402_5MIL_DWS
R9: 100k/R0402; R_0402_5MIL_DWS
R10, R11, R12, R13: 49.9R/1%/R0402; R_0402_5MIL_DWS
R17, R49: NA/R0402; R_0402_5MIL_DWS; not fitted
R22: 24.9k/1%/R0402; R_0402_5MIL_DWS
R23: 1.27k/1%/62.5mW/R0402; R_0402_5MIL_DWS
R24, R44, R46, R47: 220R/R0402; R_0402_5MIL_DWS
R26: 12.1k/1%/R0402; R_0402_5MIL_DWS
R27, R41: 9.1k/1W/R2512; R_2512_MM_DWS
R28: 0.03R/1%/R1206; R_1206_5MIL_DWS
R29: 220k/R0402; R_0402_5MIL_DWS
R30: 49.9k/1%/R0402; R_0402_5MIL_DWS
R33: 4.7R/R0402; R_0402_5MIL_DWS
R34: 10.5k/1%/R0402; R_0402_5MIL_DWS
R38: 56.2k/1%/R0402; R_0402_5MIL_DWS
R40: 10R/R0402; R_0402_5MIL_DWS
R42: NA(10R/R0402); R_0402_5MIL_DWS; not fitted
R43: 4.7k/R0402; R_0402_5MIL_DWS
R45: 10k/R1206; R_1206_5MIL_DWS
RM1, RM2, RM3: RA1206_(4X0603)_4B8_2.2k; R_MATRIX_4
RST1: IT1185AU2; IT1185AU2_V2
T1: LMUN2211LT1G(SOT-23); SOT23
TVS1: ESDS314DBVR(SOT-23-5); SOT-23-5
TVS2, TVS3: NA(GG0402052R542P); D_0402_5MIL_DWS; not fitted
U1: CH340X(MSOP-10); MSOP-10_Pitch-0.5mm_3.00x3.00x1.00mm
U2: TPS2378DDAR(HSOIC-8); ESOIC-8
U3: TP4054-42-SOT25-R(SOT23-5); SOT-23-5
U4: LAN8710A-EZC(QFN32); QFN32_EP(33)_5.00x5.00x0.90mm_Pitch_0.50mm
U5: TX4138(ESOIC-8); ESOIC-8
U6: ESP32-WROOM-32E-N4; ESP32-WROVER_MODULE
U7: TPS62A02ADRLR(SOT-563-6); SOT-563-6
U8: NA(SN74LVC1G04DBVR(SOT23-5)); SOT-23-5; not fitted
UEXT1: P-B-V-10-LF; GBH-254-SMT-10
USB-UART1: MISB-SWMM-5B-LF(USB_MICRO); USB-MICRO_MISB-SWMM-5B_LF

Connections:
+3.3V: C10.1, C22.1, C30.2, EXT1.2, FET3.2, L2.2, L5.1, R2.1, R17.1, R29.2, R31.1, R32.1, R35.1, R36.1, R37.1, R39.1, R48.1, RM3.1.2, RM3.2.2, RM3.3.2, RM3.4.2, U6.2 (VDD33(3V3)), UEXT1.1
+3.3VLAN: C9.1, C14.1, C29.2, FET3.3, L1.1, R25.2, RM1.4.1, RM2.1.1, RM2.2.1, RM2.3.1, RM2.4.1, U4.12 (VDDIO), U8.5 (VCC)
+5V: C1.1, CHRG1.2 (A), D1.1 (K), D3.2 (A), EXT1.1, FET1.2, FET2.1, PWR1.2 (A), R4.1, U3.4 (VCC)
+5VP: C19.1, C20.1, D1.2 (A), D8.1 (K), DCDC1.6 (Vout+), DCDC1.7 (Vout+), FET1.1, R1.1
/5V_DCDC: C20.2, C25.1, C26.1 (+), D11.1 (K), DCDC1.1 (Vin+), L4.2, R38.1
/+5V_USB: C7.1, FET1.3, R18.1, U1.7 (VCC), USB-UART1.1 (VBUS)
/D_Com: D2.3 (CC), R24.2, R49.2
/ESP_EN: C31.1, D9.2 (A), EXT1.4, R32.2, R44.2, RST1.1, U6.3 (EN)
/ETH_Shield: C2.2, LAN_CON1.0 (Shield), LAN_CON1.7 (GND/NC), LAN_CON1.8 (NC/GND)
/GPI34/BUT1: BUT1.1, EXT2.4, R48.2, R49.1, U6.6 (GPI34/ADC1_CH6/RTC_GPIO4)
/GPI35: C28.1, EXT2.3, R7.2, R16.1, U6.7 (GPI35/ADC1_CH7/RTC_GPIO5)
/GPI36/U1RXD: D4.2 (A), EXT2.2, R37.2, U6.4 (GPI36/SENSOR_VP/ADC1_CH0/RTC_GPIO0)
/GPI39: EXT2.1, R4.2, R9.1, U6.5 (GPI39/SENSOR_VN/ADC1_CH3/RTC_GPIO3)
/GPIO0: D2.2 (A2), EXT1.5, U6.25 (GPIO0/ADC2_CH1/TOUCH1/RTC_GPIO11/CLK_OU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), U8.2 (A)
/GPIO1/U0TXD: D7.1 (K), EXT1.6, U6.35 (GPIO1/U0TXD/CLK_OUT3/EMAC_RXD2)
/GPIO2/HS2_DATA0: D2.1 (A1), EXT1.7, R46.1, RM3.4.1, U6.24 (GPIO2/ADC2_CH2/TOUCH2/RTC_GPIO12/HSPIWP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), UEXT1.8
/GPIO3/U0RXD: D6.2 (A), EXT1.8, R17.2, R19.2, U6.34 (GPIO3/U0RXD/CLK_OUT2)
/GPIO4/U1TXD: EXT1.9, U6.26 (GPIO4/ADC2_CH0/TOUCH0/RTC_GPIO10/HSPIHD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), UEXT1.3
/GPIO5/SPI_CS: EXT1.10, R36.2, U6.29 (GPIO5/VSPICS0/HS1_DATA6/EMAC_RX_CLK), UEXT1.10
/GPIO12/PHY_PWR: T1.1 (B), U6.14 (GPIO12/ADC2_CH5/TOUCH5/RTC_GPIO15/MTDI/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)
/GPIO13/I2C-SDA: EXT2.10, R35.2, U6.16 (GPIO13/ADC2_CH4/TOUCH4/RTC_GPIO14/MTCK/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), UEXT1.6
/GPIO14/HS2_CLK: EXT2.9, R40.1, U6.13 (GPIO14/ADC2_CH6/TOUCH6/RTC_GPIO16/MTMS/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), UEXT1.9
/GPIO15/HS2_CMD: EXT2.8, MICRO_SD1.3 (CMD/DI), R39.2, U6.23 (GPIO15/ADC2_CH3/TOUCH3/MTDO/HSPICS0/RTC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), UEXT1.7
/GPIO16/I2C-SCL: EXT2.7, R31.2, R42.2, U6.27 (NC(GPIO16/HS1_DATA4/U2RXD/EMAC_CLK_OUT)), UEXT1.5
/GPIO17/EMAC_CLK_OUT_180: U4.5 (XTAL1/CLKIN), U6.28 (NC(GPIO17/HS1_DATA5/U2TXD/EMAC_CLK_OUT_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), U8.4 (Y)
/GPIO18/MDIO(RMII): RM2.4.2, U4.16 (MDIO), U6.30 (GPIO18/VSPICLK/HS1_DATA7)
/GPIO19/EMAC_TXD0(RMII): U4.22 (TXD0), U6.31 (GPIO19/VSPIQ/U0CTS/EMAC_TXD0)
/GPIO21/EMAC_TX_EN(RMII): U4.21 (TXEN), U6.33 (GPIO21/VSPIHD/EMAC_TX_EN)
/GPIO22/EMAC_TXD1(RMII): U4.23 (TXD1), U6.36 (GPIO22/VSPIWP/U0RTS/EMAC_TXD1)
/GPIO23/MDC(RMII): U4.17 (MDC), U6.37 (GPIO23/VSPID/HS1_STROBE)
/GPIO25/EMAC_RXD0(RMII): RM2.2.2, U4.11 (RXD0/MODE0), U6.10 (GPIO25/DAC_1/ADC2_CH8/RTC_GPIO6/EMAC_RX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)
/GPIO26/EMAC_RXD1(RMII): RM2.1.2, U4.10 (RXD1/MODE1), U6.11 (GPIO26/DAC_2/ADC2_CH9/RTC_GPIO7/EMAC_RX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)
/GPIO27/EMAC_RX_CRS_DV: RM2.3.2, U4.15 (COL/CRS_DV/MODE2), U6.12 (GPIO27/ADC2_CH7/TOUCH7/RTC_GPIO17/EMAC_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)
/GPIO32: EXT2.6, U6.8 (GPIO32/XTAL_32K_P/ADC1_CH4/TOUCH9/RTC_G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)
/GPIO33: EXT2.5, R42.1, U6.9 (GPIO33/XTAL_32K_N/ADC1_CH5/TOUCH8/RTC_G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)
/ILIM: R28.1, U5.2 (ILIM), U5.9 (ILIM)
/PG: R44.1, U7.6 (PG)
/RD+: LAN_CON1.3 (RD+), R11.2, TVS1.1 (I/O1), TVS3.2 (IO2), U4.31 (RXP)
/RD-: LAN_CON1.6 (RD-), R10.2, TVS1.5 (I/O4), TVS3.1 (IO1), U4.30 (RXN)
/TD+: LAN_CON1.1 (TD+), R13.2, TVS1.3 (I/O2), TVS2.2 (IO2), U4.29 (TXP)
/TD-: LAN_CON1.2 (TD-), R12.2, TVS1.4 (I/O3), TVS2.1 (IO1), U4.28 (TXN)
/USB_D+: U1.1 (UD+), USB-UART1.3 (D+)
/USB_D-: U1.2 (UD-), USB-UART1.2 (D-)
Earth: C2.1, C23.2, C26.2 (-), C27.2 (-), D5.2 (A), D11.2 (A), DCDC1.2 (Vin-), R27.2, R34.2, R41.2, U2.5 (RTN), U2.8 (APD), U5.4 (GND)
GND: BAT1.2, C1.2, C3.2, C6.2, C7.2, C8.2, C9.2, C11.2, C13.2, C14.2, C15.2, C16.2, C17.2, C18.2, C19.2, C21.1, C22.2, C23.1, C28.2, C29.1, C31.2, D8.2 (A), DCDC1.4 (Vout-), DCDC1.5 (Vout-), EXT1.3, L3.2, MICRO_SD1.6 (GND), MICRO_SD1.CH1 (Card_Housing), R1.2, R5.2, R6.2, R9.2, R15.2, R16.2, R26.2, R30.2, R45.2, R47.2, RM1.1.1, RM1.2.1, RM1.3.1, RST1.2, T1.2 (E), TVS1.2 (GND), U1.3 (GND), U3.2 (GND), U4.24 (TXD2), U4.25 (TXD3), U4.33 (GND), U6.1 (GND), U6.15 (GND), U6.38 (GND), U6.39 (THERMAL_PAD), U7.1 (GND), U8.3 (GND), UEXT1.2, USB-UART1.5 (GND)
unnamed: ACT1.2 (A), U4.3 (LED1/REGOFF)
unnamed: ACT1.1 (K), R15.1
unnamed: BUT1.2, R47.1
unnamed: C10.2, FET3.1, R2.2, R3.1
unnamed: C12.2, R33.2
unnamed: CHRG1.1 (K), R8.1
unnamed: C6.1, D3.1 (K), FET2.2, U7.3 (VIN), U7.4 (EN)
unnamed: D4.1 (K), UEXT1.4
unnamed: C12.1, D5.1 (K), L4.1, U5.1 (SW)
unnamed: D6.1 (K), U1.8 (TXD)
unnamed: D7.2 (A), R18.2, R45.1, U1.9 (RXD)
unnamed: D9.1 (K), Q2.3 (C)
unnamed: L3.1, USB-UART1.0
unnamed: C11.1, C13.1, C15.1, C16.1, L1.2, LAN_CON1.4 (TCT), LAN_CON1.5 (RCT), LNK1.2 (A), R10.1, R11.1, R12.1, R13.1, U4.1 (VDD2A), U4.27 (VDD1A)
unnamed: LNK1.1 (K), R14.1
unnamed: MICRO_SD1.2 (CD/DAT3/CS), RM3.2.1
unnamed: MICRO_SD1.5 (CLK/SCLK), R40.2
unnamed: MICRO_SD1.7 (DAT0/DO), R46.2
unnamed: MICRO_SD1.8 (DAT1/RES), RM3.1.1
unnamed: MICRO_SD1.1 (DAT2/RES), RM3.3.1
unnamed: C3.1, L5.2, MICRO_SD1.4 (VDD)
unnamed: PWR1.1 (K), R5.1
unnamed: Q2.1 (B), R20.2
unnamed: Q2.2 (E), R21.1, U1.4 (RTS#)
unnamed: Q3.1 (B), R21.2
unnamed: Q3.3 (C), R24.1
unnamed: Q3.2 (E), R20.1, R43.1, U1.6 (TNOW/DTR#)
unnamed: R3.2, T1.3 (C)
unnamed: R43.2, U1.5 (CTS#)
unnamed: C8.1, R19.1, U1.10 (V3)
unnamed: U2.6 (CDB), U5.6 (EN)
unnamed: R23.1, U2.3 (CLS)
unnamed: R22.2, U2.2 (DEN)
unnamed: R8.2, U3.1 (CHRGb)
unnamed: R6.1, U3.5 (PROG)
unnamed: BAT1.1, FET2.3, R7.1, U3.3 (VBAT)
unnamed: R14.2, U4.2 (LED2/NINTSEL)
unnamed: C21.2, R25.1, U4.19 (NRST)
unnamed: R26.1, U4.32 (RBIAS)
unnamed: RM1.1.2, U4.7 (RXCLK/PHYAD1)
unnamed: RM1.4.2, U4.9 (RXD2/RMIISEL)
unnamed: RM1.2.2, U4.8 (RXD3/PHYAD2)
unnamed: RM1.3.2, U4.13 (RXER/RXD4/PHYAD0)
unnamed: C17.1, C18.1, U4.6 (VDDCR)
unnamed: R33.1, U5.8 (BS)
unnamed: C25.2, R34.1, R38.2, U5.5 (FB)
unnamed: C30.1, R29.1, R30.1, U7.5 (FB)
unnamed: L2.1, U7.2 (SW)
Spare1: C24.1, C27.1 (+), D10.1 (K), LAN_CON1.9 (PW+), R22.1, R27.1, R28.2, R41.1, U2.1 (VDD), U5.3 (Vin)
Spare2: C24.2, D10.2 (A), LAN_CON1.10 (PW-), R23.2, U2.4 (VSS), U2.9 (EPAD)

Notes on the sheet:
Don't-care
CHARGING
General Purpose SPI
Pull-Down
Default
LiPo Charger
EMAC_MDC_out
Software Selectable Pins
Rmps
ESP32-WROOM-32E MODULE
VSPID_in/_out
Bootstrapping Pins Settings
Patch
Class=0 (0.44 to 12.95W)
MTDI/GPIO12:
GPIO0
I2CEXT0_SCL_in
Any GPIO
EMAC_MDI_in
Falling-edge:Input
VSPICLK_in/_out
HSPI_CS1_out
GPIO15/MTDO
Internal Bootstrapping Resistors
Booting Mode
Mounting Holes
UEXT
USB to UART
Download Boot
EMAC_MDO_out
Falling-edge:Output
GPIO5:
External Power Sense
GPIO0:
SPI Flash Boot
TX4138's EN - Enable pin. Connect to low off the chip, Floating is enabled
Rclass
Extensions
or ESP32-WROVER-E
1.8V

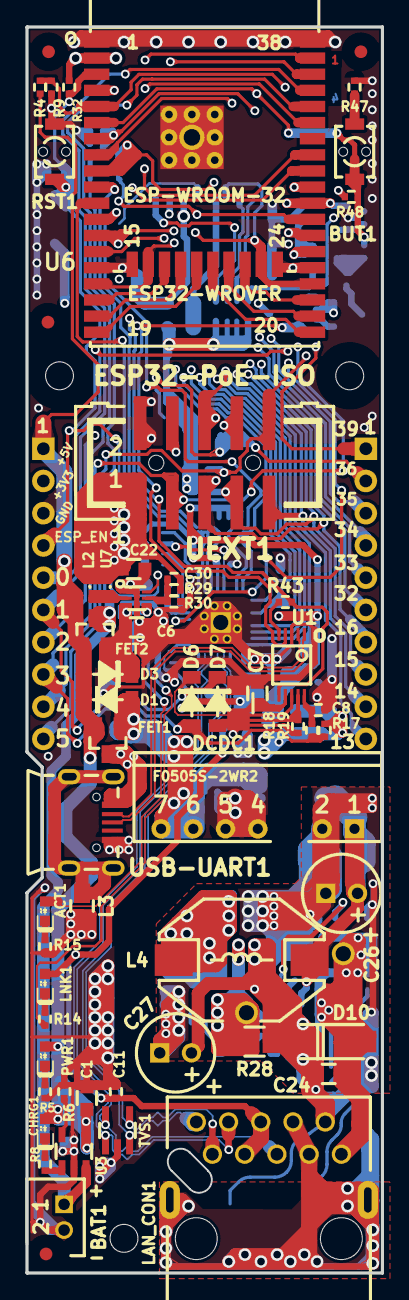
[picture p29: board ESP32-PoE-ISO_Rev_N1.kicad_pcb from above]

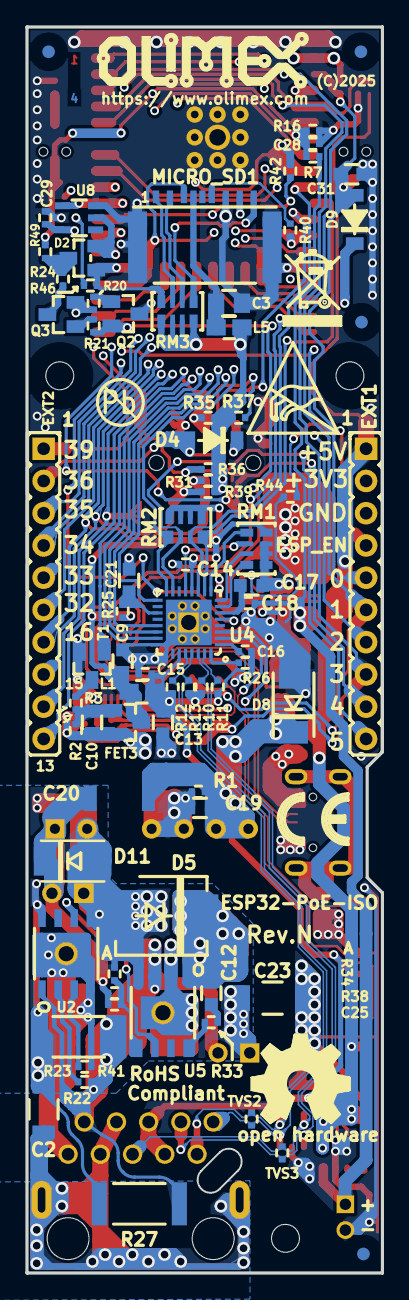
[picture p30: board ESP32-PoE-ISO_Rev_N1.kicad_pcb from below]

Board: 4 copper layers, 28.0 x 98.2 mm, 146 parts (84 on the bottom side), 95 nets.

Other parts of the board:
Drill_Slot3: 2 mm; Mounting_hole_2_mm
Logo_OSHW: Sign_OSHW_8x8
Logo_Olimex: Logo_OLIMEX_TB
Sign_Antistatic: Val**; Sign_Antistatic
Sign_CE: CE_Sign
Sign_PB-Free: Sign_PB-Free
Sign_RecycleBin: Sign_RecycleBin_1

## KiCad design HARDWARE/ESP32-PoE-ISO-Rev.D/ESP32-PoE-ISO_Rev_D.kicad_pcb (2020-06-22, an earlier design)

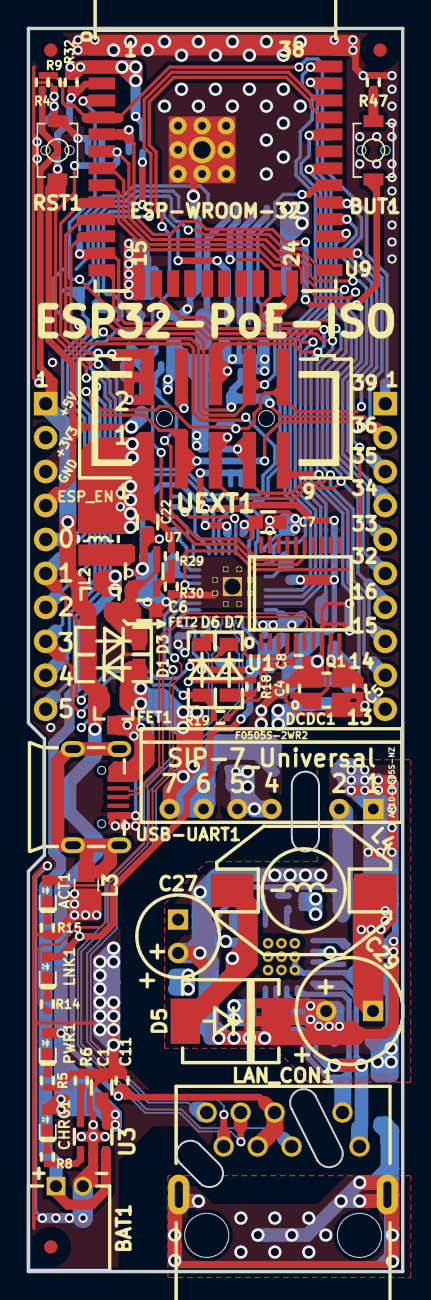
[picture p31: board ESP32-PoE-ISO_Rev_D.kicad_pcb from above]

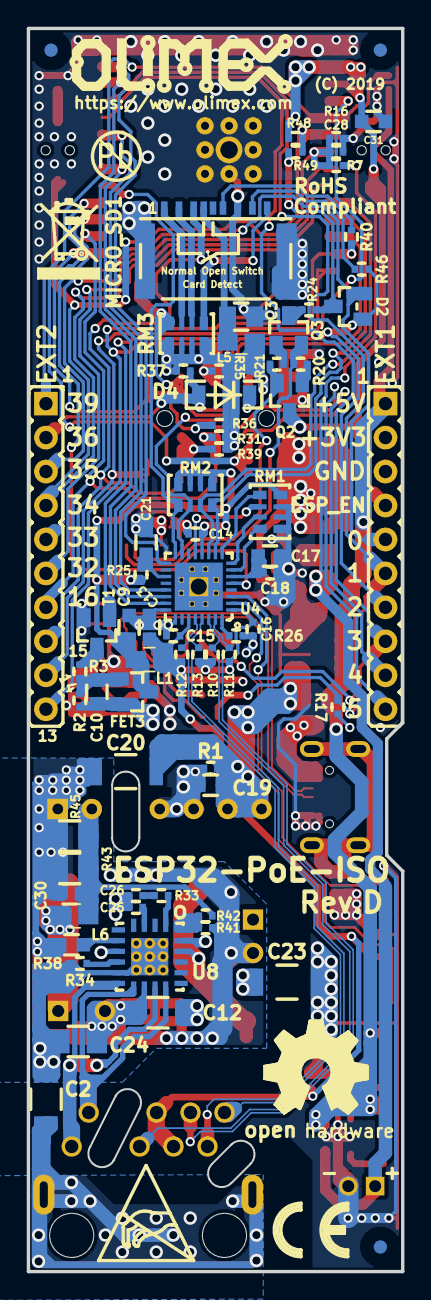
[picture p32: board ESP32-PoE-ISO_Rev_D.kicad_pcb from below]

Board: 4 copper layers, 28.0 x 93.0 mm, 133 parts (78 on the bottom side), 96 nets.

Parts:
ACT1: LED/YELLOW/0603; LED_0603_KA
BAT1: DW02R; LIPO_BAT-CON2DW02R
BUT1: IT1185AU2; IT1185AU2_V2
C1, C6, C7, C9, C10, C13, C19, C22, C30: 22uF/6.3V/20%/X5R/C0603; C_0603_5MIL_DWS
C2: 1nF/2000V/10%/X7R/C1206; C_1206_5MIL_DWS_ISO
C3: 47uF/6.3V/20%/X5R/C0805; C_0805_5MIL_DWS
C4, C5: 27pF/50V/5%/C0G/C0402; C_0402_5MIL_DWS
C8, C11, C14, C15, C16, C18, C25: 100nF/16V/10%/X7R/C0402; C_0402_5MIL_DWS
C12: 2.2uF/100V/20%/X7R/C1206(AVX_12061C225KAT2A_Comet); C_1206_5MIL_DWS_ISO
C17: 2.2uF/6.3V/10%/X5R/C0603; C_0603_5MIL_DWS
C20, C23: 1.0nF/3kV/10%/X7R/SMD/1808(VISHAY-VJ1808Y102KBHAT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; C_1808(4520)_5MIL_DWS_ISO
C21: NA(10uF/6.3V/20%/X5R/C0603); C_0603_5MIL_DWS
C24: 100nF/100V/20%/C1206; C_1206_5MIL_DWS
C26, C28: 1nF/50V/10%/X7R/C0402; C_0402_5MIL_DWS
C27: 15uF/100V/20%/RM2.5/6.3x11mm(Farnell:1281844); CPOL-RM2.5mm_6.3x11mm_PTH
C29: 680uF/10V/20%/105C/RM3.5/8x11.5mm; CPOL-RM3.5mm_8.0x11.5mm_PTH
C31: 1uF/10V/20%/X5R/C0603; C_0603_5MIL_DWS
CE_Sign: CE_Sign
CHRG1: LED/YELLOW/0603; LED_0603_KA
D1, D3, D6, D7: 1N5819S4/SOD123; SOD-123_1C-2A_KA
D2: BAT54C(SOT23-3); SOT23-3
D4: 1N5819S4/SOD-123; SOD-123_1C-2A_KA
D5: SS510/100V/5A/0.85V/DO214AB(SMC); DO214AB(SMC)_1(K)-2(A)
DCDC1: F0505S-2WR2(SIP-7); SIP-7_Universal
Drill_Slot1, Drill_Slot2, Drill_Slot3: 2 mm; Mounting_hole_2_mm
EXT1, EXT2: NS(HN1x10); HN1x10
FET1, FET2, FET3: WPM2015-3/TR; SOT23
FID1, FID2, FID3, FID4, FID5, FID6: Fiducial; Fiducial1x3
L1, L3, L5, L6: FB0805/600R/2A; L_0805_5MIL_DWS
L2: 2.2uH/1.5A/DCR=72mR/20%/3.00x3.00x1.50mm/CD32(NR3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; CD32
L4: 33uH/2.1A/DCR=0.1R/20%/DBS135(PD3316MT330); DBS135
LAN_CON1: RJP-003TC1(LPJ4112CNL)---Pin<7>_and_<8>_to_be_CUT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; RJP-003TC1(LPJ4112CNL)-ISO(Pin(7)and(8)CUT)
LNK1: LED/GREEN/0603; LED_0603_KA
Logo_OSHW: LOGO_OPENHARDWARE_8x8
Logo_Olimex: OLIMEX_LOGO_TB
MICRO_SD1: TFC-9P-1.7H(ATFFS150A01BR016); uSD(TFC-9P-1.xH(ATFFS150A01BR016))
PWR1: LED/RED/0603; LED_0603_KA
Q1: Q12MHz/20pF/10ppm/4P/3.2x2.5mm; TSX-3.2x2.5mm_GND(3)
Q2, Q3: BC817-40(SOT23); SOT23
R1, R2, R6, R18, R19, R25, R32, R36, R37, R39, R48: 10k/R0402; R_0402_5MIL_DWS
R3, R20, R21: 1k/R0402; R_0402_5MIL_DWS
R4, R33: 47k/R0402; R_0402_5MIL_DWS
R5, R8, R14, R15, R31, R35: 2.2k/R0402; R_0402_5MIL_DWS
R7, R16: 470k/R0402; R_0402_5MIL_DWS
R9: 100k/R0402; R_0402_5MIL_DWS
R10, R11, R12, R13: 49.9R/1%/R0402; R_0402_5MIL_DWS
R17: NA; R_0402_5MIL_DWS
R24, R46, R47: 220R/R0402; R_0402_5MIL_DWS
R26: 12.1k/1%/R0402; R_0402_5MIL_DWS
R29: 220k/R0402; R_0402_5MIL_DWS
R30: 49.9k/1%/R0402; R_0402_5MIL_DWS
R34: NA(49.9R/1%/R0402); R_0402_5MIL_DWS
R38: 25.5k/1%/R0603; R_0603_5MIL_DWS
R40: 10R/R0402; R_0402_5MIL_DWS
R41: 1.05k/1%/R0402; R_0402_5MIL_DWS
R42: 3.01k/1%/R0402; R_0402_5MIL_DWS
R43, R45: 220R/5%/0.25W/R1206; R_1206_5MIL_DWS
R49: NA/R0402; R_0402_5MIL_DWS
RM1, RM2, RM3: RA1206_(4X0603)_4B8_2.2k; R_MATRIX_4
RST1: IT1185AU2; IT1185AU2_V2
Sign_Antistatic: Val**; LOGO_ANTISTATIC_1
Sign_PB-Free: LOGO_PBFREE
Sign_RecycleBin: LOGO_RECYCLEBIN_1
T1: DTC114YKA(SOT-23); SOT23
U1: CH340T(SSOP20W); SSOP-20W
U3: BL4054B-42TPRN(SOT23-5); SOT-23-5
U4: LAN8710A-EZC(QFN32); QFN32_EP(33)_5.00x5.00x0.90mm_Pitch_0.50mm
U7: SY8089AAAC(SOT23-5); SOT-23-5
U8: Si3402-B-GM(QFN-20_5x5mm); QFN-20_5x5mm(Si3402-B-GM)
U9: ESP32-WROOM-32D-4MB; ESP-WROOM-32_MODULE
UEXT1: P-B-V-10-LF; GBH-254-SMT-10
USB-UART1: MISB-SWMM-5B-LF(USB_MICRO); USB-MICRO_MISB-SWMM-5B_LF

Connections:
+3.3VLAN: C9.1, C14.1, FET3.3, L1.1, R25.2, RM1.4.1, RM2.1.1, RM2.2.1, RM2.3.1, RM2.4.1, U4.12
+3V3: C10.1, C22.1, EXT1.2, FET3.2, L2.2, L5.1, R2.1, R17.1, R29.2, R31.1, R32.1, R35.1, R36.1, R37.1, R39.1, R48.1, RM3.1.2, RM3.2.2, RM3.3.2, RM3.4.2, U9.2, UEXT1.1
+5V: C1.1, CHRG1.2, D1.1, D3.2, EXT1.1, FET1.2, FET2.1, PWR1.2, R4.1, U3.4
+5VP: C19.1, C20.1, D1.2, DCDC1.6, DCDC1.7, FET1.1, R1.1
/+5V_USB: C7.1, FET1.3, R18.1, U1.19, USB-UART1.1
/D_Com: D2.3, R24.2, R49.2
/ESP_EN: C31.1, EXT1.4, Q2.3, R32.2, RST1.1, U9.3
/GPI34/BUT1: BUT1.1, EXT2.4, R48.2, R49.1, U9.6
/GPI35: C28.1, EXT2.3, R7.2, R16.1, U9.7
/GPI36/U1RXD: D4.2, EXT2.2, R37.2, U9.4
/GPI39: EXT2.1, R4.2, R9.1, U9.5
/GPIO0: D2.2, EXT1.5, U9.25
/GPIO1/U0TXD: D7.1, EXT1.6, U9.35
/GPIO2/HS2_DATA0: D2.1, EXT1.7, R46.1, RM3.4.1, U9.24, UEXT1.8
/GPIO3/U0RXD: D6.2, EXT1.8, R17.2, R19.2, U9.34
/GPIO4/U1TXD: EXT1.9, U9.26, UEXT1.3
/GPIO5/SPI_CS: EXT1.10, R36.2, U9.29, UEXT1.10
/GPIO12/PHY_PWR: T1.1, U9.14
/GPIO13/I2C-SDA: EXT2.10, R35.2, U9.16, UEXT1.6
/GPIO14/HS2_CLK: EXT2.9, R40.1, U9.13, UEXT1.9
/GPIO15/HS2_CMD: EXT2.8, MICRO_SD1.3, R39.2, U9.23, UEXT1.7
/GPIO16/I2C-SCL: EXT2.7, R31.2, U9.27, UEXT1.5
/GPIO17/EMAC_CLK_OUT_180: U4.5, U9.28
/GPIO18/MDIO(RMII): RM2.4.2, U4.16, U9.30
/GPIO19/EMAC_TXD0(RMII): U4.22, U9.31
/GPIO21/EMAC_TX_EN(RMII): U4.21, U9.33
/GPIO22/EMAC_TXD1(RMII): U4.23, U9.36
/GPIO23/MDC(RMII): U4.17, U9.37
/GPIO25/EMAC_RXD0(RMII): RM2.2.2, U4.11, U9.10
/GPIO26/EMAC_RXD1(RMII): RM2.1.2, U4.10, U9.11
/GPIO27/EMAC_RX_CRS_DV: RM2.3.2, U4.15, U9.12
/GPIO32: EXT2.6, U9.8
/GPIO33: EXT2.5, U9.9
/RD+: LAN_CON1.3, R11.2, U4.31
/RD-: LAN_CON1.6, R10.2, U4.30
/Shield: C2.2, LAN_CON1.0
/TD+: LAN_CON1.1, R13.2, U4.29
/TD-: LAN_CON1.2, R12.2, U4.28
/USB_D+: U1.6, USB-UART1.3
/USB_D-: U1.7, USB-UART1.2
/Vpos: C12.1, C20.2, C24.1, C27.1, C29.1, C30.1, D5.1, DCDC1.1, R38.2, R41.1, R43.1, R45.1, U8.12
/Vss: C12.2, C25.2, C26.2, C27.2, U8.7, U8.19
Earth: C2.1, C23.2, C24.2, R34.1, U8.9, U8.21
GND: BAT1.2, C1.2, C3.2, C4.2, C5.2, C6.2, C7.2, C8.2, C9.2, C11.2, C13.2, C14.2, C15.2, C16.2, C17.2, C18.2, C19.2, C21.1, C22.2, C23.1, C28.2, C31.2, DCDC1.4, DCDC1.5, EXT1.3, L3.2, MICRO_SD1.6, MICRO_SD1.CH1, Q1.3, R1.2, R5.2, R6.2, R9.2, R15.2, R16.2, R26.2, R30.2, R47.2, RM1.1.1, RM1.2.1, RM1.3.1, RST1.2, T1.2, U1.8, U3.2, U4.24, U4.25, U4.33, U7.2, U9.1, U9.15, U9.38, U9.39, UEXT1.2, USB-UART1.5
unnamed: ACT1.1, R15.1
unnamed: ACT1.2, U4.3
unnamed: BAT1.1, FET2.3, R7.1, U3.3
unnamed: BUT1.2, R47.1
unnamed: C3.1, L5.2, MICRO_SD1.4
unnamed: C4.1, Q1.1, U1.9
unnamed: C5.1, Q1.2, U1.10
unnamed: C6.1, D3.1, FET2.2, U7.1, U7.4
unnamed: C8.1, R19.1, U1.5
unnamed: C10.2, FET3.1, R2.2, R3.1
unnamed: C11.1, C13.1, C15.1, C16.1, L1.2, LAN_CON1.4, LAN_CON1.5, LNK1.2, R10.1, R11.1, R12.1, R13.1, U4.1, U4.27
unnamed: C17.1, C18.1, U4.6
unnamed: C21.2, R25.1, U4.19
unnamed: C25.1, U8.3
unnamed: C26.1, R33.1
unnamed: C29.2, L4.2, L6.1
unnamed: C30.2, DCDC1.2, L6.2, R42.2, R43.2, R45.2
unnamed: CHRG1.1, R8.1
unnamed: D4.1, UEXT1.4
unnamed: D5.2, L4.1, U8.18
unnamed: D6.1, U1.3
unnamed: D7.2, R18.2, U1.4
unnamed: L2.1, U7.3
unnamed: L3.1, USB-UART1.0
unnamed: LNK1.1, R14.1
unnamed: MICRO_SD1.1, RM3.3.1
unnamed: MICRO_SD1.2, RM3.2.1
unnamed: MICRO_SD1.5, R40.2
unnamed: MICRO_SD1.7, R46.2
unnamed: MICRO_SD1.8, RM3.1.1
unnamed: PWR1.1, R5.1
unnamed: Q2.1, R20.2
unnamed: Q2.2, R21.1, U1.16
unnamed: Q3.1, R21.2
unnamed: Q3.2, R20.1, U1.15
unnamed: Q3.3, R24.1
unnamed: R3.2, T1.3
unnamed: R6.1, U3.5
unnamed: R8.2, U3.1
unnamed: R14.2, U4.2
unnamed: R26.1, U4.32
unnamed: R29.1, R30.1, U7.5
unnamed: R33.2, U8.1
unnamed: R34.2, U8.8
unnamed: R38.1, U8.6
unnamed: R41.2, R42.1, U8.20
unnamed: RM1.1.2, U4.7
unnamed: RM1.2.2, U4.8
unnamed: RM1.3.2, U4.13
unnamed: RM1.4.2, U4.9
Spare1: LAN_CON1.9, U8.11, U8.14
Spare2: LAN_CON1.10, U8.10, U8.13

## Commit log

2019-04-12 Initial upload of ESP32-POE-ISO hardware files
    [BAT54.step, CD32_inductor.step, Cap_8x11_5x3_5mm.step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]
2019-09-10 Update
    Revision C and 3D added
    [BAT54.step, Cap_8x11_5x3_5mm.step, Cap_PTH_6_3x11x2_5mm.step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]
2020-06-22 Update
    Revision D
    [BAT54.step, Cap_8x11_5x3_5mm.step, Cap_PTH_6_3x11x2_5mm.step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]
2021-11-05 update
    new revision
    [BAT54.step, Cap_PTH_6_3x11x2_5mm.step, Connector_1Port_RJ45_Magjack_10-100Base-T_AutoMDIX_PoE_Wurth_Electronics-7499211002A_DigiKey-732-4976-ND.step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]
2022-01-18 Update
    revision H
    [BAT54.step, Cap_PTH_6_3x11x2_5mm.step, Connector_1Port_RJ45_Magjack_10-100Base-T_AutoMDIX_PoE_Wurth_Electronics-7499211002A_DigiKey-732-4976-ND.step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]
2022-07-14 Update
    Hardware revision I
    [BAT54.step, Cap_PTH_6_3x11x2_5mm.step, Connector_1Port_RJ45_Magjack_10-100Base-T_AutoMDIX_PoE_Wurth_Electronics-7499211002A_DigiKey-732-4976-ND.step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]
2022-07-18 Update
    Added dimensions for upcoming revision J with mount holes
2022-11-15 Update
    Revisions J and K
    [BAT54.step, Cap_PTH_6_3x11x2_5mm.step, Connector_1Port_RJ45_Magjack_10-100Base-T_AutoMDIX_PoE_Wurth_Electronics-7499211002A_DigiKey-732-4976-ND.step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]
2023-05-11 Update
    revision L files
    [BAT54.step, Cap_PTH_6_3x11x2_5mm.step, Connector_1Port_RJ45_Magjack_10-100Base-T_AutoMDIX_PoE_Wurth_Electronics-7499211002A_DigiKey-732-4976-ND.step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]
2025-06-04 Update
    Added revision M
    [ESP32-PoE-ISO_Rev_M-B_Cu.gbr, ESP32-PoE-ISO_Rev_M-B_Mask.gbr, ESP32-PoE-ISO_Rev_M-B_Paste.gbr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]
2026-01-05 adding 3d printed case
    [olimex_esp32-Poe_iso_f.stl]
2026-05-06 Update
    Added hardware revision N and updated change log
    [ESP32-PoE-ISO_Rev_N-B_Cu.gbr, ESP32-PoE-ISO_Rev_N-B_Mask.gbr, ESP32-PoE-ISO_Rev_N-B_Paste.gbr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]
2026-05-07 Update
    Added 3d design for EA variant case
    [esp32-poe-iso-ea-f_v12.stl]

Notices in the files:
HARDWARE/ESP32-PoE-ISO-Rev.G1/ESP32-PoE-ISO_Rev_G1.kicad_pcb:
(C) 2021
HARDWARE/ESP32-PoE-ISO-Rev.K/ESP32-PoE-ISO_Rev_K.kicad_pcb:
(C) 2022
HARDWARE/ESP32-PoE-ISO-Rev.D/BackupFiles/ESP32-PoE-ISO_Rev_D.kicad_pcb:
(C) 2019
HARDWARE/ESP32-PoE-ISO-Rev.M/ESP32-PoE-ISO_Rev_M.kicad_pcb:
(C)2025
